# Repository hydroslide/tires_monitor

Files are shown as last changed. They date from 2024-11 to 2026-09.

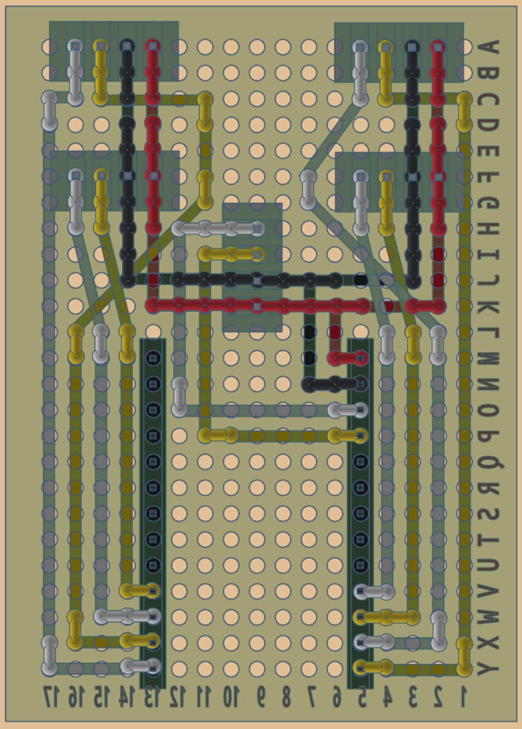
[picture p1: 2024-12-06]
circuits/i2c bottom.JPG

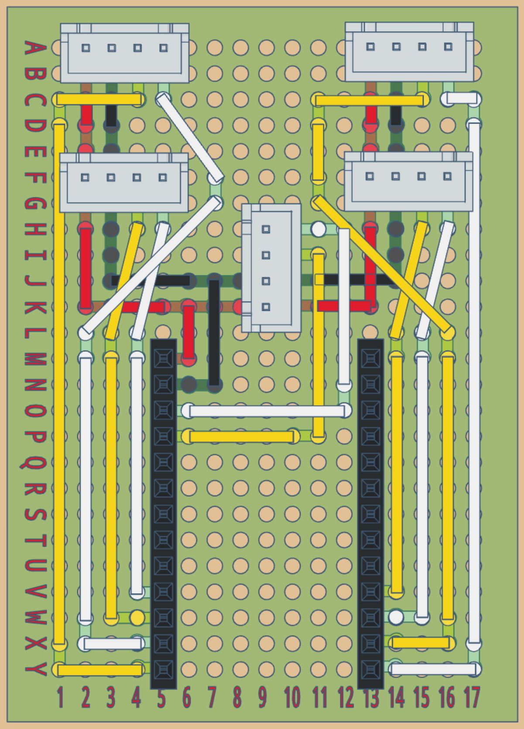
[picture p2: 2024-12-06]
circuits/i2c top.JPG

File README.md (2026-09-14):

# Tire Temperature Monitoring System

A real-time tire temperature monitoring system for performance vehicles that displays the temperature of each tire on an LCD screen using infrared temperature sensors.

## Overview

This project provides a complete solution for monitoring tire temperatures in performance driving or racing applications. It uses non-contact infrared temperature sensors (MLX90614) to measure tire temperatures and displays them on an LCD screen with color-coding based on configurable temperature thresholds.

## Features

- Real-time monitoring of all four tire temperatures
- Color-coded temperature display:
  - Blue: Cold tires (below minimum temperature)
  - Green: Normal operating temperature
  - Purple: Ideal temperature range
  - Red: Overheated tires
- Two modes: Street and Track, with different temperature thresholds
- Straight-line capture gating from the onboard IMU, with a live lateral-g bar between the
  tire rows showing the gate zone, current lateral g, and whether it's capturing
- Support for both Fahrenheit and Celsius temperature scales
- Night mode with configurable brightness (activated by right swipe gesture)
- Touch interface for menu navigation
- Configuration menu for temperature ranges, display settings, and sensor mapping
- Settings stored in EEPROM for persistence between power cycles
- Wireless communication via WiFi (ESP32 version) or Bluetooth (modular version)
- Test mode for display demonstration
- 3D printable enclosures and mounting options

## Hardware Components

- Microcontroller:
  - Waveshare ESP32-S3 Touch LCD 1.69" development board (tires_esp32 version)
    - ESP32-S3 dual-core microcontroller
    - 1.69" round LCD display (240×280 resolution) with ST7789 driver
    - Built-in CST816S capacitive touch controller with gesture support
    - 8MB PSRAM and 16MB Flash memory
    - USB Type-C interface for programming and power
    - WiFi and Bluetooth connectivity
    - I2C, SPI, and GPIO interfaces
    - Compact round form factor ideal for the project
  - Arduino/ATmega (tires_modular version)
- MLX90614 Infrared Temperature Sensors (one per tire)
- TCA9548A I2C Multiplexer (for managing multiple sensors)
- 3D printed enclosures (designs included in the 3d_parts folder)

## Directory Structure

- `/tires_esp32` - **Main implementation** using ESP32 with touch interface and WiFi
- `/docs` - Dev environment setup and build/flash guides
- `/scripts` - `tm.sh` / `tm.ps1` build helpers (compile, flash, monitor, diagnose)
- `/3d_parts` - 3D printable files for enclosures and mounting hardware
- `/circuits` - Circuit diagrams and PCB designs
- `/esp32_i2c_scanner` - I2C scanner for this board; use it to debug the sensor bus
- `/i2c_scanner` - Generic Arduino I2C scanner
- `/menu_test` - Test sketch for menu system
- `/tires_modular` - Older/simplified implementation for Arduino with Bluetooth
- `/wifi_test` - Test sketch for WiFi functionality

## Setup and Installation

### Hardware Setup

1. Assemble the hardware components according to the circuit diagrams in the `/circuits` folder.
2. Connect the MLX90614 sensors to the TCA9548A I2C multiplexer.
3. Connect the ST7789 display via SPI.
4. For ESP32 version, connect the CST816 touch controller via I2C.
5. Print and assemble the enclosures from the 3D models in the `/3d_parts/final parts` folder.

### Software Setup

#### ESP32 Version (main firmware)

Development happens in **VS Code** using `arduino-cli`. The Arduino IDE is not required.

| Guide | For |
|---|---|
| **[docs/DEV-SETUP-MACOS.md](docs/DEV-SETUP-MACOS.md)** | First-time setup on a Mac |
| **[docs/DEV-SETUP-WINDOWS.md](docs/DEV-SETUP-WINDOWS.md)** | First-time setup on Windows |
| **[docs/BUILD-AND-FLASH.md](docs/BUILD-AND-FLASH.md)** | The daily build/flash/monitor loop |
| **[docs/SETTINGS.md](docs/SETTINGS.md)** | Every menu setting — what it does, default, range, how to tune it |
| **[docs/tire-temp-functional-design.md](docs/tire-temp-functional-design.md)** | Why the tire-temp maths works the way it does (findings + amendments) |

Short version, once set up:

```bash
./scripts/tm.sh flash      # compile + upload   (~1 min)
./scripts/tm.sh monitor    # watch serial output
```

Windows: `.\scripts\tm.ps1 <same>`. Or use the status-bar buttons / `Cmd+Shift+B` in
VS Code.

The flash is verbose by default — it prints which binary it is writing and the full
esptool exchange, because that is what tells you *why* an upload failed. Turn it down
with `TM_VERBOSE=0`, or all the way up with `TM_VERBOSE=2`
([details](docs/BUILD-AND-FLASH.md#how-much-the-flash-tells-you--tm_verbose)).

Core and library versions are pinned in
[`tires_esp32/sketch.yaml`](tires_esp32/sketch.yaml) and installed automatically on the
first build — there is nothing to click through in a Library Manager. For reference, the
firmware depends on:

- ESP32 Arduino core 3.0.7 (bundles `Wire`, `SPI`, `EEPROM`, `WiFi`)
- Adafruit GFX Library, Adafruit ST7735 and ST7789 Library, Adafruit BusIO
- Adafruit MLX90614 Library (spot IR sensors), Adafruit MLX90640 (thermal cameras)
- GFX Library for Arduino
- CST816_TouchLib — supplies `CST816Touch_SWMode`, which is a class in that library, not
  a library of its own

WiFi credentials are `#define`d at the top of `tires_esp32.ino`.

#### Modular Version

1. Install the Arduino IDE.
2. Install the following libraries:
   - Adafruit_GFX
   - Adafruit_ST7789
   - Adafruit_MLX90614
   - Wire
   - SPI
   - SoftwareSerial (for Bluetooth communication)
3. Open the `tires_modular.ino` sketch in the Arduino IDE.
4. Upload the sketch to your Arduino board.

## Configuration

The system can be configured through the touch interface menu. Swipe left to access the menu and use swipe up/down gestures to navigate. Swipe left to activate a setting. Swipe up/down to increase/decrease values. Swipe right to exit the setting:

The root menu is nine items and fits the screen without scrolling. Menus are named for what
they do rather than the hardware they use, so each one groups a whole feature:

1. **Current Mode**: Choose between Street and Track modes
2. **Current Tire**: The active tire profile — the same value as `Tire Profiles → Profile`, hoisted so swapping tires is one tap
3. **Temperature**: `Source` (Raw surface vs Calculated carcass) and `Scale` (F/C). Source is a signal switch, not a display one — it changes what the device concludes, not just what it shows
4. **Mode Settings**: **Street Settings** / **Track Settings** — the per-mode default tire profile; Street also carries its own temperature window (`Override Window` + Min/Ideal/Max), and Track adds the balance and session items
5. **Tire Profiles**: The temperature window (Min/Ideal/Max), carcass offset and lag, and per-corner camera crop offsets — the profile supplies the window on Track, and in Street unless Street's `Override Window` is on. Carcass offset, lag and crop always come from the profile, in both modes
6. **Inflation & Camber**: The whole over/under-inflation and camber check in one place — the delta thresholds, the verdict latch, what gets painted, and the **Straight-Line Gate** (capture threshold, gate dwell, axis orientation) that decides which frames count
7. **Display**: Night brightness, thermal image colouring, crop guide overlay, tire redraw rate, and the fisheye **lens correction** (master switch, field of view, letterbox-vs-fit, and the interactive `Set Camera Degrees` tuner) — see [Lens correction](#lens-correction)
8. **Test**: ⚠️ *temporarily* selects the display rendering path — buffered (On) vs direct (Off). See [Display rendering](#display-rendering) below. Normally: enable the raw thermal-camera image views
9. **Save Config**: Save current settings to EEPROM

Every setting is documented — what it does, its range, and how to tune it — in
[docs/SETTINGS.md](docs/SETTINGS.md).

To activate night mode, swipe right on the main display.

### Main display views

Swiping **up/down** on the main display cycles what it shows. With the camera-image views on
(currently always — see [Display rendering](#display-rendering)) there are three states: the
tire map alone, the four live camera images, and the camera images with each tire's
temperatures drawn over the top.

**Which of those the display starts in is decided by `Current Mode`**, at boot and every time
you close the menu:

| Mode | Starts in | Why |
|---|---|---|
| **Street** | camera images with the temperatures overlaid | You're looking *at* the tires — the picture is the point, and the numbers ride along on top. Falls back to the tire map if no corner has a camera fitted, since there'd be nothing to show. |
| **Track** | the tire map alone | You're reading numbers between corners. The camera images are detail you have no time for at speed. |

This only sets the starting point. A swipe still moves the view anywhere it could before, and
that choice stands until the next time the display is rebuilt.

Sensor detection resolves a moment *after* the display comes up — a fresh `TempReader` assumes
every corner is a camera until `checkTireSensor()` proves otherwise — so on a board with no
cameras Street starts on the camera view and drops back to the tire map within a read pass or
two, once the sensors have owned up. Swiping before that happens takes the view off the
automatic default for good, and it stays where you put it until the next boot or menu close.

### Display rendering

Everything on screen is drawn through a `DisplayBase` interface with two interchangeable
implementations: **buffered** (the frame is composed into a 134 KB off-screen canvas in
PSRAM, then pushed to the panel in one burst — no flicker, no visible partial frames) and
**direct** (straight to the panel, the original behaviour, kept as an escape hatch).

**The `Test` menu item currently picks between them, at runtime, applied when you close the
menu.** That is a temporary staging measure so the two can be compared on the car by eye; it
costs `Test` its normal meaning meanwhile (the camera-image views are pinned on). Once the
buffered path is confirmed on the car, it becomes the default and `Test` goes back to what it
was.

Design notes, the flush map, and the reason the canvas is never cleared between frames are in
[tires_esp32/BufferedDisplay.md](tires_esp32/BufferedDisplay.md). The one rule worth knowing
before touching rendering code: **nothing outside the display classes may hold an
`Adafruit_ST7789&`** — on the buffered path it paints straight to the glass and is wiped by
the next flush, with no compile error.

### Aiming the cameras

The eight per-corner crop offsets decide where each camera's three temperature bands land on
the tread, and they're a pixel aim — you can only set them against the picture. **Tire
Profiles → Offsets → Set Offsets** hands the whole screen to the four live camera images with
their crop guides drawn on top and walks all eight values in one pass: the armed guide blinks,
left/right slides that line under your finger, down/up step through the values, and stepping
off either end raises a pulsing green (keep) or red (discard) border to confirm before you
leave. Corners without a camera are skipped. Edits go into the selected profile; **Save
Config** is still what writes them to EEPROM. Full gesture map in
[docs/SETTINGS.md](docs/SETTINGS.md#setting-offsets-interactively).

### Lens correction

The wide-angle MLX90640 is a ~110° lens, so straight lines bow: a tire reads as an oval and
its circumferential grooves arc like longitude lines on a globe. **That is not only a looks
problem.** The three temperature bands are fixed-width column slices, and fixed columns are
equal slices of *tire* only if the projection is linear across the width — so the
outer-vs-inner comparison behind the camber and inflation verdicts was reading bands that
didn't match the physical thirds of the tread.

Each frame is therefore re-projected to a rectilinear (pinhole) image **at the moment of
capture**, before the medians, the thermal image, NBP or balance see it — so everything
downstream inherits the fix. `Display → Lens Correct` is the master switch, and
`Display → Camera Degrees` (default `110`) is the lens's field of view.

That value is meant to be tuned by eye: **Display → Set Camera Degrees** hands the screen to
the four live camera images and puts the number under your thumb — left/right nudges by a
degree, down/down keeps, up/up discards — so you swipe until the grooves run straight and
parallel. `Display → Fit to View` chooses what happens to the top and bottom rows the
correction has no data for: black bands (off, the honest default) or squashed away to fill
the frame (on). Neither can move a measurement — the band medians only sample the middle
rows, and a boot-time self-test asserts it. Details and the tuning procedure in
[docs/SETTINGS.md](docs/SETTINGS.md#display).

## Debugging Tools

- `i2c_scanner`: Utility to scan and identify I2C devices on the bus
- `wifi_test`: Test the WiFi connection capabilities
- `menu_test`: Test the menu system functionality

## Communication Protocol

The device broadcasts its data over HP Tuners' **Numeric Broadcast Protocol (NBP)** — the
text protocol TrackAddict reads from external devices — on WiFi. Every read cycle
(10 Hz) it sends **one `UPDATEALL` packet carrying every channel it knows**: the twelve
active tire temperatures (`Front Left Tire O/C/I (degF)` …), the twelve raw surface
temperatures (`… Tire Raw …`), the IMU sample, the per-corner inflation
delta/threshold/verdict, the per-band fill and delta colors as integer `0xRRGGBB`
values, and the session-summary channels (−1 until a session is sealed). The packet
always has the same shape because an NBP client fixes its channel list on the first
`UPDATEALL` it sees; the earlier firmware sent each group as its own `UPDATEALL`, so which
columns TrackAddict logged was a race per session.

## License

This project is open source. Please respect all third-party library licenses.

## Contributing

Contributions to improve the tire temperature monitoring system are welcome. Please ensure your code follows the existing style and includes appropriate documentation.

## Credits

This project uses several open-source libraries:
- Adafruit_GFX and Adafruit_ST7789 for display functionality
- Adafruit_MLX90614 for temperature sensing
- CST816Touch_SWMode for touch interface

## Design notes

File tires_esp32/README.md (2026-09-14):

# ESP32 Tire Temperature Monitor

This directory contains the main implementation of the Tire Temperature Monitor system using an ESP32 microcontroller. This version features a touch interface, WiFi connectivity, and an advanced menu system.

## Features

- ESP32-based implementation with full touch interface
- ST7789 LCD display (240x280 pixels) 
- CST816 touch controller for gesture support
- WiFi connectivity for remote monitoring
- Menu system for configuration
- EEPROM storage for persistent settings
- Night mode with configurable brightness
- Support for both Fahrenheit and Celsius temperature scales
- Two modes (Street and Track) with different temperature thresholds

## Hardware Requirements

- Waveshare ESP32-S3 Touch LCD 1.69" development board
  - ESP32-S3 dual-core microcontroller
  - 1.69" round LCD display (240×280 resolution) with ST7789 driver
  - Built-in CST816S capacitive touch controller with gesture support
  - 8MB PSRAM and 16MB Flash memory
  - USB Type-C interface for programming and power
  - WiFi and Bluetooth connectivity
  - I2C, SPI, and GPIO interfaces
  - Compact round form factor that perfectly fits the project needs
- MLX90614 infrared temperature sensors (4x, one for each tire)
- TCA9548A I2C multiplexer (to connect multiple sensors with the same I2C address)
- 3D printed enclosure (see the `/3d_parts` directory)

## Pin Configuration

The pin configuration is defined in the `pin_config.h` file (not shown in the repository listing). Refer to the code for the specific pin assignments.

## Libraries

The following libraries are required:

- Adafruit_GFX
- Adafruit_ST7789
- SPI
- Wire
- EEPROM
- Arduino_GFX_Library
- CST816Touch_SWMode

## Core Files

- `tires_esp32.ino` - Main Arduino sketch file
- `Tire.h/cpp` - Implements individual tire display and behavior
- `Wheels.h/cpp` - Manages the layout of four tires on the display
- `TempReader.h/cpp` - Handles reading temperatures from MLX90614 sensors
- `NBPProtocol.h/cpp` - Numeric Broadcast Protocol (HP Tuners NBP, TrackAddict's device-data format): one `UPDATEALL` per read cycle carrying every channel
- `WifiSerial.h/cpp` - Provides WiFi communication capabilities
- `TireMenu.h/cpp` - Defines menu structure and configuration options
- `MenuSystem.h/cpp` - Implements the menu navigation system
- `MenuRenderer.h/cpp` - Handles drawing the menu on the display
- `TouchMenuHandler.h/cpp` - Processes touch events for menu navigation

## Menu System

The menu system allows configuration of:

1. Mode (Street or Track)
2. Temperature scale (Fahrenheit or Celsius)
3. Temperature thresholds for Street mode
4. Temperature thresholds for Track mode
5. Night mode brightness
6. Temperature sensor mapping for each tire

## WiFi Setup

The system creates its own WiFi access point:
### Incorrect info
- SSID: TireTempMonitor
- Password: esp32
- Port: 8080

## NBP IMU Telemetry

The IMU channels ride in the device's single per-cycle NBP `UPDATEALL` packet
(see the root README), alongside the tire channels, at the 100 ms sensor cadence.
Both the legacy QMI8658C sensor axes and calibrated vehicle-frame channels are
included:

- `Accel X`, `Accel Y`, `Accel Z` in `G`
- `Gyro X`, `Gyro Y`, `Gyro Z` in `deg/s`
- `Longitudinal G` and `Lateral G` in `G`
- `Yaw Rate` in `deg/s`

The packet-header timestamp applies to every channel in the packet. Boot metadata
records the IMU model, output rate, resolved longitudinal/lateral/yaw axes, and
units. Vehicle-frame channels reuse the existing stationary boot calibration and
orientation setting; the raw-axis channels remain unchanged for compatibility.

## Usage

1. Power on the device.
2. Temperatures will be displayed in color-coded format.
3. Swipe left to enter the menu system.
4. Swipe right on the main screen to toggle night mode.
5. Connect to the WiFi access point to access remote monitoring.

## Troubleshooting

If the system is not detecting temperature sensors:
1. Use the `i2c_scanner` sketch to verify sensor connections.
2. Check the I2C multiplexer wiring.
3. Verify the correct sensor indices are configured in the menu.

If the touch interface is not responding:
1. Check the I2C connection to the CST816 controller.
2. Verify the `TP_INT` and `TP_RST` pins are correctly wired.

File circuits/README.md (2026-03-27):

# Circuit Diagrams and PCB Designs

This directory contains circuit diagrams and PCB images for the tire temperature monitoring system.

## Contents

- `i2c bottom.JPG` - Bottom layer of the I2C multiplexer PCB
- `i2c top.JPG` - Top layer of the I2C multiplexer PCB

## I2C Multiplexer Board

The I2C multiplexer board is a critical component of the tire temperature monitoring system, allowing multiple MLX90614 temperature sensors (which share the same I2C address) to be connected to a single microcontroller.

### Features

- Based on the TCA9548A I2C multiplexer chip
- Supports up to 8 I2C devices with the same address
- Breakout headers for each multiplexed channel
- Address selection jumpers
- Power status LED

### Connection Guide

1. **Main I2C Bus** - Connect to the microcontroller's SDA/SCL pins
2. **Channels 0-7** - Connect to the individual MLX90614 temperature sensors
3. **Address Jumpers** - Configure to change the multiplexer's I2C address if needed
4. **Power** - Connect to 3.3V power source

### Implementation Notes

- In the tire temperature monitoring system, typically 4 channels are used (one for each tire)
- Channel mapping can be configured through the menu system in the ESP32 version
- Default sensor mapping in the code:
  - Front Left: Channel 0
  - Front Right: Channel 7
  - Rear Left: Channel 3
  - Rear Right: Channel 4

## PCB Manufacturing

If you need to reproduce the PCB:

1. Use the JPG images as reference
2. Standard 2-layer PCB with FR4 substrate
3. Minimum trace width: 8mil
4. Minimum drill size: 0.3mm

## General Wiring Guidelines

For the complete tire temperature monitoring system:

1. **Power Supply**:
   - ESP32/Arduino: 5V input
   - TCA9548A: 3.3V (use voltage regulator if needed)
   - MLX90614 sensors: 3.3V
   - ST7789 display: 3.3V logic, 5V backlight

2. **I2C Connections**:
   - Connect microcontroller I2C pins to TCA9548A input
   - Connect MLX90614 sensors to TCA9548A outputs
   - Use 4.7kΩ pull-up resistors on SDA/SCL lines

3. **Display Connections**:
   - Connect display via SPI
   - Configure CS, DC, RST pins as defined in the code

4. **Touch Controller** (ESP32 version only):
   - Connect CST816 touch controller via I2C
   - Connect interrupt and reset pins as defined in the code

## Related Files

For more details on the hardware implementation, refer to:
- `/tires_esp32/TempReader.cpp` - Shows how the I2C multiplexer is addressed in code
- `/3d_parts/final parts/I2C Hub Box.stl` - 3D printable enclosure for this PCB

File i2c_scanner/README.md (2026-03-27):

# I2C Scanner Utility

This directory contains a simple utility sketch for scanning and identifying I2C devices connected to your microcontroller. This tool is essential for troubleshooting the tire temperature monitoring system's sensor connections.

## Purpose

The I2C scanner helps with:

1. Verifying that all MLX90614 temperature sensors are properly connected
2. Checking that the TCA9548A I2C multiplexer is working correctly
3. Identifying the addresses of connected I2C devices
4. Troubleshooting connection issues with the CST816 touch controller

## Usage

1. Upload the `i2c_scanner.ino` sketch to your Arduino or ESP32 board.
2. Open the Serial Monitor at 9600 baud.
3. The sketch will scan all possible I2C addresses (1-127) and report any devices found.
4. Found devices will be displayed with their hexadecimal addresses.

## Expected Output for the Tire Temperature System

When connected to the tire temperature monitoring system hardware, you should see:

- The TCA9548A I2C multiplexer (typically at address 0x70)
- If the CST816 touch controller is connected, it should appear (typically at address 0x15)
- When testing with the multiplexer, the MLX90614 temperature sensors may appear at address 0x5A

## Testing with the TCA9548A Multiplexer

To test sensors connected through the multiplexer, you'll need to:

1. Note the addresses found with this scanner
2. Modify the `select_I2C_bus()` function in the `TempReader.cpp` file if necessary
3. Test each multiplexer channel to ensure all sensors are detected

## Troubleshooting

If no devices are detected:
1. Check your wiring connections (SDA/SCL pins)
2. Verify that pull-up resistors are present (typically 4.7kΩ)
3. Ensure devices are properly powered
4. Try a different I2C speed if available

If some devices are missing:
1. Check individual connections
2. Verify that the TCA9548A multiplexer is working
3. Ensure each sensor has a unique address or is on a separate multiplexer channel

## Code Attribution

This I2C scanner is based on commonly shared code with improvements by various contributors. The version history is documented in the comments within the sketch.

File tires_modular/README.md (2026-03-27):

# Modular Tire Temperature Monitor

This directory contains a simplified implementation of the Tire Temperature Monitor system designed for Arduino-based microcontrollers. This version uses Bluetooth for communication and does not include the touch interface or menu system of the ESP32 version.

## Features

- Arduino-based implementation with ST7789 display
- Bluetooth communication via HC-05 module
- MLX90614 infrared temperature sensors
- Fixed temperature thresholds (not configurable without code changes)
- Color-coded temperature display

## Hardware Requirements

- Arduino board (e.g., Uno, Nano, Mega)
- ST7789 LCD display (240x280 pixels)
- HC-05 Bluetooth module
- MLX90614 infrared temperature sensors (4x)
- TCA9548A I2C multiplexer (for connecting multiple sensors)
- 3D printed enclosure (see the `/3d_parts` directory)

## Pin Configuration

- TFT_CS: 10
- TFT_RST: 8
- TFT_DC: 7
- Bluetooth TX: 2
- Bluetooth RX: 3
- I2C: Default pins (SDA/SCL)

## Libraries

The following libraries are required:

- Adafruit_GFX
- Adafruit_ST7789
- SPI
- Wire
- SoftwareSerial (for Bluetooth communication)

## Core Files

- `tires_modular.ino` - Main Arduino sketch file
- `Tire.h/cpp` - Implements individual tire display and behavior
- `Wheels.h/cpp` - Manages the layout of four tires on the display
- `TempReader.h/cpp` - Handles reading temperatures from MLX90614 sensors
- `NBPProtocol.h/cpp` - Implements the Networked Binary Protocol for remote communication

## Default Configuration

This version uses fixed temperature thresholds:
- Minimum temperature: 75°F
- Ideal temperature: 85°F
- Maximum temperature: 100°F
- Temperature scale: Fahrenheit

To modify these values, edit lines 63-64 in `tires_modular.ino`.

## Bluetooth Communication

The HC-05 Bluetooth module should be configured to operate at 9600 baud rate. The system will send temperature data using the NBP protocol, which can be received by compatible applications.

## Usage

1. Power on the device.
2. Temperatures will be displayed in color-coded format.
3. Connect to the device via Bluetooth to receive temperature data.

## Differences from ESP32 Version

- No touch interface
- No configuration menu
- Fixed temperature thresholds
- No WiFi (Bluetooth only)
- No night mode
- Simplified display layout
- No EEPROM configuration storage

## Troubleshooting

If the system is not detecting temperature sensors:
1. Use the `i2c_scanner` sketch to verify sensor connections.
2. Check the I2C multiplexer wiring.

If Bluetooth communication is not working:
1. Verify the HC-05 module is properly configured (AT commands).
2. Check that the SoftwareSerial pins are correctly connected.
3. Test with a simple Bluetooth terminal app to verify connectivity.

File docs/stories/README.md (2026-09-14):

# Story drafts

User stories for the tire-temp monitor redesign, derived from
[`../tire-temp-functional-design.md`](../tire-temp-functional-design.md) and
reconciled against the driver's review notes.

Filed as GitHub issues in `hydroslide/tires_monitor` (labels `todo` + `bug`/`enhancement`).

## Global constraints (apply to every story)

- **Track-mode only — _partially superseded, see below._** As originally written, every feature here was enabled only in the menu's **Track** mode (`currentMode == 1`, via `getCurrentModeValue()`), inert / hidden in **Street**. (This is the Street/Track `currentMode`, *not* the thermal `thermalMode`.) Excluded **07** (bug fixes apply in all modes) and the raw-logging half of **08**.

  **What actually shipped:** the master-switch framing no longer holds. Since **#14** the tire *profile* — not the mode — is the single source of truth for the temp window, K and τ in **both** modes; a mode only names its default profile. Since **#16** the **Raw/Calculated** display works in both modes too. Still genuinely Track-gated: the **inflation indicator**, the **session / balance** swipe features, and boot-metadata mode labelling. Check the code before assuming a feature is Street-inert.
- **UI/UX latitude.** Redesign menu UI/UX as needed, and fix wonky / broken / buggy behavior found along the way — note each such fix in the relevant issue (or file a new one).
- **Calculated everywhere.** When calculated mode (story 03) is enabled, the calculated (offset + smoothed) value is used for **all** temperatures, displays, and decisions system-wide — window/overheat, balance, verdict, summary. Raw is logged as a *separate* diagnostic channel set and never shown. When calculated mode is off, raw is used.
- **Persist & reload all settings.** Every menu setting — including the active tire-profile selection — is saved to EEPROM and reloaded on boot (the standard settings pattern). Any new setting these stories add follows it.
- **No laps on-device.** The device has no concept of laps (that comes from the external data logger). Session stats are whole-session aggregates.

## The slate

| File | Story | Design § | Type |
|---|---|---|---|
| [01](01-session-lifecycle-summary.md) | Session lifecycle + end-of-session summary | §5.3 | feature |
| [02](02-imu-capture-gate-latched-alerts.md) | IMU capture gate + debounced latched alerts | §5.4 | feature |
| [03](03-surface-carcass-calculated-mode.md) | Surface→carcass calculated mode (+ raw mode, always-log-both) | §5.5 | feature |
| [04](04-tire-profiles.md) | Tire profiles (window + K + τ + per-corner baseline) | §5.5 | feature |
| [05](05-fr-lr-thermal-balance.md) | Front/Rear & Left/Right thermal balance | §5.2 | feature |
| [06](06-demote-gate-inflation-verdict.md) | Gate & latch the inflation verdict | §5.1 | feature |
| [07](07-correctness-bugs.md) | Correctness bugs (firmware §3.1) | §3.1 | bug |
| [08](08-nbp-instrumentation-segment-colors.md) | NBP instrumentation channels + segment colors | firmware | feature |

## Suggested order (dependencies, not mandate)

1. **07 — correctness bugs** first. Data-integrity (the C-vs-F filter bug may have
   corrupted logs) and the "byte can't store 0" bug **blocks** the profile baselines.
2. **02 — IMU capture gate**. Foundational; the gate + latched over/under drive 06.
3. **03 — calculated mode** + **04 — tire profiles** together (profiles hold K/τ/baseline).
4. **05 — balance** (uses the calculated working temp).
5. **01 — session summary** (uses window / time-in-window / balance).
6. **06 — gate & latch verdict** (folds into 02's gate + latch).
7. **08 — instrumentation** (can run in parallel; also carries IMU + summary NBP streams).

## Template

Each file: user story · context · functional behavior · menu/settings · acceptance
criteria · implementation notes. Functional level — no code.

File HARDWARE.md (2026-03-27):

# Hardware Configuration Guide

## Main Board: Waveshare ESP32-S3 Touch LCD 1.69"

The tire temperature monitoring system uses the Waveshare ESP32-S3 Touch LCD 1.69" as the main controller board. This compact, all-in-one development board is ideal for this project due to its integrated display, touch controller, and powerful microcontroller.

### Specifications

- **Microcontroller**: ESP32-S3 dual-core processor
- **Display**: 1.69" round LCD (240×280 resolution) with ST7789 driver
- **Touch Controller**: Built-in CST816S capacitive touch controller with gesture support
- **Memory**: 8MB PSRAM and 16MB Flash
- **Connectivity**: WiFi 802.11 b/g/n and Bluetooth 5 (LE)
- **Interface**:
  - USB Type-C for programming and power
  - I2C, SPI, UART interfaces
  - Multiple GPIO pins
- **Power**: 5V via USB-C
- **Form Factor**: Round PCB that perfectly fits the project's 3D printed case

## Temperature Sensors

The system uses MLX90614 non-contact infrared temperature sensors to measure tire temperatures.

### Specifications

- **Type**: MLX90614 Infrared Thermometer
- **Interface**: I2C
- **Temperature Range**: -70°C to 380°C object temperature
- **Accuracy**: ±0.5°C
- **Resolution**: 0.02°C
- **Field of View**: 90° (standard version)
- **Default I2C Address**: 0x5A (all sensors share the same address)
- **Supply Voltage**: 3.3V

### Connection Setup

Since all MLX90614 sensors share the same I2C address (0x5A), a TCA9548A I2C multiplexer is used to connect multiple sensors:

1. All sensors connect to the TCA9548A multiplexer
2. The multiplexer connects to the ESP32-S3 board via I2C
3. Temperature readings are taken sequentially by selecting different channels on the multiplexer

## I2C Multiplexer

### Specifications

- **Type**: TCA9548A 8-channel I2C multiplexer
- **Interface**: I2C
- **Default Address**: 0x70 (configurable via jumpers)
- **Channels**: 8 independent I2C buses
- **Supply Voltage**: 3.3V

### Connection Diagram

```
ESP32-S3 Board (I2C) ---> TCA9548A Multiplexer --+---> MLX90614 (Front Left)
                                                 |
                                                 +---> MLX90614 (Front Right)
                                                 |
                                                 +---> MLX90614 (Rear Left)
                                                 |
                                                 +---> MLX90614 (Rear Right)
```

## Power Requirements

- **ESP32-S3 Board**: 5V via USB-C connector
- **I2C Devices**: 3.3V (provided by the ESP32-S3 board)
- **Total Power Consumption**: ~150mA during normal operation

## Assembly Notes

1. **Display Orientation**: The LCD is oriented in landscape mode (rotation 3 in the code)
2. **Sensor Placement**: Each MLX90614 sensor should be mounted in a position where it has a clear line of sight to the tire sidewall
3. **Wiring**: Use shielded cables for I2C connections to minimize interference
4. **Enclosure**: The 3D printed parts in the `/3d_parts/final parts/` directory are designed specifically for this hardware configuration

## USB Connection

The ESP32-S3 board connects to a computer via USB-C for:
- Programming (uploading code)
- Serial debugging (9600 baud)
- Power supply

## Troubleshooting Hardware Issues

### Common Problems

1. **No Temperature Readings**:
   - Check I2C connections
   - Verify multiplexer address (should be 0x70)
   - Use the `i2c_scanner.ino` utility to detect connected devices

2. **Touch Not Responding**:
   - Check CST816S initialization in the code
   - Verify the touch settings match the display orientation

3. **Display Issues**:
   - Verify SPI connections
   - Check display initialization parameters in the code
   - Ensure proper power supply

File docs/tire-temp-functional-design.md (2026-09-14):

# Tire-Temp Monitor — Functional Design & Findings

**Status:** supersedes the core conclusion of [`tire-temp-algorithm-recommendations.md`](tire-temp-algorithm-recommendations.md).
**Grounded in:** offline analysis of the logged track data — Lime Rock Park June 17 & July 16 2026 (Continental **ECF** 225/40-17, the subject tire) and Thompson Speedway May 21 2026 (Continental **EC02** 205/45-17, the control) — plus a three-front literature review of motorsport tire-temp practice.
**Scope:** what the product should *do* and *show*, and why. Functional/product level, not code.

The recommendations doc hypothesized a uniform **+15 °F center-hot pedestal** pinning every corner to OVER. **The data refutes that.** There is no uniform pedestal; the cross-tread spread the firmware keys on is measuring **cornering load and body roll, not inflation pressure.** This document records what the data actually showed, reconciles the surface-vs-carcass physics, and lays out a functional redesign that points the hardware at what it is genuinely good at: warm-up window, overheating, and thermal balance.

---

## 1. Purpose

The monitor reads four MLX90640 thermal cameras (one per corner), splits each tire into Outer / Center / Inner bands, and today infers over/under-inflation from the center-vs-shoulder temperature spread. The driver reported the **left tires pinning OVER** at Lime Rock and dropped pressure in response — which made the car worse. This document explains why, using the logged data, and specifies the redesign.

Sign convention used throughout (matches `ThreeSectionTire.cpp`):

> **delta = avg(Outer, Inner) − Center.**
> **delta < 0 → center hotter → OVER-inflation. delta > 0 → shoulders hotter → UNDER-inflation.**

---

## 2. Executive summary

- **Everything new is gated to "Track" mode.** The whole redesign activates only when the menu mode is **Track** (`currentMode == 1`); in **Street** mode the new capture, gating, alerts, summary, and calculated-display behavior stay inert and their menu items hidden, so the everyday street display is unchanged.
- **The spread measures LOAD, not pressure.** Under cornering load the left-tire spread balloons to ~−18/−19 °F center-hot; on straights it sits near −3/−6 °F. The verdict tracks how hard the tire is working, not how much air is in it.
- **The OVER pin is a mid-corner body-roll geometry artifact.** As the car rolls and steers, the camera's crop bleeds onto cooler sidewall, manufacturing center-hot that scales with lateral g. It is *opposite* to real load physics (a loaded outside tire should read outer-shoulder-hot).
- **The metric is pressure-blind.** Raising hot pressure 28.5 → 31 psi — a change the driver clearly felt (mushy → good) — moved the spread by **≤0.5 °F**.
- **The device's advice was backwards.** It called the lefts OVER; the tire actually wanted *more* pressure. Acting on it (dropping to 28.5) made the car mushy/slidy.
- **Surface ≠ carcass.** The camera reads skin temperature, which runs **10–40 °F cooler** than the carcass a needle probe reads and spikes/decays far faster. Published windows (e.g. ECF 160–200 °F) are carcass-frame; comparing raw surface numbers to them makes tires look permanently cold — and may hide genuine overheating.
- **Repurpose the tool** for the two things real-time IR uniquely does — **warm-up / operating-window** and **overheat** detection — plus **front/rear & left/right thermal balance**. Demote the live inflation verdict.
- **The IMU lateral-g gate is the mechanism-specific fix.** Because the artifact is tightly coupled to lateral g, suppressing inflation reads while cornering removes ~24 of the −27 °F and leaves the honest ~−3 °F straight-line residual.

---

## 3. What the data showed

Analysis scripts live in the **`tires_data`** repo: `analyze_spread.py`, `analyze_corner_load.py`, `analyze_corner_exit.py` (parser `racerender.py`, lap slicing `isolate_lap.py`). All read the TrackAddict CSV exports, which merge the monitor's NBP tire channels with GPS, lateral g, and speed on one timebase. **RR is excluded everywhere** (unreliable hardware, per the driver).

### 3.1 Straight-line residuals (the honest inflation read)

At the *good* pressure (31 psi), warm, straight, steady frames only:

| Corner | Straight-line delta | Reading |
|---|---|---|
| FL | ≈ −3 °F | ~neutral / very mild center-hot |
| RL | ≈ −6 °F | mild center-hot (its per-corner baseline) |
| FR | ≈ +4 °F | mild shoulder-hot (slightly under) |
| RR | ~0 | discounted (hardware) |

These are modest and mixed — **nothing here says "drop pressure."** And because surface IR over-reports center-hot (§4), the true carcass picture is even more shoulder-biased, i.e. consistent with "31 psi felt good."

### 3.2 Load balloons the spread; pressure does not move it

`analyze_corner_load.py`, split by lateral g (left tires load in right-handers, `Accel Y < −0.6`):

| Corner | Straight | Loaded @ 28.5 | Loaded @ 31 | Move for +2.5 psi |
|---|---|---|---|---|
| FL | −2.5 | −19.5 | −19.0 | **+0.5** |
| RL | −6.5 | −17.5 | −18.0 | **−0.5** |

The load effect is ~15 °F; the pressure effect is ~0.5 °F. The tool is a load gauge.

### 3.3 The firmware verdict, reproduced

`analyze_spread.py` reproduces the device rule exactly (int rounding, 10 %/15 % thresholds) over warm, moving frames:

| Corner | ECF OVER-verdict rate | Note |
|---|---|---|
| FL | ~26–27 % (up to **30 %** on one hot lap) | reads OVER |
| RL | ~28–29 % (up to **38 %** on one hot lap) | reads OVER (worst) |
| FR | OVER 0 %, UNDER 5–6 % | reads the *opposite* of the lefts |

Lime Rock is 6-of-7 right-handers, so the left tires are loaded most of the lap → the OVER verdict is on most of the lap. That is the reported pin, mechanistically explained.

### 3.4 Corner-exit event-triggered average — the artifact isolated

`analyze_corner_exit.py` smooths the (shaky-mount, noisy) lateral-g channel, detects ~75 hard right-hander exits per session, and averages the spread around each exit (t = 0 at exit):

| Phase | t vs exit | FL center-hot delta |
|---|---|---|
| Mid-corner, peak lateral g | −2.2 s | **−27 °F** (max) |
| Straightening | −0.2 s | −15 |
| Exit (g ≈ 0) | +0.2 s | −11 |
| Onto the straight | +0.8 s | −5 |
| Steady straight | +1.5 s | **−3** (baseline) |

Findings:

- The center-hot **peaks mid-corner at peak lateral g and decays monotonically through the exit** to the straight-line baseline ~1.5 s after the car is straight. **There is no exit spike** — the "shoulders shed at exit" transient hypothesis is not what drives it.
- It **tracks lateral g with ~0.5 s lag** → a body-roll/steer geometry artifact (crop bleeding onto sidewall at roll angle), which vanishes when the body returns level.
- It is **opposite to real load physics**: a loaded outside tire should read *outer-shoulder-hot*; reading strong *center*-hot instead is the tell that the measurement is geometrically compromised.
- It is **pressure-independent** (28.5 ≡ 31, both corners, both sessions).
- A small **~1 s tail** after straightening is consistent with camera latency and/or a minor real shoulder-cooling component — so the driver's physical intuition is present, just not dominant.
- **Perception reconciled:** the alert is latched on through most of the corner and releases ~0.2 s after straightening — exactly when the driver first has a moment to glance at the dash. "I only saw it briefly coming out of corners" is real; the *alert* wasn't brief, the *chance to look* was.

### 3.5 Control tire

On the EC02 at Thompson the left-side bias largely disappears (FL −3.5 → −1.5, RL −8 → −2.5; OVER-rate 26–28 % → 2–5 %). Consistent with a tire-specific component, **but confounded by the different track** (Thompson has a different corner balance), so most of the gap is likely load/track rather than tire. Re-run the load split on a like-for-like track before crediting a purely tire-specific pedestal.

---

## 4. Physics: surface vs carcass, and the two-regime rule

Three independent literature threads converge on why a surface camera disagrees with the classic pit-lane needle method.

**Surface ≠ bulk, and grip lives in the bulk.** A needle probe reads compound temperature 3–5 mm down — the hysteretic heat that correlates with grip. IR reads only the skin, which "fluctuates rapidly with dynamic loading" and is *"badly correlated with grip,"* while the core "changes at a much slower rate" ([MegaRide](https://www.megaride.eu/press/tire-thermal-model/); [Izze Racing white paper](https://www.izzeracing.com/ewExternalFiles/Izze_Racing_White_Paper_Tire_Temperature.pdf)). Corner-by-corner spikes are a surface phenomenon the carcass never sees.

**IR reads cooler, edges worst.** Surface IR reads **10–40 °F cooler** than a probe, and *"the edges cool fastest"* ([Speedway Motors](https://www.speedwaymotors.com/the-toolbox/pyrometers-probe-vs-infrared/29996); [Prisma Electronics](https://prismaelectronics.com/blogs/tire-lab/how-to-measure-tire-temperature-in-motorsport-infrared-pyrometer-vs-needle-probe)). This is largely a *timing/cooling* effect: read instantly and statically the two agree to ~0.3 °C, but the shoulders shed heat to the airstream in the seconds after the contact patch — a **built-in center-hot bias** independent of load.

**Roll/steer crop-bleed.** A chassis-mounted sensor cannot see the contact patch; it sees tread that has rotated up and out. Under steer/roll the outer channels *"bleed into the sidewall … when steering angle is applied"* ([Texense](https://www.gomuchfaster.com/products/irn4c-f1-200-c-ir-tire-temp-sensor)), and curved shoulders viewed obliquely read low because directional emissivity falls past ~30–40° off-normal ([Optris](https://optris.com/us/knowledge-library/emissivity/)). This is the mechanism our corner-exit data fingerprinted.

**The two-regime rule (the practical upshot):**

| Regime | Tire state | What the center-vs-shoulder delta means | Trust it? |
|---|---|---|---|
| **Straight / flat / steady** | square, even load | inflation (center-hot = over, both-edges-hot = under) | **Yes** — this is the inflation regime |
| **Mid-corner / rolled** | on the outer edge | camber signal + roll/geometry artifact | **No** — do not read inflation here |

The classic Inner/Center/Outer matrix is confirmed valid ([JOES Racing](https://www.joesracing.com/tires-temperatures/): *"the middle temp is your pressure gauge and the inner-to-outer delta is your camber gauge"*; [949racing/Supermiata](https://949racing.com/supermiata/tech-info/supermiata-using-a-tire-pyrometer/); [Northstar Motorsports](https://northstarmotorsports.com/pages/tech-tips-understanding-tire-temperatures); [Autosport Labs](https://www.autosportlabs.com/using_tire_temperatures_for_better_grip_and_faster_lap_times/)) — **but it is a needle/bulk, tire-read-flat methodology.** Applied to surface IR mid-corner it inverts, which is exactly how the driver got misled.

---

## 5. Functional design

### 5.0 Global constraints (apply to every feature below)

**Track-mode gating.** Every feature in this section is enabled **only in the menu's "Track" mode** (`currentMode == 1`, read via `getCurrentModeValue()`; the other mode is "Street"). In Street mode the new behavior is inert and its menu items hidden or disabled, so the everyday street display is unchanged. **Track mode is the single master switch for this redesign.** (This is the Street/Track `currentMode` — distinct from the thermal-display `thermalMode`, which is a separate setting.)

**UI/UX latitude.** The hand-built menu, touch handling, and display have rough edges. The implementer has explicit latitude to redesign menu UI/UX where it serves these features and to fix wonky, broken, or buggy behavior found along the way — record any such fix in the relevant issue (or file a new one) so it stays tracked.

### 5.1 (a) Inflation verdict — demoted

- **Off by default.** The segment-delta indicator is already a menu toggle; keep it off.
- If used at all: **straight-line-gated** (only computed when the IMU says the car isn't cornering, §5.4), presented as a **between-session hint**, never a live in-corner directive.
- The capability is retained for data/diagnostics, not for telling the driver to change pressure in the moment.

### 5.2 (b) Front/Rear & Left/Right balance

Balance compares each tire's **working temperature** (the smoothed/calculated value of §5.5, not raw spiky surface) across two pairings:

| Pairing | Compare | Interpretation |
|---|---|---|
| **Front / Rear** | avg front vs avg rear | fronts hotter → understeer; rears hotter → oversteer |
| **Left / Right** | avg left vs avg right | expected lopsided at a directional track (Lime Rock loads lefts); flags the *unexpected* (corner-weight, brake bias, one-side abuse) |

- **Show the pair, not just the delta** — absolute levels matter (fronts +15 °F with everything in-window ≠ fronts +15 °F with cold rears).
- **Exclude RR** from the averages so its bad hardware doesn't poison the numbers.
- Primarily a summary/between-session readout; an optional coarse live front/rear bias arrow is a nice-to-have.

### 5.3 (c) Session-end summary

A per-corner recap, menu-accessible, readable while stationary, roughly current font size.

- **Layout:** a 2×2 car map (FL FR / RL RR). Each cell: **peak temp** (large) + **average steady temp** (small) + **time-in-window** (color or tiny bar) + **overheat flag** (exceeded threshold, and roughly how long).
- **Session-level screen:** F/R and L/R balance (§5.2); **warm-up time** (laps/minutes until all four first reached the window).
- **Session lifecycle:**
  - **Start** — menu "Start Session" action (reliable); optional motion auto-start.
  - **End / Seal** — menu action the driver hits **at the start of the cooldown lap**; it freezes accumulation (peaks, averages, balance, time-in-window) at that instant so the cruise back and paddock idle don't dilute the stats or add a fake cooldown tail.
  - **Auto-seal backstop** — seal on sustained low speed / stationary if the driver forgets; optional "trim last N seconds" so a late press still cuts the cruise.
  - **History** — keep the last 1–3 sessions for on-device comparison (e.g. S2 vs S3).

### 5.4 (d) IMU (QMI8658C, 6-axis, I2C)

The board carries an onboard QMI8658C accelerometer + gyro. Dash-mounted, it reads the car's motion — the lateral-g signal we need.

- **Capture gate (the core use):** accumulate the inflation read **only when |lateral g| has been below a threshold for a short capture dwell** (straight and steady, not hard braking, and settled for a moment). Cornering frames are suppressed — that is where the artifact lives. Empirically this strips ~24 of the −27 °F and leaves the honest ~−3 °F baseline. The dwell (#20) exists because a bare threshold test lets the *tail* of a corner through: g drops under the threshold while the car is still unwinding and load is still shifting. It is tunable to `0` to recover the bare-threshold behaviour.
- **Visible gate state (#20):** the gate is otherwise invisible, which makes its settings untunable by observation. A lateral-g bar between the tire rows shows the zone (sized live by the threshold), the current lateral g, and whether the gate is capturing — so threshold, capture dwell, mount noise and boot axis calibration can all be judged on the car. See `docs/SETTINGS.md` → Inflation & Camber → Straight-Line Gate (the menu was called "IMU Gate" until #22).
- **Debounced, latched alerts:** during capture, accumulate signed *evidence* per corner — up while that tire reads centre-hot, down while it reads edge-hot, leaking back toward neutral at 0.75× on frames that read neither. Once a corner's score exceeds a **dwell-time** threshold, raise the alert and **latch** it; sustained contrary or neutral evidence walks it back out. Score saturates at 2× the dwell, and that headroom is the hysteresis. Replaces the flickery per-frame verdict with a stable, physically valid one, and — since #21 — one that names the corner rather than a single global verdict. This latched per-corner verdict is what colours the on-screen segment delta bars.
- **Auxiliary uses:** cornering/braking detection to know which tires are loaded (feeds balance); motion-based session auto-start; stationary auto-seal.
- **One-time orientation calibration:** learn how the box is mounted (sit still = level; drive straight + brake = forward axis), or pick axis/sign in the menu. Coarse is fine — we only need straight-vs-cornering.

### 5.5 (e) Surface → carcass "calculated" mode

The window mismatch (surface reads ~10–40 °F below the carcass-frame spec) is fixed the way the driver proposed.

- **Offset K vs window-shift — equivalent for the decision.** Adding K to the reading or subtracting K from every threshold yields the same in/out-of-window call. **Offset the reading up** for readability (the displayed number becomes comparable to published specs and the driver's mental model). **Store windows in one reference frame (carcass)** so surface numbers are never compared against carcass thresholds — the trap the tool is in today.
- **Smoothing τ = carcass thermal-inertia model.** The carcass is not just hotter, it is *slower*. A low-pass with time constant τ makes the displayed value rise and fall gradually like the carcass, killing the transient "purple" spikes that falsely read as in-window. This is a **better** overheat guard, not a worse one: genuine overheating is *sustained* and survives the filter, while a brief surface spike that doesn't move the smoothed value isn't cooking the carcass.
- **Raw vs Calculated modes (menu):** Raw = honest surface, unsmoothed (bench/debug/data). Calculated = offset + smoothed carcass estimate (driving). **Always log raw** (or raw + the active K/τ) even in calculated mode, so calibration can be re-derived offline — never discard the raw signal.
- **Calibration:** per-profile defaults + an **immediate needle cross-check** to anchor K (probe a tire center the instant you come in, diff against what the camera showed) + an **offline τ fit** from the logs. K drifts with tire/wear/speed/ambient, so it is a profile value, never one magic number.
- **Tire profiles** bundle the tire-specific values: window thresholds, offset K, smoothing τ, and (since #15) the **per-corner camera crop offsets**. Selecting a profile (ECF, EC02, …) swaps all of them at once. This is *why* ECF and EC02 read differently — they are different tires with different windows. *(The per-corner inflation baseline was also bundled here originally; it was removed in #18 — see "Amendments" at the end of this document.)*

---

## 6. Calculated τ and K (from the data)

**Smoothing time-constant τ = 15 s (range 10–20 s).** In "calculated mode" the raw surface center-temp is EMA-low-passed before display so the number behaves like the slower carcass. τ is chosen to kill corner-frequency ripple while preserving the warm-up/cooldown trend. Sweeping τ over the July-S3 log (FL/RL/FR center band, warm & moving, 0.1 s resample) and evaluating a first-order low-pass's analytic gain at a ~10 s corner cycle:

| τ | corner transient kept | warm-up lag |
|---|---|---|
| 5 s | 30 % | 5 s |
| 10 s | 16 % | 10 s |
| **15 s** | **11 %** | **15 s** |
| 20 s | 8 % | 20 s |
| 30 s | 5 % | 30 s |

τ = 15 s knocks the corner ripple to ~11 % of amplitude (no more transient "purple" flashes) while lagging a 60–120 s warm-up by only ~15 s. Below 10 s leaves too much ripple; above 20 s adds real warm-up lag for little gain. Store τ per tire profile so it can be tuned. (Intrinsic surface-cooldown τ couldn't be fit directly — these logs end while still rolling out, so there's no clean cooldown tail, and Intake Air Temp is engine-heat-soaked and unusable as the ambient asymptote.)

**Offset K = +20 °F (default, must be calibrated).** `displayed_carcass_estimate ≈ EMA₁₅(surface) + K`. K is a **literature default only** (surface reads ~10–40 °F below a needle probe; +20 is the midpoint). There is **no carcass ground truth in the logs**, so K must be anchored per tire by an immediate needle-pyrometer cross-check (probe the center hot, within seconds of pit-in; the camera-vs-probe gap at that instant is K). Seed each tire profile at +20 and refine on the first needle session; expect K to drift with tire, wear, speed, and ambient.

Computed by `tires_data/src/fit_tau.py`.

---

## 7. Next Steps

This design will be turned into GitHub stories **interactively, feature by feature**:

1. We walk the backlog (§8) one item at a time.
2. For each, a story body is drafted (problem, behavior, settings, acceptance).
3. **We pause on each story so the driver can tweak details before it is filed** — there are specific tweaks intended per feature, so nothing is filed without a review beat.
4. Stories are created only after that review.

Preconditions and mechanics:

- **`gh` is authenticated** (account `hydroslide`); the interactive story pass can run whenever the driver is ready.
- Stories will be filed as **`tires_monitor` GitHub issues** (firmware repo). GitHub Issues is not yet configured as this repo's tracker — the first pass should set that up (labels/states) before filing.
- The **`tires_data` analysis repo is published** at [`hydroslide/tires_data`](https://github.com/hydroslide/tires_data) (private) — flip to public or rename anytime.
- Story authoring happens in its own pass; the backlog below is the slate, not the filed stories.

---

## 8. Stories / Backlog (to be filled)

Story bodies are written during the interactive Next-Steps pass (§7); this is the candidate slate:

| # | Candidate story | Area |
|---|---|---|
| 1 | Session lifecycle — start / seal-during-cooldown / summary + history | §5.3 |
| 2 | IMU capture gate + debounced latched over/under alerts | §5.4 |
| 3 | Surface→carcass calculated mode (offset K + smoothing τ) + raw mode + always-log-raw | §5.5 |
| 4 | Tire profiles (window thresholds + K + τ + per-corner baseline) | §5.5 |
| 5 | Front/Rear & Left/Right thermal balance readout | §5.2 |
| 6 | Demote/gate the inflation verdict (straight-line-only, between-session) | §5.1 |
| 7 | Correctness bugs — C-vs-F validity-filter comparison, uninitialized `tj` loop var, `initialize()` from base ctor, `anySectionColorChanged` missing return, byte-can't-store-0 EEPROM, integer-division band skew, `draw()` early return, zero-as-no-data in NBP | firmware §3.1 |
| 8 | NBP instrumentation channels + segment colors for the downstream video renderer | firmware |

---

## 9. References & provenance

**Repositories**
- `tires_monitor` — firmware (this repo; branch `pressure-fix`). Classifier in `tires_esp32/ThreeSectionTire.cpp`; band extraction in `tires_esp32/TempReader.cpp`; NBP encoder in `tires_esp32/NBPProtocol.cpp`.
- `tires_data` — offline analysis (separate repo, local). Parser `src/racerender.py`; analyses `src/analyze_spread.py`, `src/analyze_corner_load.py`, `src/analyze_corner_exit.py`; lap slicing `src/isolate_lap.py`; field dictionary `FIELDS.md`; session inventory `data/manifest.yaml`.

**Data set**
- Lime Rock 2026-06-17 (ECF, 4 sessions) and 2026-07-16 (ECF, 3 sessions: S1 mixed/off-transit ~28.5–32, S2 hot 28.5 "mushy/under", S3 hot 31 "good"); Thompson 2026-05-21 (EC02 control). Source CSVs are TrackAddict exports from `~/Documents/RaceRender 3/`.

**Research sources**
- MegaRide tire thermal model — https://www.megaride.eu/press/tire-thermal-model/
- Izze Racing white paper (surface vs core) — https://www.izzeracing.com/ewExternalFiles/Izze_Racing_White_Paper_Tire_Temperature.pdf
- Prisma Electronics (IR vs needle) — https://prismaelectronics.com/blogs/tire-lab/how-to-measure-tire-temperature-in-motorsport-infrared-pyrometer-vs-needle-probe
- Speedway Motors (probe vs infrared) — https://www.speedwaymotors.com/the-toolbox/pyrometers-probe-vs-infrared/29996
- Texense IRN4C-F1 (sidewall bleed under steer) — https://www.gomuchfaster.com/products/irn4c-f1-200-c-ir-tire-temp-sensor
- Optris (directional emissivity) — https://optris.com/us/knowledge-library/emissivity/
- JOES Racing (pressure vs camber gauges) — https://www.joesracing.com/tires-temperatures/
- 949racing / Supermiata (pyrometer use) — https://949racing.com/supermiata/tech-info/supermiata-using-a-tire-pyrometer/
- Northstar Motorsports (temp interpretation) — https://northstarmotorsports.com/pages/tech-tips-understanding-tire-temperatures
- Autosport Labs (using tire temps) — https://www.autosportlabs.com/using_tire_temperatures_for_better_grip_and_faster_lap_times/
- Izze Racing / AiM live systems & display practice; GRM & Miata forums for hot-pressure targets (see conversation research log).

---

## Amendments (post-implementation)

This document records the original design and the data analysis behind it. The findings
above still stand; the items below are where **shipped behavior deliberately diverges**
from what the design proposed. Read these before treating any statement above as current.

### #14 — the tire profile is the single source of truth for the window, in both modes

The design assumed Street and Track each carried their own Min/Ideal/Max. They no longer
do. Each *mode* now names a **default profile** (Street → EC02, Track → ECF) and the active
profile supplies the window, K and τ. The active selection is transient: it is resolved
from the current mode's default at boot and re-snapped on every mode change, and is never
persisted. Seed windows were retuned at the same time: **ECF 120/160/200, EC02 110/140/170**.

> **Partly superseded by #27** — the profile is still the single source of truth for the
> window on **Track**, and for K, τ and crop in *both* modes. Street can now override the
> window. See below.

### #27 — Street takes its window back (Track keeps the profile's)

#14 above was right that two windows for the same tire is redundant — on track. Street is a
different problem and #14 over-generalised. A track window is part of what you are *tuning*,
so it belongs with the tire; a street window is a fixed "are these anywhere near warm"
scale that has to stay put while you swap between profiles that are all tuned for track
heat. Pinning it to a profile left only bad options: edit a profile's window and wreck it
for track use, or keep a decoy "street" profile whose K/τ/crop you did not actually want.

So **Street Settings** regains **Min / Ideal / Max**, defaulting to the pre-#14 Street
window (**40/120/160**, F-seed, unchanged), plus an **Override Window** toggle. With the
toggle on and Current Mode = Street, that window replaces `TireProfiles::active().window*`
everywhere it is consumed. With it off, Street falls back to the profile — exactly the
post-#14 behavior — so the two can be compared without retyping numbers. Track is untouched.

**Only the window moves.** K, τ and the per-corner camera crop offsets still come from the
active profile in both modes, because nothing else carries them — which is why Street's
*Default Profile* still does real work with the override on.

One resolver, `resolveTireWindow()` in the sketch, decides this; both `initializeSystem()`
(thermal thresholds + the `Wheels` tire map) and `sendBootMetadata()` go through it, so the
window NBP reports cannot drift from the one on screen. A session inherits it for free via
`wheels->min/ideal/maxTemp` — though in practice sessions stay Track-only.

### #16 — Calculated display is available in both modes

The design (and the stories' global constraint) treated calculated mode as Track-only.
Since both modes now resolve K and τ from the active profile, the calc path has everything
it needs in Street too, and the mode gate was an artificial restriction. The **Display**
(Raw/Calculated) setting appears under both Street Settings and Track Settings and is one
shared global value, not a per-mode setting.

Still genuinely Track-only: the inflation indicator, the session/balance swipe features,
and boot-metadata mode labelling.

### #18 — the per-corner inflation baseline was removed

§3.1's measured straight-line residuals (FL ≈ −3, RL ≈ −6, FR ≈ +4, RR ~0 at 31 psi) are
**retained as data** — the measurement was sound. What was wrong was promoting them to a
per-profile calibration constant:

- **They are a track fingerprint, not a property of the car.** FL heaviest, RL next, FR
  opposite sign is Lime Rock's load pattern (clockwise; left tyres loaded, FR barely
  worked). Static camber would push FL and FR the *same* direction — these push opposite
  ways. And while §5.4's geometry artifact decays ~1.5 s after the body levels, *heat* does
  not: surface thermal constants run seconds to tens of seconds and Lime Rock's straights
  are short, so "warm, straight, steady" frames there still carry heat from the corner just
  exited. The values do not transfer to another track.
- **The artifact they appeared to correct is already gone on a straight.** Removing it is
  the capture gate's entire job (§5.4); the baseline added nothing on top.
- **There was no way to compute them** — no capture routine, 12 hand-entered numbers
  (4 corners × 3 profiles) derived from one session at one track.
- **The one genuinely static component has a better home.** A camera aimed slightly off, so
  its "center" band is not really tyre center, is real and track-independent — but that is
  an error measured in **pixels**, and #15 gave every profile per-corner crop offsets.
  Correcting it with a degrees-F offset fixes the wrong variable: wrong unit, and it shifts
  only the edge−center *delta* while leaving every displayed band temperature still wrong.

The inflation verdict now uses a plain `edge − center` spread against the Inflation Delta %
threshold, still gated to straight-line frames. **If residual cornering heat later proves to
bias the verdict, the fix is a straight-line dwell** — require N seconds continuously
straight before a frame counts — which is track-independent and needs one global number
rather than twelve per-profile ones, and extends the existing latch dwell.

### #18 — Tire Profiles menu: no `Load` / `Save Prof`

The edit buffer now follows the `Profile` selector automatically, so the manual `Load` step
is gone. It had been papering over a real bug: `MenuValueBinding` has no change-callback, so
changing the selector left the buffer showing the *previous* slot's values, and saving then
wrote them into the newly selected slot. Root **Save Settings** already commits the edit
buffer and writes all three slots, so the profile-only save was a strict subset of it.
`Reset` remains.

### #19 — every profile is live in RAM; one Save persists them all

#18 left switching profiles discarding uncommitted edits, because all the profile menu
fields pointed into a single shared working copy (`g_editProfile`) that had to be reloaded
on each switch. That was wrong: edit A → switch to B → edit B → **Save Settings** silently
lost A.

The working copy is gone. All `PROFILE_COUNT` profiles (63 bytes total) stay resident, and
the menu **re-points its bindings** at the selected slot rather than copying data into a
buffer (`retargetProfileBindings()`, driven by the same selector watcher). Switching a
profile is now purely a change of *view*: it neither discards nor commits anything, each
slot holds its own pending edits, and root **Save Settings** writes every slot at once.

Consequence: profile edits are **live immediately**, and Save Settings controls
*persistence only*. That is the same model every other menu setting already uses (live
globals, written to EEPROM on save), so the profile fields are now consistent with the rest
of the menu rather than special. `TireProfile`'s layout is unchanged, so this needed no
`PROFILE_MAGIC` bump and preserved saved profiles.

### #31 — the three bands are sliced out of a *rectilinear* frame, not the raw one

§5 and §3 describe the Outer / Center / Inner bands as three fixed-width column slices of
the 32×24 camera frame. That is still how the slicing works, but the statement was
incomplete in a way that mattered: **fixed columns are equal slices of *tire* only if the
projection is linear across the width, and on this hardware it is not.**

The MLX90640 in this rig is the wide-angle part — a ~110° × 75° lens, which is nowhere near
rectilinear. Straight lines in the world are not straight in the frame: a tire renders as an
oval and its circumferential grooves bow outward like longitude lines on a globe. Under that
distortion the centre of the frame is angularly compressed and the edges are stretched, so
the three fixed-width column bands were **not** landing on the physical thirds of the tread.
The centre band was reading a wider swathe of tire than it should and the shoulder bands a
narrower one — which biases the `edge − center` spread that the inflation verdict is built
on, and the outer-vs-inner comparison behind the camber call, in a way no amount of crop-
offset aiming can remove. Aiming moves *where* the bands sit; it cannot change the fact that
equal pixel widths were unequal tire widths.

Every frame is now re-projected to a rectilinear (pinhole) image at the moment of capture —
inside `TempReader::readFrame()`, immediately after the horizontal flip and **before**
`getSectionMedians()`, `fillTireFrame()`, or anything else touches it. So the medians, the
thermal image, the NBP channels and the balance readout all derive from a frame in which a
straight line is straight and equal column widths *are* equal slices of tread. One insertion
point; no consumer needed changing.

Two things worth carrying forward:

- **The correction is calibrated, not assumed.** The lens is modelled as an equidistant
  (`f-theta`) fisheye whose field of view spans the 32-pixel width, and that field of view is
  a menu setting (`Display → Camera Degrees`, default 110°) with an interactive on-car tuning
  mode, because the real lens is not exactly equidistant and the datasheet figure is not
  exactly what the optics do. The number is found by swiping until the grooves look straight.
  See [`SETTINGS.md`](SETTINGS.md#display).
- **Preserving the horizontal field of view was a deliberate constraint, not a convenience.**
  The re-projection keeps the left and right edges viewing the same angles they always did
  (the scale works out to exactly 1.0 there), which is what allows the eight per-corner crop
  offsets from #15 to survive the change. Any other framing choice would have silently
  invalidated all of them, on every profile — and those are a hand-aimed calibration with a
  whole interactive mode built to set them.

The cost is confined to the top and bottom rows, which want scene content from beyond what
the sensor captured; they are either painted black or squashed away depending on
`Display → Fit to View`. Neither outcome can reach a measurement: `getSectionMedians()` reads
**rows 10–12 only**, and a boot-time self-test (`TempReader::lensSelfTest()`) asserts that no
invalid pixel lands in those rows at any field of view the menu can reach, in either mode.

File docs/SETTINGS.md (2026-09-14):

# Settings reference

Every menu setting on the device: what it is, where it lives, its default and range, **what
it's for**, and how to tune it. If you can't remember why a setting exists, this is the file
to read — the design rationale behind the tire-temp maths lives in
[`tire-temp-functional-design.md`](tire-temp-functional-design.md).

Kept current as part of finishing a feature (see `CLAUDE.md`) — if you change a setting in
firmware, change the row here in the same commit.

---

## How settings are stored

**Edits take effect immediately; `Save Config` makes them survive a reboot.** Every setting
is a live variable the menu writes straight into. The root-level **`Save Config`** item is
what writes them to EEPROM. Change something, back out of the menu, and it applies right
away — but power-cycle without saving and it reverts.

`Save Config` writes **everything at once**: all the menu settings *and* all three tire
profiles. You can edit profile A, switch to B, edit B, then save once and both persist.

Two independent "have these ever been written" magic bytes guard the EEPROM. **When either
is bumped in firmware, that whole group resets to defaults on the next boot** — this is
deliberate, and it's why a flash sometimes wipes your settings:

| Group | Magic | Bumped when |
|---|---|---|
| Menu settings | `SETTINGS_MAGIC`, currently `0xAA` | a setting moves address or changes meaning, **or a new setting claims an address no earlier firmware wrote** |
| Tire profiles | `PROFILE_MAGIC`, currently `0x5D` | the `TireProfile` struct layout changes |

> `SETTINGS_MAGIC` went `0xA7` → `0xA8` in #20, which added *Gate Dwl 0.1s* and *Show G Bar*
> at EEPROM 32 and 33. Those addresses were never written by earlier firmware, and the
> loader copies stored bytes in **without range-clamping** — so a stale `0xFF` at 32 would
> have loaded as a 25.5 s capture dwell. The bump forces a clean re-seed instead. **Expect
> every menu setting to reset once on the first boot after that flash.**

> `0xA8` → `0xA9` in #27, which gave Street its own window and claimed the last four bytes
> #14 freed: EEPROM 10, 14, 16 and 18. Same hazard in its most literal form — those bytes
> still hold a *pre-#14* save's `streetMax` / `trackMin` / `trackIdeal` / `trackMax`, so
> without the bump a stale `trackMax = 180` at 18 would have loaded as *Override Window =
> On* and a stale `trackMin = 100` at 14 as the Street *Ideal*: plausible-looking numbers
> nobody typed. **Expect every menu setting to reset once on the first boot after that
> flash.**

> `0xA9` → `0xAA` in #31, which added the three lens-correction settings at EEPROM 34, 35
> and 36. Same hazard, but here the stale byte is *actively dangerous* rather than merely
> wrong: an uncleared `0xFF` at 34 loads as a **255° field of view**, and the re-projection
> degenerates as the field of view approaches 180°. The bump forces a clean re-seed.
> **Expect every menu setting to reset once on the first boot after that flash.**

> **#22 did not bump it.** The menu restructure moved and renamed a lot of items, but an
> EEPROM address lives on the *binding*, not on the item's position in the tree — so
> re-parenting a setting moves nothing, and every saved value survived. Deleting the dead
> *Temp Sensor Indices* simply dropped addresses 20/22/24/26 out of the save/load tree walk;
> the stale bytes are inert because nothing reads them.

**The active tire profile is deliberately not saved.** On boot it's set to the current
mode's *Default Profile*. See [Tire Profiles](#tire-profiles).

---

## Root menu

Nine items against a nine-row viewport — it fills the screen exactly and does not scroll.
That leaves **no headroom**: a tenth root item brings the scrollbar back, so anything added
later has to displace something or nest.

Everything here is grouped on one rule, adopted in #22: **no menu is named after the
hardware it happens to use.** That is why `Camera Settings`, `IMU Gate` and
`Hardware Settings` no longer exist — two of them held settings that had nothing to do with
the named part, and the third held nothing that worked.

| Setting | Default | Range | What it's for |
|---|---|---|---|
| **Current Mode** | `Street` | Street / Track | Master mode switch. Selects which *Default Profile* is adopted, and enables the Track-only features (straight-line capture gating and the per-tire inflation verdict, session recording, balance readout). Changing it immediately re-snaps the active tire profile. It also decides **which temperature window is in force**: Track always uses the active profile's, Street uses its own if `Street Settings → Override Window` is on. Finally it picks **which view the main screen starts in** — Street starts on the camera images with the temperatures over the top (when a camera is fitted), Track on the tire map alone. That applies at boot and every time you close the menu; swipe up/down still moves the view from there. |
| **Current Tire** | mode's default | slot 0–2 | The active tire profile, hoisted to the root so swapping tires is one tap. **This is the same value as `Tire Profiles → Profile`** — the two items share one binding, so setting either moves both. Not persisted; see [Tire Profiles](#tire-profiles). |
| **Test** | `On` | On / Off | ⚠️ **Temporarily repurposed (#28): this selects the display rendering path.** `On` = buffered (the frame is composed off-screen and pushed in one burst — no flicker); `Off` = the original direct-to-screen path. No reflash needed; the switch applies when you close the menu. The camera-image views it used to gate are **pinned on** meanwhile, so the swipe-cycled display always has 3 states rather than 4. This is a staging measure so the two rendering paths can be compared on the car by eye — **Phase 2 decouples them, makes buffered the default, and restores the original meaning below.** <br><br>_Original meaning (returns in Phase 2):_ enables the raw **thermal-camera image** views. With it on the swipe-cycled display has 3 states (off, or all four camera images live); with it off there are 4 that cycle none → lower pair → upper pair → all four. Primarily a bench/diagnostic aid for checking a camera is aimed and reading sensibly. |

Plus the submenus below — `Temperature`, `Mode Settings`, `Tire Profiles`,
`Inflation & Camber`, `Display` — and **`Save Config`**
(see [How settings are stored](#how-settings-are-stored)).

---

## Temperature

The two global decisions about what a temperature number *is*: which signal it comes from,
and which unit it's printed in.

| Setting | Default | Range | What it's for |
|---|---|---|---|
| **Source** | `Raw` | Raw / Calculated | `Raw` gives the honest measured **surface** temperature. `Calculated` gives the estimated **carcass** temperature — the surface reading smoothed by *Carcass Lag* and offset by *Carcass Offset*. Use Calculated for driving (it's what the window thresholds are authored against); Raw for bench work and diagnosing the sensors. |
| **Scale** | `F` | F / C | Display units. Profile windows and Carcass Offset are authored in °F and converted for display, so switching scale doesn't require re-tuning a profile. Buried here because it's set once and never touched again. |

> **`Source` is not a display setting**, which is why it isn't under `Display`. Per
> `TempReader.h`, Calculated mode **replaces** the working section temps
> (`tireSectionTemps` / `tireTemps`) with `EMA_tau(surface) + K`, so *every downstream
> display **and decision*** runs on the carcass estimate — the inflation/camber verdict, the
> balance readout, session recording, the tile colour bands, and the primary NBP channels.
> Only the raw surface medians kept for the diagnostic channel set are untouched. Picking
> Raw vs Calculated changes what the device *concludes*, not just what it shows.

> It is also **one global byte, not a per-mode setting.** Until #22 it appeared as
> "Display" inside both Street Settings and Track Settings, which read as two independent
> per-mode values; it was always one. (It was *once* genuinely gated on Track mode — #16
> removed that, because a Calculated pick made in Street was being silently ignored.)

> **Note:** in Raw mode the displayed number is a *surface* temperature but the profile
> window is authored in the *carcass* frame, so tires will read roughly one Carcass Offset
> (~20 °F) colder than the window expects. That's inherent to Raw, not a bug.

---

## Mode Settings

Wraps the two per-mode screens. Street carries its own temperature window; Track adds the
session tooling.

| Setting | Menu | Default | Range | What it's for |
|---|---|---|---|---|
| **Default Profile** | both | Street → `EC02`, Track → `ECF` | any profile slot | The tire profile this mode adopts. Selecting a mode snaps the active profile to its default — this is how switching Street↔Track swaps the whole temperature window in one move. A manual pick in `Current Tire` or `Tire Profiles` overrides it until the next mode change or reboot. **Still matters in Street even with `Override Window` on**, because the profile is the only thing carrying Carcass Offset, Carcass Lag and the camera crop offsets. |
| **Override Window** | Street | `On` | On / Off | Whether Street uses its own `Min`/`Ideal`/`Max` below instead of the active profile's window. Off falls straight back to the profile — the post-#14 behavior — so you can A/B the two without retyping numbers. Track has no equivalent: on track the profile *is* the window. |
| **Min · Ideal · Max** | Street | `40` / `120` / `160` | 0–255 °F-seed | Street's tire temperature window, applied when `Override Window` is on. Same convention as the profile window: authored as Fahrenheit and converted for display per `Temperature → Scale`. Street is a different problem from track — it's a "are these anywhere near warm" scale, not a tuning target, and it needs to stay put while you swap between profiles that are all tuned for track heat. Pinning it to a profile meant either wrecking that profile's window for track use or keeping a decoy profile whose Carcass Offset/Lag you didn't want. Ordering (`min ≤ ideal ≤ max`) is enforced downstream by the display, not here. |
| **Show Balance** | Track | `On` | On / Off | Whether the `Balance` readout below will open. Off makes the item report that it's hidden instead. |
| **Balance** | Track | — | action | Opens the front/rear and left/right thermal balance readout. |
| **View Summary** | Track | — | action | Re-opens the last sealed session summary. |
| **Auto-Seal** | Track | `Off` | On / Off | Automatically ends (seals) a running session after a sustained stationary period — a backstop for forgetting to swipe to end. Defaults off because it detects stillness from the IMU only (there's no speed input), so it's best-effort and can fire while you're sitting in the paddock. |

---

## Inflation & Camber

**One feature, one menu.** Deciding whether a tire is over/under-inflated or running bad
camber is a single pipeline — thresholds → straight-line gate → latch → paint it — but until
#22 six of its settings lived under `IMU Gate` and three under `Camera Settings`, and not
one of those three had anything to do with a camera.

Named for the two calls it distinguishes: **edge-vs-centre** divergence is an inflation
verdict, **outer-vs-inner** is a camber one. What you actually tune sits on this screen; the
gate mechanics nest one level below.

| Setting | Default | Range | What it's for |
|---|---|---|---|
| **Segment Deltas** | `Off` | On / Off | Paints per-band verdict colour bars under each tire, showing which band tripped the inflation or camber check. Since #21 the **inflation** verdict painted here is the gate's *latched, straight-line-only* one — it no longer flickers through corners — while the alignment fallback stays instantaneous. A diagnostic overlay: the colours are always computed and always logged over NBP, this only controls whether they're painted. |
| **Show G Bar** | `On` | On / Off | Paints the live lateral-g test bar in the gap between the front and rear tires, plus the per-tire dwell bars (both described below). It's how you tune everything else in this menu, and how you confirm the boot calibration was good. Costs a sliver of screen and nothing else — leave it on unless you want the cleanest possible display. |
| **Inflation Delta %** | `10` | 0–16 % | How far **edge-vs-centre** must diverge before a tire is called over/under-inflated. The comparison is `avg(outer, inner)` vs `centre`, and the threshold is this percent *of the edge temperature* (so ~16 °F at a 160 °F edge). **Lower = more sensitive**, more false calls; higher = only flags gross deviations. |
| **Alignment Delta %** | `15` | 0–16 % | How far **outer-vs-inner shoulder** must diverge before it's flagged as an alignment (camber) issue rather than a pressure one. Same percent-of-edge basis. **Only evaluated if the inflation check didn't already trip** — inflation takes priority. Note the default of 15 sits near the 16 ceiling, so it's currently a fairly insensitive check. |
| **Latch 0.1s** | `25` (2.5 s) | 5–100 (0.5–10 s) | How long the over/under condition must persist **on already-captured frames** before the verdict latches. Stops the verdict flickering on brief noise. **Higher = steadier but slower to react.** Called *Dwell 0.1s* before #22. Unrelated to *Gate Dwell* below — see the warning there. |

### Straight-Line Gate

Called `IMU Gate` before #22 — renamed off the chip and onto the job it does. The onboard
6-axis IMU (QMI8658C) suppresses tire judgements while cornering. This exists because the
mid-corner reading is a body-roll artifact — the camera crop bleeds onto the sidewall at
roll angle, manufacturing a fake centre-hot that scales with lateral g and is *opposite* to
real load physics. Gating to straight-line frames removes roughly 24 of the 27 °F of that
artifact. Full analysis in the design doc §5.4.

These four decide which frames are allowed to count at all, so they gate the **input** to
the verdict. They're set-up values — `Orientation` especially — rather than things tuned
between sessions, which is why they sit below the thresholds rather than beside them.

> **The two dwells are still not the same thing**, and since #22 they're on separate screens
> with names that say so. **`Gate Dwell`** (here) decides when capture **starts** — how long
> the car must hold lateral g inside the zone before its readings count at all.
> **`Latch`** (parent screen) decides when a verdict **trips**, measured only over frames
> already being captured. One gates the input, the other debounces the output.

| Setting | Default | Range | What it's for |
|---|---|---|---|
| **Gate Enable** | `On` | On / Off | Master switch for straight-line gating. Off means inflation reads accumulate everywhere, including mid-corner — which is what produced the original backwards verdict. Leave on. |
| **Lateral cg** | `35` (0.35 g) | 10–100 (0.10–1.00 g) | Lateral-g threshold below which the car counts as "straight and steady" and readings are accepted. **Lower = stricter**, fewer but cleaner frames; higher lets more cornering contamination back in. Raise it only if you're getting too few captured frames to be useful. With the G Bar on, this is the width of the centre segment — turn it and watch the segment resize. |
| **Gate Dwell 0.1s** | `5` (0.5 s) | 0–50 (0–5 s) | How long lateral g must stay **inside** the zone before capture begins. Before #20 capture flipped on the instant g dropped below threshold, which let the tail of a corner — still unwinding, load still shifting — count as straight-line data. **`0` reproduces that old instant behaviour**, which makes it easy to A/B on the car. **Higher = cleaner frames, fewer of them.** Called *Gate Dwl 0.1s* before #22. |
| **Orientation** | `Auto` | Auto / X / Y / Z | Which accelerometer axis is the car's lateral axis. `Auto` picks a horizontal axis from the sensed gravity direction, preferring Y (correct for a level dash mount). Force X/Y/Z only if Auto guesses wrong on an unusual mounting angle. **Test it with the G Bar: a hard left and a hard right must push the dot in opposite directions.** |

### The G Bar

A 4 px bar in the gutter between the tire rows, with a white dot riding on it:

```
x 10 ......... 113 | 114 ..... 165 | 166 ......... 269
  RED (40%)        |  centre (20%) |   RED (40%)
                        ( o )  <- current lateral g
```

- **Red flanks** are outside the capture zone; the **centre segment** is inside it. The
  segment is drawn from *Lateral cg*, so it grows and shrinks live as you turn that setting.
  At the default 35 it spans 20 % of the bar. Full-scale deflection is ±1.75 g — derived
  from that 20 % rule, not chosen independently.
- **Centre green** = capturing right now. **Centre yellow** = not capturing, either because
  you're outside the zone or because you're inside it but still serving *Gate Dwl*.
- The dot tracks the same smoothed lateral-g value the gate itself compares against the
  threshold, so **the dot crossing the segment edge is the gate decision**, not a
  visualisation of it. Under heavy cornering the dot pegs at the end of the bar; that's
  intended.

**Calibration check.** The IMU learns its at-rest gravity vector once, at boot, and the car
must be stationary and roughly level for that to be right. With the car stopped, the dot
should sit dead centre. If it doesn't, the unit booted while rolling or on a slope — reboot
at a standstill. There is no in-menu recalibrate; a reboot is the recovery.

**Bench test: tilt it 90°.** Rolling the whole device onto its side swings gravity fully
onto the lateral axis, which is *exactly* 1.0 g of apparent lateral acceleration — a known,
repeatable input, which makes it the best bench check available.

> At ±1.75 g full scale, 1.0 g is `1.0 / 1.75` = **57 % of the way out**, or roughly
> **46 % into the red**. It does **not** peg, and it shouldn't: pegging would prove nothing,
> since every value at or above full scale looks identical. A dot that lands near 57 %
> confirms the scale factor, the bias subtraction and the lateral-axis pick are all correct.
> Tilting the other way must move it the same distance the other side.

A dot that barely moves on a 90° tilt means the IMU isn't being read or `Orientation` picked
the wrong axis. A dot that pegs means the scale is wrong.

**Noise check.** On a steady straight, watch how much the dot wanders. That wander is your
mount noise, and it sets a sensible floor for *Lateral cg* — a threshold below the noise
band will chatter the gate on and off while going straight.

### The per-tire dwell bars

`Show G Bar` also paints a thin centre-origin bar inside each tire tile, showing how much
evidence that corner has built toward an inflation verdict. Each one hugs the edge facing
the g bar — **bottom** of the front tiles, **top** of the rear ones — so all five read as a
single instrument clustered around the centre gutter rather than four strays:

```
|<------------ tile width ------------>|
[        |####|      :      |    |     ]
         ^ latch    centre   ^ latch
   cyan <- UNDER            OVER -> yellow
```

Each corner carries a **signed evidence score** in milliseconds. On captured (straight-line)
frames it grows toward OVER while that tire reads centre-hot and toward UNDER while it reads
edge-hot; a neutral frame leaks it back toward zero at 0.75× rate. Mid-corner the gate stops
feeding it, so the bar **freezes** rather than drifting. Cross a latch tick and the verdict
trips, colouring the segment delta bars above.

Two deliberate asymmetries: an *opposite* reading subtracts at full rate (it is real evidence
the other way) while *neutral* only leaks at 0.75×, and the score saturates at 2× the latch
point. That saturation is the hysteresis — a fully-committed corner needs roughly 1.3× the
dwell of neutral driving before it falls back out, so a verdict can't chatter on and off at
the boundary.

Use them to tune `Latch 0.1s`: if bars slam to a latch on one straight, the dwell is too
short; if they never get there over a whole lap, it's too long or `Inflation Delta %` is set
too tight.

---

## Tire Profiles

A profile bundles all the tire-specific calibration, so changing tires swaps everything at
once instead of re-tuning field by field. Three slots, seeded `ECF` / `EC02` / `Custom`.

**All three profiles are live in memory at all times.** Changing `Profile` only changes
which slot the fields below display and edit — it never discards or commits anything. Edit
several profiles in one visit and a single `Save Config` persists them all.

| Setting | Default | Range | What it's for |
|---|---|---|---|
| **Profile** | mode's default | slot 0–2 | Which profile is active *and* being edited. **Not persisted** — on boot it's the current mode's *Default Profile*. A manual pick holds until the next mode change or reboot. |
| **Name** | `ECF` / `EC02` / `Custom` | 7 chars | Slot name. Also relabels the choices in each mode's *Default Profile* picker. |
| **Min** | ECF 120 · EC02 110 · Custom 100 | 0–255 | Bottom of the operating window — below this the tire is cold / not up to temperature. **Carcass-frame °F.** |
| **Ideal** | ECF 160 · EC02 140 · Custom 160 | 0–255 | Target operating temperature. |
| **Max** | ECF 200 · EC02 170 · Custom 180 | 0–255 | Overheat threshold — above this you're cooking the tire. |
| **Carcass Offset °** | `20` | 0–80 °F | The surface→carcass correction. The camera reads the tire *surface*, which runs 10–40 °F cooler than the carcass a needle probe reads, and the window above is authored in carcass terms. Adding this offset makes the displayed number comparable to published tire specs. **+20 is a literature midpoint, not a measurement** — anchor it per tire by probing a tire centre with a needle pyrometer within seconds of pit-in; the camera-vs-probe gap at that instant is your value. Expect it to drift with tire, wear, speed and ambient. Only applies in `Calculated` display mode. |
| **Carcass Lag s** | `15` | 1–60 s | Smoothing time constant. The carcass isn't just hotter than the surface, it's **slower** — this low-pass makes the displayed value rise and fall like bulk rubber instead of skin, killing brief surface spikes that would otherwise flash as overheating. It's a *better* overheat guard, not a softer one: genuine overheating is sustained and survives the filter. **15 s was fitted from logged data** (knocks corner-frequency ripple to ~11 % while lagging a 60–120 s warm-up by only ~15 s). Useful range 10–20: below 10 leaves ripple, above 20 adds warm-up lag for little gain. Only applies in `Calculated` mode. |
| **Reset** | — | action | Reverts **only the selected slot** to its seeded defaults. Still needs `Save Config` to persist. |

### Offsets

`Tire Profiles → Offsets → <corner> → Left` / `Right`. Per-corner, per-side camera crop, in
thermal-frame pixel columns.

| Setting | Default | Range | What it's for |
|---|---|---|---|
| **Set Offsets** | — | action | **The way these are meant to be set.** Hands the whole screen to the four live camera images with their crop guides drawn on, and walks all eight values in one pass — see [Setting offsets interactively](#setting-offsets-interactively) below. Edits land in the selected profile in RAM; `Save Config` still persists. |
| **Left** / **Right** | `0` | 0–16 columns | How many pixel columns to crop off each side of that corner's camera frame, so the three temperature bands land on actual tread rather than sidewall, wheel or background. **This is where a mis-aimed camera gets corrected** — fixing aim here is right because it also fixes the displayed band temperatures, whereas a temperature fudge would only shift the derived delta. Kept for fine adjustment and for reading back what **Set Offsets** left behind; tuning by hand here needs **Display → Show Offsets** on so you can see the guide lines against the live image. They're per-profile because different tires and mountings want different crops; all three profiles seed identical. |

#### Setting offsets interactively

These eight numbers are a **pixel aim against a camera image**, and the numeric fields above
hide the very image you're aiming. `Set Offsets` fixes that: the menu closes, the four camera
images fill the screen with no tire map, and every crop guide is drawn on top (regardless of
the *Show Offsets* toggle, and always over the **uncropped** frame — a guide drawn on an
already-cropped image tells you nothing).

Exactly one guide is armed at a time, and it **blinks**. That's the only indicator, so the
gestures are worth knowing:

| Swipe | What it does |
|---|---|
| left / right | Slides the **armed** guide the way you swiped. The stored value moves opposite ways on the two guides — both are measured inward from their own edge, so a right offset grows leftward — but on screen the line always follows your finger. Stops at 0 (the image edge) and 16 (mid-image). |
| down | Next value. Order is fixed: FL, FR, RL, RR, and Left before Right within a corner. **Corners with no camera are skipped** — there's nothing to aim there. |
| up | Previous value. |
| down past the last value | **Green border pulses** — you're about to keep. Down again exits to this menu with the edits; up returns to the last value. |
| up past the first value | **Red border pulses** — you're about to discard. Up again exits and restores every offset to what it was on entry; down returns to the first value. |

Keeping means keeping in the **selected profile, in RAM** — exactly like typing into the
numeric fields. Nothing reaches EEPROM until root **Save Config**, so a session of aiming is
still discardable by simply not saving.

---

## Display

Mostly presentation — how bright the screen is, how the thermal image is coloured, whether
the crop guides are drawn over it, and how often the tire display repaints. This is what was
left of `Camera Settings` (#22) once the three verdict settings that were sitting in it moved
to [Inflation & Camber](#inflation--camber), plus `Night Brightness` down from the root.

**The four lens settings (#31) are the exception, and they do change numbers.** They live
here on the same "device-wide, so it lives here" rule that already put `Show Offsets` here
rather than next to the per-profile offset values — the root menu is an exact 9-of-9 fit
against the screen, so a `Camera` root submenu would have to displace something. This menu
is now 8 of 9 rows; the next item added to it should push the four lens settings into a
`Lens` submenu rather than displacing anything.

| Setting | Default | Range | What it's for |
|---|---|---|---|
| **Night Brightness** | `25` | 0–100 % | Screen brightness **while night mode is active** (swipe-toggled) — it does not affect normal daytime brightness. Percent of full backlight. Low enough not to blind you at night, high enough to still read. |
| **Thermal Gradient** | `On` | On / Off | *On* = smooth interpolated colour within each temperature band (finer detail). *Off* = one flat colour per band, so the image posterizes into cold/warm/ideal/hot blocks — easier to read *which band* a region is in at a glance. Preference, not calibration. |
| **Show Offsets** | `On` | On / Off | **This is the crop-tuning toggle, and it changes what the thermal image shows.** *On* = the **full** camera frame with vertical guide lines marking where the crop offsets sit — use this while tuning the offsets so you can see what you're cutting. *Off* = the image is cropped to the region **between** the offsets and stretched to fill the display, which is the real working view. Turn it on to tune, off to drive. It stays here rather than next to the offset values because it is device-wide, while the values are per-profile. |
| **Hi Freq Updates** | `Off` | On / Off | Recomposes the tire numbers and bars every read (~10 Hz) instead of once a second. Smoother, and useful when chasing something transient. With **Test** *On* (the buffered path) the cost is CPU only — the screen is pushed at 10 Hz either way, and this just changes how often the tire map is redrawn into the frame first. With **Test** *Off* it also multiplies SPI traffic, which is the more expensive of the two. |
| **Lens Correct** | `On` | On / Off | **Master switch for the fisheye correction (#31), and it changes measured temperatures — not just the picture.** The wide-angle MLX90640 is a ~110° lens, so straight lines bow: a tire reads as an oval and its circumferential grooves arc like longitude lines. That's not only cosmetic. The three band medians are taken over **fixed-width column bands**, and fixed columns are equal slices of *tire* only if the projection is linear across the width — it isn't, so the outer-vs-inner comparison behind the camber and inflation verdicts was reading bands that didn't match the physical thirds of the tread. *On* re-projects each frame to a rectilinear (pinhole) image at the moment of capture, so the medians, the thermal image, NBP and balance all inherit the fix. *Off* is the raw sensor frame, exactly as it behaved before #31 — keep it for A/B-ing the correction on the car. |
| **Camera Degrees** | `110` | 60–140° | The lens's field of view across the 32-pixel width, fed straight into the correction. `110` is the wide-angle part's datasheet figure and the right place to start, but the real lens isn't exactly an ideal fisheye, so **this is meant to be tuned by eye** — see **Set Camera Degrees** below. Capped at 140 deliberately: the maths degenerates as the field of view approaches 180°, and by 140 the centre of the image is already de-magnified more than 2.2×. |
| **Fit to View** | `Off` | On / Off | What to do with the rows the correction has no data for. Preserving the horizontal field of view (which is what keeps your crop offsets valid) means the corrected top and bottom rows want scene content from **beyond what the sensor captured**. *Off* = letterbox: those pixels are painted **black**, because there is genuinely nothing there and a fabricated value would render as a real reading. *On* = squash the image vertically to fill the frame instead. Lines stay straight either way — an anisotropic squash is an affine map, and affine maps preserve straightness — you only lose aspect ratio. **Neither mode can move a measurement**: the band medians only sample rows 10–12, where toggling this shifts the sampling by 0.012 px at 110° and at most 0.071 px anywhere in range. Defaults *off* so the cost of the correction is visible while you're finding the right **Camera Degrees**. |
| **Set Camera Degrees** | — | action | Opens the interactive tuning mode — the only screen that shows you the picture you're judging. Full-screen four-quadrant live thermal view, uncropped, with the current value drawn in the top margin. **Swipe left/right** = −1/+1°. **Swipe down** = pulsing green border, down again keeps. **Swipe up** = pulsing red border, up again discards and restores the value you entered with. Keeps in RAM only; root **Save Config** is still the only thing that writes EEPROM. Refuses to open (and says so) if no corner has a camera, or if **Lens Correct** is off — tuning a correction that isn't running is swiping at a raw image and wondering why nothing moves. |

### Tuning Camera Degrees on the car

Park where a tire fills a quadrant with its circumferential grooves clearly visible, open
**Set Camera Degrees**, and swipe until **the grooves run straight and parallel** and the
tire outline reads as a rectangle rather than an oval.

- Grooves still **bowing outward** (barrel — the ends curve away from centre) → value is
  **too low**, under-correcting. Swipe right.
- Grooves bowing **inward** (pincushion) → **too high**, over-correcting. Swipe left.
- Straight and parallel → done. Swipe down twice to keep, then root **Save Config**.

**Tune with Fit to View off.** The black bands are the honest running total of what the
correction is spending — 7.8 % of the frame at 110°, 14.6 % at 140° — and they grow as you
raise the value. They cost you nothing measured (the median rows are never in them), but
seeing them is what tells you to prefer the *lowest* value that actually straightens the
grooves. Turn Fit to View on once you've settled.

With Fit to View **on**, the same information shows up as vertical squash instead: the image
renders 0.855× as tall as true rectilinear at 110°, 0.661× at 140°. If the tire starts
looking squat, that's a high **Camera Degrees** being absorbed — not a sign the value is
wrong.

**Re-check the crop offsets afterwards.** The horizontal framing is preserved by
construction, so they should still be close — but "close" isn't "verified," and
[Set Offsets](#offsets) makes confirming them a 30-second job.

---

## Removed settings

Recorded so an old note or screenshot doesn't send you hunting for something that's gone.

| Setting | Was in | Removed | Why |
|---|---|---|---|
| **Temp Sensor Indices** (FL / FR / RL / RR) | Hardware Settings | #22 | Never did anything. Four editable, EEPROM-persisted bytes (20/22/24/26) with **no getter** — nothing in the firmware read them. The real sensor-to-corner mapping is a hardcoded `sensorIndices{0, 7, 3, 4}` in `TempReader`'s constructor, which these never fed. They presented as a working remap and were not one, so the whole `Hardware Settings` branch went with them. The addresses are simply no longer walked by save/load; the stale bytes are inert. |
| **Base FL / FR / RL / RR** | Tire Profiles | #18 | Per-corner inflation baselines. The shipped values encoded one track's load pattern rather than a property of the car, the artifact they appeared to correct is already removed by the straight-line gate, and any genuinely static component is a camera aim error belonging in the crop offsets above. Full reasoning in the design doc's Amendments section. |
| **Load** | Tire Profiles | #18 | Manually pulled the selected slot into the edit buffer. The edit buffer is gone (#19) — the fields now point straight at the live slot, so there's nothing to load. |
| **Save Prof** | Tire Profiles | #18 | Saved only the current profile. `Save Config` already writes all three, and a profile-only save became actively misleading once several profiles can hold pending edits at once. |
| **Track Min · Ideal · Max** | Track Settings | #14 | Track no longer carries its own window; it names a *Default Profile* and the profile supplies the window. On track that's right — the window is part of what you're tuning, and it belongs with the tire. **Street's three came back in #27** (see *Mode Settings*): street isn't a tuning target, and its window has to survive swapping between profiles that are all tuned for track heat. |
| **Inflation** | Track Settings | #21 | Gated the over/under verdict and its top-left badge. The badge is gone — it reported one global verdict, so it could say something was wrong but never which corner, and the per-tire delta bars now carry that verdict on the tire it belongs to. With the latch driving those bars, an off switch left them showing an alignment verdict but no inflation one, which reads as "this tire is fine" rather than "this check is disabled". *Segment Deltas* is the honest visibility control. EEPROM 31 is free again. |
| **Camera offset values** | Camera Settings | #15 | Moved onto the tire profile (Tire Profiles → Offsets) so they swap with the tire. The display toggles stayed global. |

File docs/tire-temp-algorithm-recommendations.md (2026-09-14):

# Tire-Temp Algorithm — Coding & Testing Recommendations

Follow-on to [`tire-temp-pressure-handoff.md`](tire-temp-pressure-handoff.md). That doc framed the problem and ranked hypotheses before anyone had read the firmware. This one is written **after** reading `TempReader.cpp`, `ThreeSectionTire.cpp`, `NBPProtocol.cpp`, `TireMenu.cpp`, and `MenuSystem.cpp`, and it **supersedes the hypothesis ranking in handoff §4**.

Scope: what to change in code, and what to test — offline, on the bench, and at the track. No code has been changed yet.

---

## 1. Corrected framing

The handoff's mental model was "the metric doesn't respond to pressure." The firmware says something sharper.

The classifier ([`ThreeSectionTire.cpp:139-151`](../tires_esp32/ThreeSectionTire.cpp#L139-L151)):

```cpp
float avgEdge = (sectionTemps[outer] + sectionTemps[inner]) / 2.0f;
float delta   = avgEdge - sectionTemps[center];          // +ve = shoulders hot = under
float minInflationDelta = avgEdge * (minInflationDeltaPct / 100.0f);
```

`minInflationDeltaPct` defaults to **10** ([`TireMenu.cpp:52`](../tires_esp32/TireMenu.cpp#L52)), and `avgEdge` is an **absolute °F** temperature. On a 150 °F tire the bar to declare over-inflation is therefore **15 °F of center-hot spread**.

It trips. Persistently. Across a 3 psi swing.

That is not a null result — it is a positive measurement. **The frames genuinely contain ≥15 °F of center-hot spread at every pressure tested.** The failure mode is not "too insensitive to see the signal," it is:

| Component | Magnitude (est.) |
|---|---|
| Structural / thermal pedestal (pressure-independent) | ~15–20 °F center-hot |
| Pressure-driven modulation (28 → 31 psi) | ~3–6 °F |
| Classifier threshold | ~15 °F |

The pedestal alone clears the bar. The pressure term modulates the total but never pulls it back under. The indicator pins to OVER and the real signal is invisible — not absent.

**This is handoff §4 hypothesis 3 (missing calibration baseline), promoted to primary.** The tool is measuring an absolute where it should measure a deviation from a per-tire zero.

---

## 2. Hypothesis ledger (revised)

### Withdrawn — errors in the earlier read of the code

- **"The crop isn't happening / offsets default to 0."** Wrong. [`TempReader.cpp:71-77`](../tires_esp32/TempReader.cpp#L71-L77) walks `leftOffset → COLS-rightOffset` and splits *that* range into thirds. Everything sampled is inside the margins. The source defaults of 0 are irrelevant because EEPROM supplies real per-corner values.
- **"The 3-row strip may drift onto the shoulder."** Wrong, and rotated 90°. Sections split by **column** (left/center/right = inner/center/outer); `useMiddleRows` takes rows 10–12, a **horizontal** strip spanning the tread. Vertical aim error moves the strip *circumferentially*, which is thermally near-uniform. Middle rows are the correct choice.

### Demoted

- **Equal-pixel vs. equal-arc-length thirds (was handoff's top suspect).** `getSectionMedians` returns a **median**, not a mean ([`TempReader.cpp:91`](../tires_esp32/TempReader.cpp#L91)). A 7-column band × 3 rows is ~21 samples; even if the outermost 1–2 columns sit on the roll-off, that is 3–6 of 21 samples in the tail and the median does not move. Arc-length weighting only matters for a mean. **Not worth building unless the bench test in §5.1 says otherwise.**
- **Emissivity at viewing angle (handoff §4.2).** At any sane mount distance the incidence angle across a 225 mm tread is ~20–30°, well inside rubber's flat ε region (falloff starts ~60°). The genuinely oblique pixels at the extreme edge are exactly the minority the median discards. Effectively dead for a roughly-normal mount; only revisit if the camera looks along the tire at a steep angle.

### Live, ranked

1. **Structural crown.** 225/40-17 on a 17x8 is at the narrow end of the tire's rim range. Tread crowns; center carries disproportionate contact pressure at *every* inflation pressure. Pressure-independent by construction.
2. **Lateral shoulder cooling** — *not in the original hypothesis list, and it belongs there.* The shoulder tread abuts the sidewall and bead, which run far cooler and conduct heat laterally out of the tread. The shoulder is also the most air-exposed part of the tread, and by the time it rotates to the sensor it has cooled more than the center. Produces a persistent center-hot **surface** profile largely independent of inflation, scaling with airflow and inversely with ambient. A cool evening session at Lime Rock in a 2400 lb car maximizes it.
3. **Threshold anchor and asymmetry.** Real defects (§3.2), but second-order — they explain ~10% distortions, not a pinned indicator.

Hypotheses 1 and 2 are **not separable from the thermal data alone** — both produce a symmetric, constant, pressure-insensitive center-hot pedestal. Separating them requires the chalk / needle-pyrometer ground truth in §5.3. Fortunately the *fix* is the same for both: subtract a per-tire baseline.

---

## 3. Code recommendations

### 3.1 Correctness bugs — fix regardless of the algorithm outcome

**(a) Fahrenheit compared against Celsius in the validity filter.** [`TempReader.cpp:173-184`](../tires_esp32/TempReader.cpp#L173-L184) converts C→F **in place, band by band**, then validates each band immediately:

```cpp
for (int j = 0; j < 3; j++) {
    float valueF = tireSectionTemps[i][j] * 9.0f / 5.0f + 32.0f;
    if (useFarenheit) tireSectionTemps[i][j] = valueF;
    if (newTempIsInvalid(i, j)) ...
}
```

The cross-band rescue inside `newTempIsInvalid` ([`TempReader.cpp:146-152`](../tires_esp32/TempReader.cpp#L146-L152)) compares band `j` (already °F) against sibling bands that have **not yet been converted** (still °C). At 65 °C / 150 °F that comparison is `|150 − 65| = 85 > MAX_STEP(30)`, so the rescue never fires for bands 0 and 1 but works normally for band 2. Result: **asymmetric rejection rates across the three bands**, worst during warm-up when temps are changing fastest, and a rejected band latches its previous value.

Fix: convert all three bands, *then* validate all three.

**(b) Uninitialized loop variable — undefined behavior.** Same function, [`TempReader.cpp:146`](../tires_esp32/TempReader.cpp#L146):

```cpp
for (int tj; tj<3; tj++){          // tj never initialized
```

Reads stack garbage; if it starts negative, `tireSectionTemps[i][tj]` indexes out of bounds. Should be `int tj = 0`.

**(c) `ThreeSectionTire::initialize()` never runs.** It is invoked from the **base** `Tire` constructor ([`Tire.cpp:12`](../tires_esp32/Tire.cpp#L12)), where the vtable is still `Tire`'s, so the empty `Tire::initialize()` executes instead of the override. `lastDeltaColors[]` and `currentDeltaColors[]` stay uninitialized. Cosmetic (does not touch classification math), but call it from the derived constructor or from the first `draw()`.

**(d) `anySectionColorChanged()` has no `return` on the fall-through path** ([`ThreeSectionTire.cpp:73-78`](../tires_esp32/ThreeSectionTire.cpp#L73-L78)). Currently harmless because nothing calls it. Delete it or fix it.

**(e) A byte setting can never be stored as 0.** [`MenuSystem.cpp:227`](../tires_esp32/MenuSystem.cpp#L227) skips loading any `VALUE_BYTE` whose stored value is 0:

```cpp
if (EEPROM.read(addr) > 0 && EEPROM.read(addr) < 255) { ... }
```

So `minInflationDeltaPct` cannot be zeroed to log raw unthresholded deltas — which is exactly what you want during calibration. Needs a separate "written" sentinel or a magic-byte scheme.

**(f) Uneven bands from integer division.** [`TempReader.cpp:76-77`](../tires_esp32/TempReader.cpp#L76-L77): for a 20-column crop the bands come out **6 / 7 / 7**; for 22, **7 / 7 / 8**. The left band is systematically narrowest. Irrelevant to the inflation metric (both shoulders are averaged) but it **biases the alignment metric**, which compares outer against inner directly. Distribute the remainder symmetrically.

**(g) `draw()` returns early from inside its own loop.** [`ThreeSectionTire.cpp:95-96`](../tires_esp32/ThreeSectionTire.cpp#L95-L96): one out-of-range band aborts the whole tire's redraw *and* the delta bar for that frame, without updating `lastTemps`. Cosmetic, but it means a single glitch frame stalls the display.

**(h) Zero is overloaded as "no data" in the NBP encoder.** [`NBPProtocol.cpp:43`](../tires_esp32/NBPProtocol.cpp#L43): `if (fl.values[1] == 0)` decides between logging one channel or three. A center band that legitimately reads 0 — or that was rejected while `lastTireSectionTemps` was still 0 during startup — silently collapses the tire to a **single** `"Front Left Tire"` channel instead of `O/C/I`. This is both a bug and a **parsing hazard for the dumps**: the channel set changes mid-file. See §4.0(e).
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

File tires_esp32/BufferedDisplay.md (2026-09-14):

# Display abstraction & buffered rendering

> Rewritten on `dev` in #28. `main` still carries the March version, which described a
> refactor that did not happen (it names `DisplayWrapper.h` and `AlternateDisplay.h` as
> renamed/replaced files — neither has ever existed in this repo's history) and omits
> several changes the commit actually made. Trust this copy.

## The problem

`Adafruit_ST7789` draws straight to the panel on every call. A frame here is many calls —
band fills, temperature text, delta bars, dwell bars, four camera blits, the g bar, the
session badge — and each one pushes pixels over SPI as it happens. You see the frame being
assembled: partial repaints, tearing, and visible flicker wherever two components overlap.

## The shape

Three classes and one interface, in `DisplayBase.h`:

| | |
|---|---|
| `DisplayBase` | The interface every rendering component draws through. Inherits `Print`, so `print`/`println` work. |
| `StandardDisplay` | Straight to the glass. The original behaviour, kept as an escape hatch. |
| `BufferedDisplay` | Composes into an off-screen `GFXcanvas16`, pushed by `drawScreen()`. |
| `DisplayProxy` | Forwards to whichever of the two is selected. It is what `display` actually is. |
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

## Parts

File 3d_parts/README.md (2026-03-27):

# 3D Printable Parts

This directory contains STL files for 3D printing enclosures and mounting components for the tire temperature monitoring system.

## Directory Structure

- `final parts/` - Latest production-ready designs
  - `display/` - Enclosures and mounting for the Waveshare ESP32-S3 Touch LCD 1.69"
- `old/` - Previous iterations and obsolete designs
  - `Display/` - Older display module designs
- `src/` - Source files for component design
- `tests/` - Test prints and prototypes

## Components

### Display Module

The display module components are specifically designed for the Waveshare ESP32-S3 Touch LCD 1.69" round development board. These parts create a protective housing and mounting system for the display unit:
- `Tire Temp Display Module 4 back.stl` - Back cover that protects the electronics
- `Tire Temp Display Module 4 front.stl` - Front bezel that secures the 1.69" round LCD
- `Tire Temp Display Module 4 middle.stl` - Middle housing that contains the ESP32-S3 board
- `Tire Temp Display Module high cup thick.stl` - Mounting cup for vehicle installation
- `Tire Temp Display Module nut.stl` - Threaded nut for secure mounting

### Sensor Boxes

These enclosures protect the MLX90614 infrared temperature sensors:
- `Tire Temp Sensor Box protection mk2.stl` - Protective case for the sensor
- `Tire Temp Sensor Lid.stl` - Lid that secures the sensor while allowing temperature readings

### I2C Hub Box

This enclosure houses the TCA9548A I2C multiplexer board:
- `I2C Hub Box.stl` - Main housing for the multiplexer PCB
- `I2C Hub Box lid.stl` - Lid that protects the multiplexer connections

### Power Input Box

Power supply enclosure for 5V regulation:
- `Power Input 5v Box.stl` - Housing for power regulation components
- `Power Input 5v Lid.stl` - Protective lid for the power supply

## Assembly Instructions

1. Insert the Waveshare ESP32-S3 Touch LCD 1.69" board into the `Tire Temp Display Module 4 front.stl` with the screen facing outward.
2. Secure the board in the `Tire Temp Display Module 4 middle.stl` housing.
3. Route the I2C and power wires through the appropriate channels and secure the back panel.
4. For each sensor, place the MLX90614 infrared sensor inside the `Tire Temp Sensor Box protection mk2.stl` and secure with the lid.
5. Mount the TCA9548A I2C multiplexer inside the I2C Hub Box and secure the lid.
6. Assemble the power input box with the appropriate power regulation components if not powering directly via the ESP32-S3's USB-C port.

## Wiring Instructions

The system uses standardized 4-pin connectors for all connections:

1. **ESP32 to Power Supply Box**:
   - Connect a 4-pin wire (5V, GND, SDA, SCL) from the ESP32-S3 board to the power supply box.
   
2. **Power Supply**:
   - The power supply box accepts power via a USB-Mini connector.
   
3. **Power Supply to I2C Multiplexer**:
   - Connect another 4-pin wire from the output of the power supply box to the input of the I2C multiplexer box.
   
4. **I2C Multiplexer to Sensors**:
   - Connect four separate 4-pin wires from the multiplexer box outputs.
   - Each wire routes to one of the four tire temperature sensors.
   - Each wire carries 5V, GND, SDA, and SCL to power and communicate with the MLX90614 sensors.
   
5. **Wire Routing**:
   - Route wires along the vehicle's existing wiring harnesses when possible.
   - Use cable ties or clips to secure wires away from heat sources and moving parts.

## Notes

- The 3D printed parts were designed specifically for the Waveshare ESP32-S3 Touch LCD 1.69" board's round form factor
- Older designs in the `old/` directory are kept for reference but are optimized for different hardware
- The `tests/` directory contains prototype designs that were used during development
- The source files in `src/` can be modified if customization is required

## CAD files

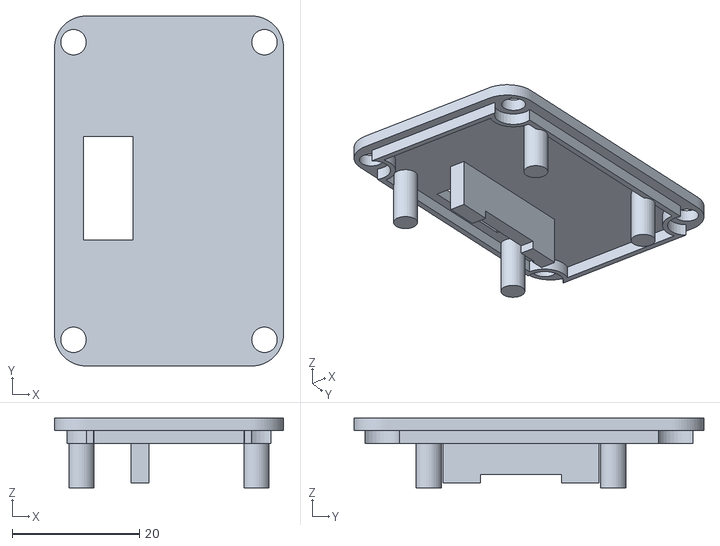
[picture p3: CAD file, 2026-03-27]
3d_parts/final parts/display/Tire Temp Display Module 4 back.stl
36.0 x 55.0 x 11.0

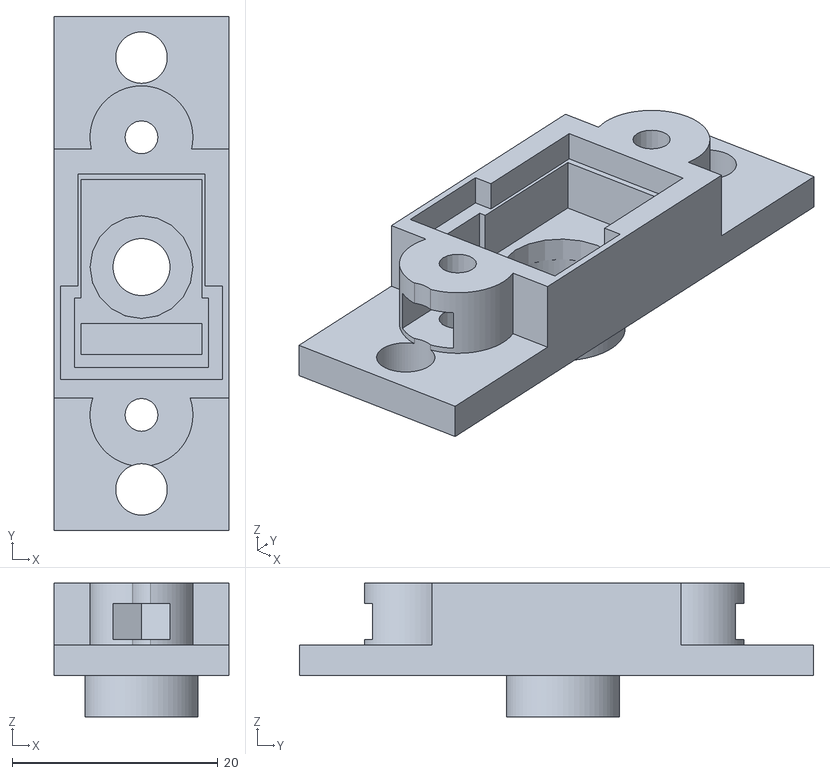
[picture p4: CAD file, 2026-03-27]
3d_parts/final parts/Tire Temp Sensor Box protection mk2.stl
17.0 x 50.0 x 13.0

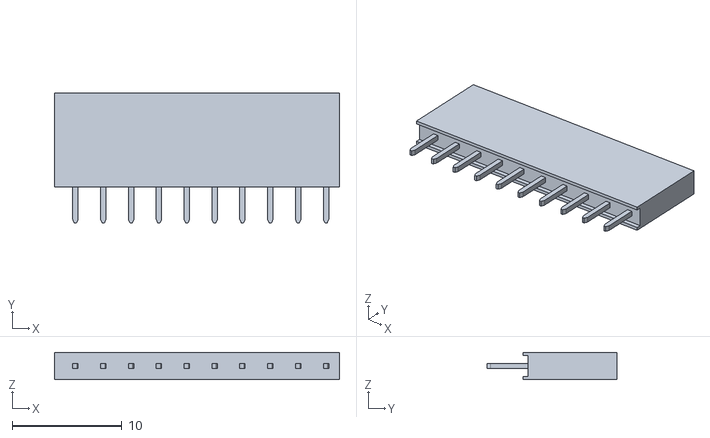
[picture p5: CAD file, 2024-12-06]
3d_parts/src/ImageToStl.com_header female 1x10.stl
26.0 x 11.9 x 2.47

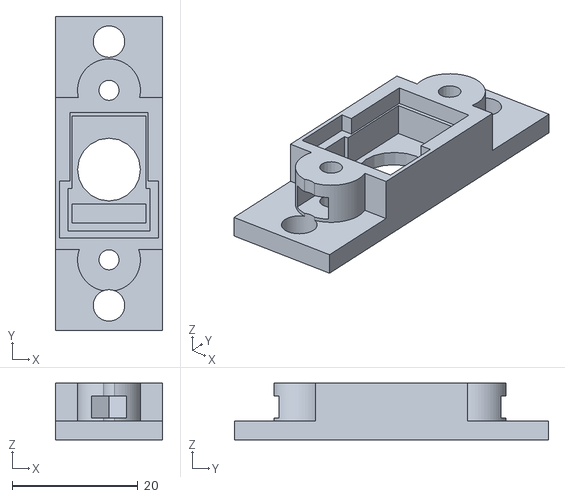
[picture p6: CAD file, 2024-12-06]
3d_parts/tests/sensor box2.stl
17.0 x 50.0 x 9.00

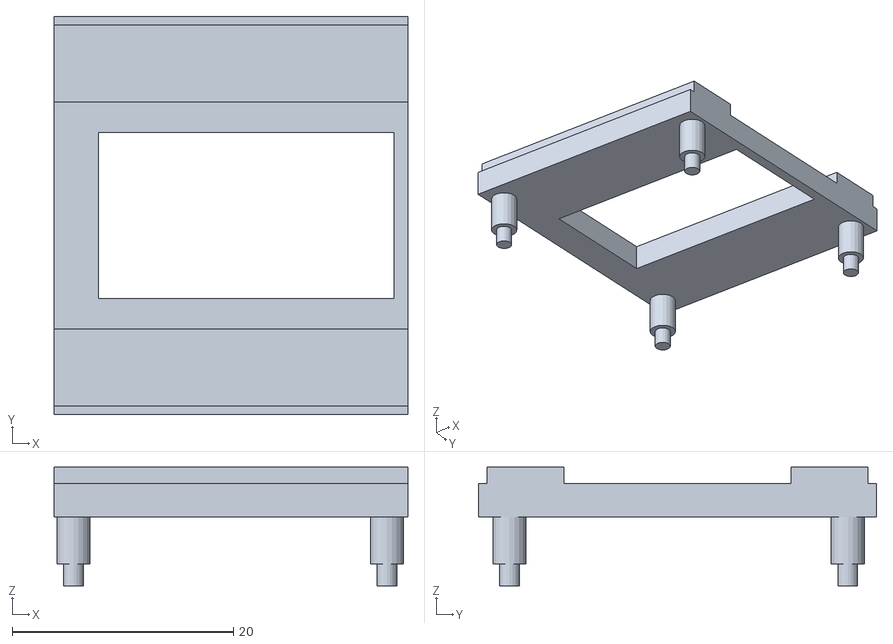
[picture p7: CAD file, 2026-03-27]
3d_parts/final parts/display/Tire Temp Display Module 4 middle.stl
32.0 x 36.0 x 10.8

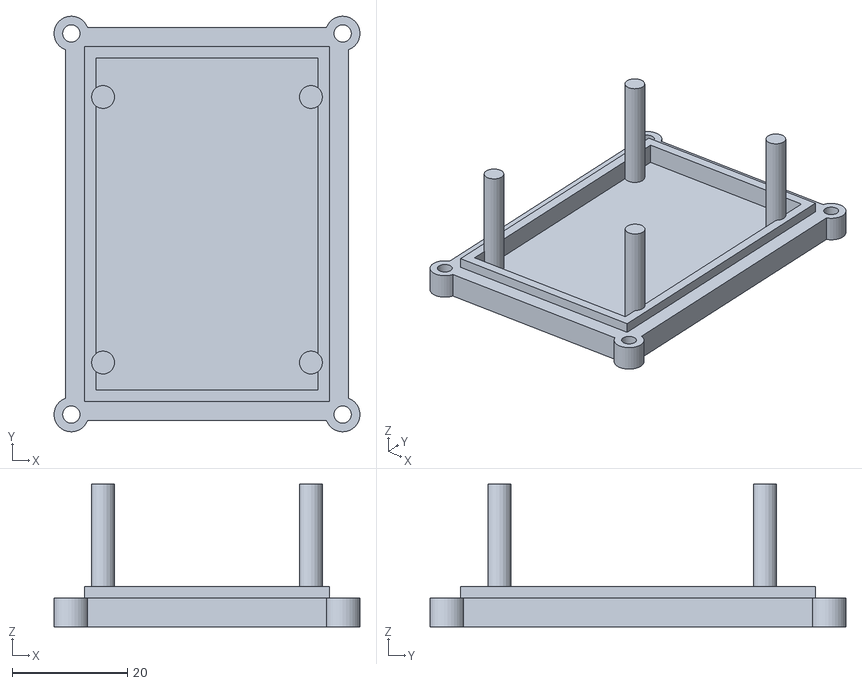
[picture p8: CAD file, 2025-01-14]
3d_parts/final parts/I2C Hub Box lid.stl
53.0 x 72.0 x 24.8

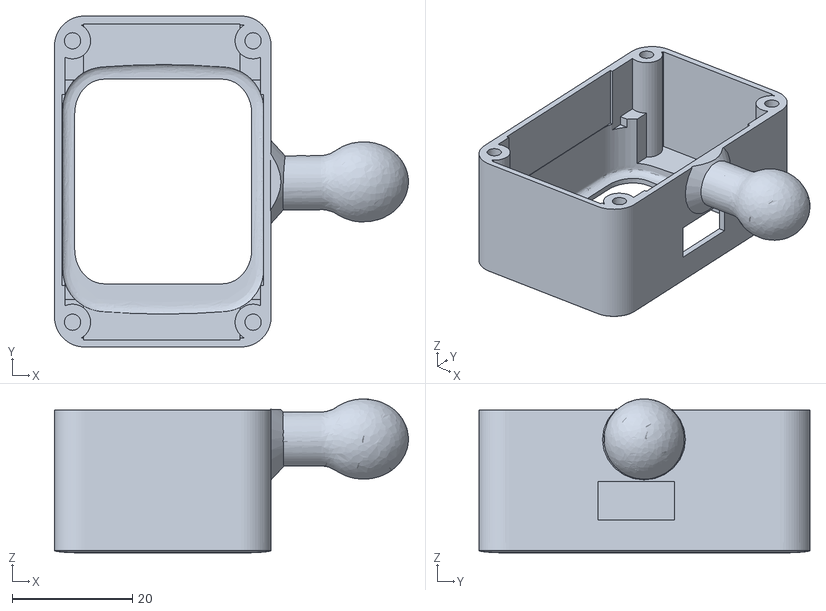
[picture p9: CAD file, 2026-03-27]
3d_parts/final parts/display/Tire Temp Display Module 4 front.stl
58.8 x 55.0 x 25.6

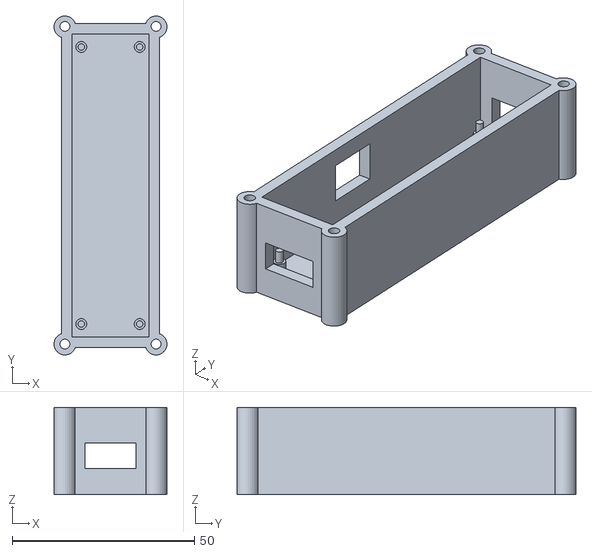
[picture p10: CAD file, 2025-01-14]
3d_parts/final parts/Power Input Box.stl
31.0 x 93.0 x 24.0

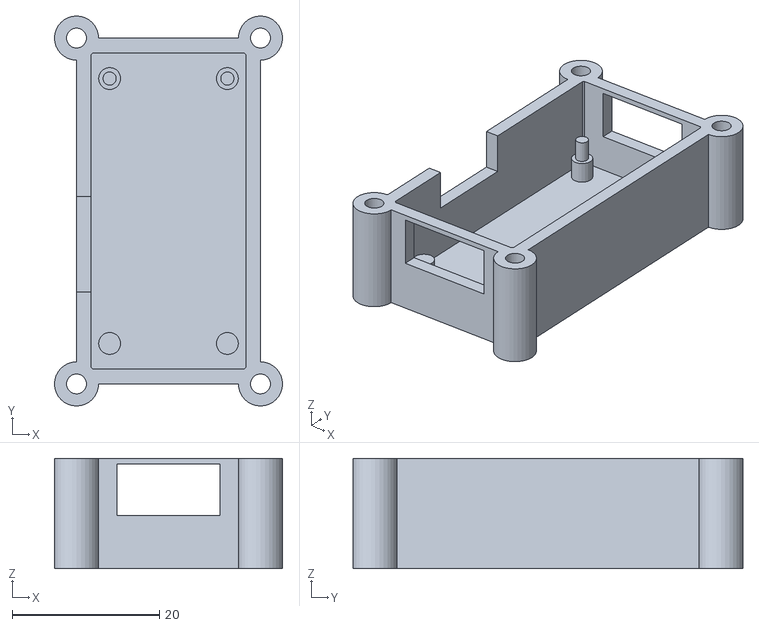
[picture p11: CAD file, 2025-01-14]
3d_parts/final parts/Power Input 5v Box.stl
31.0 x 53.0 x 15.0

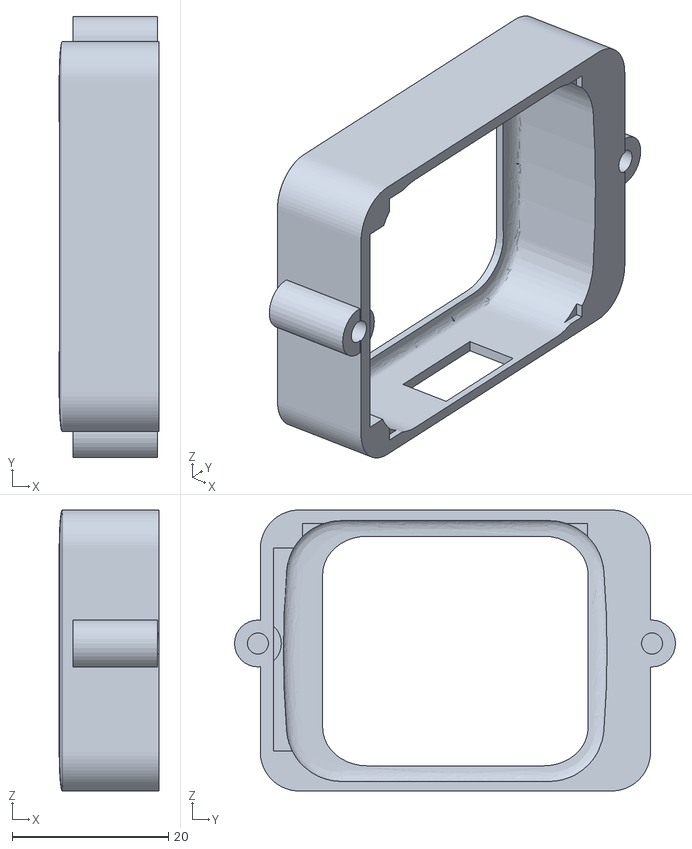
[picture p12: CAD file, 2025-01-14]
3d_parts/final parts/display/Tire Temp Display Module front new.stl
12.8 x 56.5 x 36.0

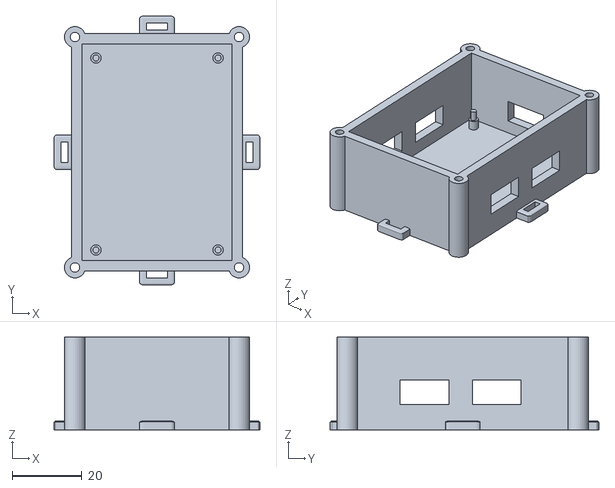
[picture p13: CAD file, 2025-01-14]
3d_parts/final parts/I2C Hub Box.stl
59.0 x 77.0 x 26.5

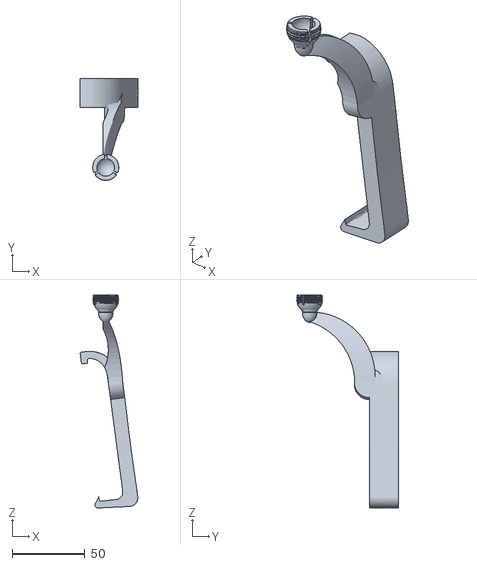
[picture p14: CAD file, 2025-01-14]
3d_parts/final parts/display/Tire Temp Display Module high cup.stl
39.5 x 69.9 x 146.1

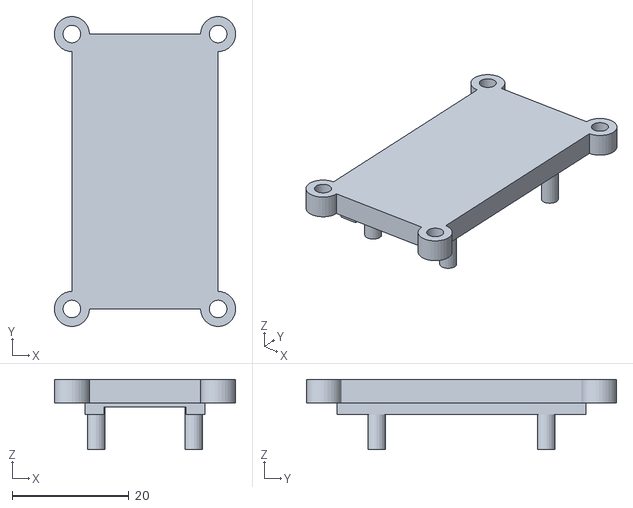
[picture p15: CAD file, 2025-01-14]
3d_parts/final parts/Power Input 5v Lid.stl
31.0 x 53.0 x 12.0

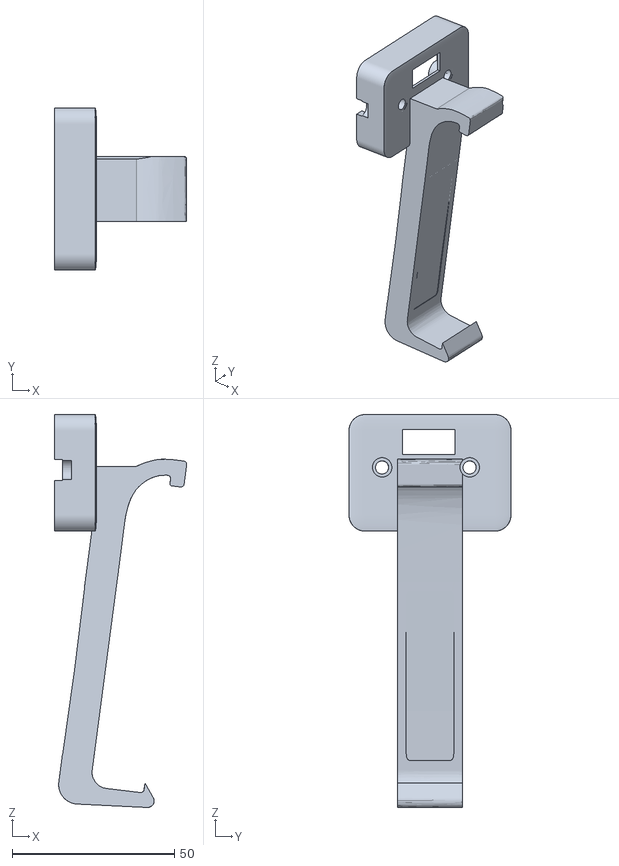
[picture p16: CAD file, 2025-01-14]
3d_parts/final parts/display/Tire Temp Display Module low.stl
40.9 x 50.0 x 121.2

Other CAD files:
3d_parts/final parts/Power Input Box. lidstl.stl
3d_parts/final parts/display/Tire Temp Display Module high cup thick.stl
3d_parts/final parts/Power Input Box button.stl
3d_parts/final parts/display/Tire Temp Display Module ball.stl
3d_parts/final parts/Tire Temp Sensor Box. protectionstl.stl
3d_parts/final parts/Tire Temp Sensor Lid.stl
3d_parts/final parts/display/Tire Temp Display Module ball mk2.stl
3d_parts/final parts/display/Tire Temp Display Module ball mk3.stl
3d_parts/final parts/display/Tire Temp Display Module mount new.stl
3d_parts/final parts/display/Tire Temp Display Module mount.stl
3d_parts/final parts/display/Tire Temp Display Module nut.stl
3d_parts/final parts/display/Tire Temp Display Module strap new mk2.stl
3d_parts/final parts/display/Tire Temp Display Module strap new.stl
3d_parts/final parts/display/Tire Temp Display Module strap.stl
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

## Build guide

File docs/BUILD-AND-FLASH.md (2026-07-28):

# Build & flash — the daily loop

How to build the firmware, get it onto the board, and watch it run. Platform-neutral;
first-time machine setup lives in [DEV-SETUP-MACOS.md](DEV-SETUP-MACOS.md) and
[DEV-SETUP-WINDOWS.md](DEV-SETUP-WINDOWS.md).

---

## The three ways to drive it

Same actions, pick whichever suits you.

### 1. Status-bar buttons (fewest keystrokes)

With the `actboy168.tasks` extension installed (it's in the recommended list), four
buttons appear in the **bottom-left status bar**:

```
 🔧 Build    ⚡ Flash    ⚡︎ Monitor    🔌 Doctor
```

Click `⚡ Flash` and you're done — it compiles, uploads, and prints a timing summary.

> VS Code has no built-in task buttons; that extension is what provides them. Everything
> still works without it, just from the command palette instead.

### 2. Keyboard / command palette

| Action | How |
|---|---|
| Build | `Cmd+Shift+B` (`Ctrl+Shift+B` on Windows) — it's the default build task |
| Anything else | `Cmd+Shift+P` → **Tasks: Run Task** → pick from the list |

### 3. Terminal

```bash
./scripts/tm.sh build      # compile
./scripts/tm.sh flash      # compile + upload  <- the usual one
./scripts/tm.sh monitor    # watch serial output
./scripts/tm.sh doctor     # why won't it connect?
```

Windows: `.\scripts\tm.ps1 <same commands>`.

Full command list: `./scripts/tm.sh --help`.

---

## How long does it take?

Every build and upload prints its own elapsed time, so you never have to guess. `flash`
prints a breakdown at the end:

```
==> Build took 33s
==> Upload took 21s

=== flash summary ===
  build   33s
  upload  21s
  total   56s
```

**Measured on this project** (2019 Intel Core i9 MacBook Pro, macOS 15.7.5, ESP32 core
3.0.7). Yours will differ, especially on Apple Silicon, which is typically much faster:

| Operation | Time | Notes |
|---|---|---|
| First-ever setup | **10–20 min** | One-time. Downloads ~5 GB of core + toolchain. |
| `build` — nothing changed | **~32 s** | arduino-cli still re-links and re-checks every library. |
| `build` — one `.cpp` edited | **~35 s** | Realistically your normal edit-build cycle. |
| `build --clean` | **~2 m 41 s** | Full rebuild, cache discarded. Rarely needed. |
| `upload` | **~21 s** | ~9 s of it is the actual 990 KB flash write at ~855 kbit/s. |
| **`flash` (build + upload)** | **~56 s** | The realistic edit → running-on-hardware turnaround. |

So: **expect about a minute from code change to running firmware.**

### Why an unchanged build still takes ~30s

arduino-cli re-runs library detection and re-links every time; it doesn't have a
no-op fast path like `make`. The per-file compile *is* cached — that's why a clean build
is 5× slower than an incremental one. If you only changed one `.cpp`, the ~35 s is mostly
fixed overhead, not your file.

Don't use `--clean` habitually. Reach for it only when you change `sketch.yaml` (library
or core versions) or hit an inexplicable link error.

---

## How much the flash tells you — `TM_VERBOSE`

The upload is the step that fails on real hardware: a charge-only cable, a board that
isn't in download mode, a flash chip that won't answer. arduino-cli's default upload
output hides the esptool conversation that says *which* of those it was, so **`upload`
and `flash` are verbose by default** — you get the esptool command line, chip and MAC
detection, per-segment write progress, and the hash verify. That's the output you
actually need to read when a flash goes wrong.

Before each upload the script also prints what it is about to write, so "why is the board
running old code?" is answerable from the flash log alone:

```
==> Uploading to /dev/cu.usbmodem2101
==> Firmware /Users/you/code/tires_monitor/build/tires_esp32.ino.bin
==>   986 KiB, built 2026-07-28 13:09:47
```

Set `TM_VERBOSE` to change the level:

| `TM_VERBOSE` | What you get |
|---|---|
| `0` (or `quiet`) | The old terse output — upload prints little more than the write percentage. |
| unset / `1` | **Default.** Verbose upload + the firmware summary above. |
| `2` (or `debug`) | Also a verbose *compile* (every gcc/link line) and arduino-cli's own debug log. A firehose — for when the toolchain itself is suspect. |

```bash
TM_VERBOSE=2 ./scripts/tm.sh flash        # macOS / Linux
$env:TM_VERBOSE=2; .\scripts\tm.ps1 flash # Windows
```

Level 2 is what to attach to a bug report. Note it makes `build` loud too, so the compile
output is long — that's deliberate.

---

## Typical session

```bash
# edit code in VS Code ...
./scripts/tm.sh flash        # ~1 min, ends with the timing summary
./scripts/tm.sh monitor      # watch it boot; Ctrl-] to quit
```

A healthy boot looks like:

```
Top of ESP32 Tires Setup
WiFi AP started
WiFi server started
WiFi initialized.
CST816Touch initialized.
7 items loaded from EEPROM
EEPROM values loaded
Bottom of ESP32 Tires Setup
```

`CST816Touch initialized.` is the meaningful one — it only appears if the I2C and touch
pins in `pin_config.h` are right, so it doubles as a hardware sanity check.

With no sensors attached you'll then see `I2C error: address send, NACK received`
repeating forever. **That's expected** — it's the firmware failing to reach the TCA9548A
mux at `0x70`. Tires read 0. Use the `esp32_i2c_scanner` sketch to debug the sensor bus
once hardware is wired up.

---

## Rules that will save you time

**Close the monitor before you upload.** The serial port is exclusive. An upload that
fails immediately after a successful one is almost always this. (`tm.sh flash` doesn't
open a monitor, so it's only an issue if you left one running.)

**The monitor only shows what's printed after it attaches.** USB CDC has no backlog, so
attaching late means the `setup()` banner is already gone. Tap **RST** with the monitor
open to see the boot from the top.

**Don't raise `UploadSpeed`.** It's pinned to 115200 in `sketch.yaml`. At 921600 esptool
dies with `No serial data received` while renegotiating baud — USB-Serial-JTAG isn't a
real UART. Raising it buys nothing; the flash write is USB-speed-bound either way.

---

## Changing the build configuration

Everything lives in [`tires_esp32/sketch.yaml`](../tires_esp32/sketch.yaml) — core
version, all seven library versions, and every board option. It is the single source of
truth, and it's committed, so any machine that clones this repo builds the identical
binary.

Two profiles:

| Profile | What |
|---|---|
| `waveshare169` | **Default.** ESP32 core 3.0.7 + pinned libraries. Verified working on hardware. |
| `waveshare169-latest` | Opt-in: core 3.3.11 + current libraries. Unverified — expect to fix API drift. |

Try the newer stack without committing to it:

```bash
./scripts/tm.sh build --profile waveshare169-latest
```

After changing library or core versions, do a `--clean` build.

---

## Flash budget

```
Sketch uses      989,649 bytes  (31%)  of 3,145,728  program storage
Global variables  48,872 bytes  (14%)  of   327,680  dynamic memory
```

The 3 MB app partition comes from `PartitionScheme=app3M_fat9M_16MB`. Plenty of room —
the firmware could roughly triple before partitioning becomes a concern.

---

## When something breaks

Run `./scripts/tm.sh doctor` first. It checks, in order: toolchain present → board
enumerated on USB at all → serial devices → arduino-cli detection → resolved port. That
sequence tells you immediately whether you have a cable problem or a software problem.

If `doctor` looks clean and the flash still fails, re-run it with `TM_VERBOSE=2` (see
above) — that surfaces the raw esptool exchange, which is usually where the real reason
is written.

| Symptom | Cause / fix |
|---|---|
| `No board detected` | **Cable first** — many USB-C cables are charge-only. Then try another port. `doctor` tells you if the OS sees the device at all. |
| `No serial data received` during baud change | `UploadSpeed` was raised above 115200. Put it back. |
| `Unable to verify flash chip connection` | Leftover state from an aborted upload. `tm.sh upload` auto-retries once after a hard reset; if it still fails, hold **BOOT**, tap **RST**, release **BOOT**, retry. |
| Upload fails right after a good one | A serial monitor is holding the port. Close it. |
| Monitor silent | Attached after boot. Tap **RST**. |
| Red squiggles in the editor | `./scripts/tm.sh intellisense`, then reload the VS Code window. |
| Board port name changed | Normal — it varies per physical USB port. Detection is by USB VID/PID, so it just works. Override with `TM_PORT=/dev/cu.usbmodemXXXX` if needed. |

Deeper per-platform troubleshooting is in the two setup guides.

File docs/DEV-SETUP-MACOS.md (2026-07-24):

# Dev environment setup — macOS

Sets up building and flashing the `tires_esp32` firmware from VS Code on a Mac.
Start to finish: ~15 minutes, most of it one large download.

You do **not** need the Arduino IDE. Everything runs through `arduino-cli`, which is
the same toolchain the Arduino IDE uses internally.

> **Handing this to Claude Code?** Every step below is a literal command. Say:
> *"Follow docs/DEV-SETUP-MACOS.md and get the firmware building."*

---

## 1. Install Homebrew (skip if you have it)

Check:

```bash
brew --version
```

If that fails:

```bash
/bin/bash -c "$(curl -fsSL https://raw.githubusercontent.com/Homebrew/install/HEAD/install.sh)"
```

## 2. Install arduino-cli

```bash
brew install arduino-cli
arduino-cli version      # expect 1.5.x or newer
```

## 3. Install VS Code extensions

```bash
code --install-extension ms-vscode.cpptools
code --install-extension ms-vscode.vscode-serial-monitor
```

Or open the repo in VS Code and accept the "recommended extensions" prompt — they're
listed in `.vscode/extensions.json`.

> Do **not** install the Arduino extension. Microsoft archived it in October 2024, and
> its community fork insists on managing its own `.vscode/arduino.json`, which fights
> the `sketch.yaml` build profile this project uses.

## 4. First build

From the repo root:

```bash
./scripts/tm.sh setup
```

This downloads the pinned ESP32 core (`esp32:esp32` 3.0.7) and all seven libraries, then
compiles. **The first run downloads roughly 1 GB and can take 5–15 minutes** — the
Xtensa cross-compiler toolchain is large. Later builds take seconds.

You should end with a `Sketch uses ... bytes` summary and no errors.

Nothing here is global: `sketch.yaml` pins every version, and arduino-cli excludes
globally-installed cores and libraries from a profile build. Another project on this Mac
cannot break this one.

## 5. Generate IntelliSense data

```bash
./scripts/tm.sh intellisense
```

Then reload VS Code (`Cmd+Shift+P` → *Developer: Reload Window*). Code navigation and
autocomplete now resolve into the real ESP32 core headers.

## 6. Connect the board

Plug the Waveshare board into the Mac with a USB-C cable, then:

```bash
./scripts/tm.sh port
```

Expect something like `/dev/cu.usbmodem2101`.

**If it prints an error, the cable is the most likely cause** — see
[Troubleshooting](#troubleshooting-connections) below. Run `./scripts/tm.sh doctor`
first; it distinguishes a cable problem from a software problem.

## 7. Flash it

```bash
./scripts/tm.sh flash      # compile + upload
./scripts/tm.sh monitor    # watch it boot
```

Expected serial output (captured from a real run of this setup):

```
Top of ESP32 Tires Setup
WiFi AP started
WiFi server started
WiFi initialized.
CST816Touch initialized.
7 items loaded from EEPROM
EEPROM values loaded
Bottom of ESP32 Tires Setup
I2C error: address send, NACK received      <- only if no sensors are attached
```

...and the round LCD shows four tire quadrants. Swipe left on the screen to open the menu.

Press `Ctrl-]` to exit the monitor.

> **`CST816Touch initialized.` is the line that matters.** It only appears if the I2C and
> touch pins in `pin_config.h` are correct, so it doubles as a wiring sanity check.

> The repeating `I2C error: address send, NACK received` is **expected with no sensors
> attached** — it's the code failing to reach the TCA9548A mux at 0x70. Tires will read 0.
> Not a setup problem. Use the `esp32_i2c_scanner` sketch to debug the sensor bus once
> the hardware is wired up.

> The monitor only shows output produced *after* it attaches, so a monitor opened late
> shows nothing until the next reset. Tap **RST** to see the banner.

---

## Daily workflow

See [BUILD-AND-FLASH.md](BUILD-AND-FLASH.md). Short version: `Cmd+Shift+B` builds;
*Run Task → Flash* uploads.

---

## What you should know about USB serial on a Mac

If your only experience is COM ports on Windows, this is the orientation.

### There is no driver to install

This board uses the ESP32-S3's **native USB** (USB-Serial-JTAG) — not a CP2102/CH340/FTDI
bridge chip. macOS enumerates it as a standard CDC serial device with drivers already in
the OS.

It appears as **VID `0x303A`, PID `0x1001`** — Espressif's hardware USB-Serial-JTAG
identity. (The board variant also declares PID `0x821E`, but that descriptor is only used
if the firmware runs USB-OTG/TinyUSB. This project builds with `USBMode=hwcdc`, so you get
`0x1001`. The scripts accept both.)

Every "install the Silicon Labs VCP driver" tutorial you'll find for ESP32 boards is for
a *different kind of board* and does not apply here. Installing one won't help and adds a
kernel extension you don't need.

### Ports are files, and there are two of every one

macOS exposes serial devices as `/dev/cu.*` and `/dev/tty.*` — the same hardware, two
device nodes:

| Node | Use |
|---|---|
| `/dev/cu.usbmodem*` | **Always use this one.** "callout" — opens immediately. |
| `/dev/tty.usbmodem*` | Blocks waiting for carrier detect. Will hang an upload. |

The scripts filter `tty.*` out and only ever return a `cu.*` device.

### Names are not stable

The suffix changes with the *physical port* you plug into, and changes again when the
board reboots into download mode. That's why the scripts resolve the board by USB VID/PID
out of `arduino-cli board list --json` instead of hardcoding a name.

Override it if you ever need to:

```bash
TM_PORT=/dev/cu.usbmodem2101 ./scripts/tm.sh flash
```

### No sudo, no group membership

Unlike Linux (`dialout`), macOS lets your user open serial devices directly. If something
suggests `sudo`, it's wrong.

### Only one program can hold the port

**The single most common failure**: an upload fails right after a successful one because
a serial monitor is still attached. Close the monitor (`Ctrl-]`, or close the VS Code
Serial Monitor pane) before uploading.

---

## Troubleshooting connections

Run this first — it separates hardware problems from software problems:

```bash
./scripts/tm.sh doctor
```

### "No board detected"

**1. Suspect the cable first.** Many USB-C cables are charge-only, with no data
conductors. This is by far the most common cause. Check whether macOS sees the device
*at all*:

```bash
system_profiler SPUSBDataType | grep -i -A8 "ESP32\|Waveshare\|USB JTAG"
```

- **Output** → the board is enumerated; it's a software issue, keep reading.
- **No output** → the cable or the port. Swap the cable for one you know carries data
  (e.g. one that syncs a phone), then try a different port on the Mac. Nothing in
  software can fix this.

**2. Force download mode.** If the board is enumerated but flashing fails, put the
ESP32-S3 into the ROM bootloader by hand:

> Hold **BOOT**, tap **RST**, then release **BOOT**.

The port re-enumerates under a different name — another reason detection is by VID/PID.
Then run `./scripts/tm.sh upload`.

**3. Check nothing else holds the port.**

```bash
lsof | grep cu.usbmodem
```

### "No serial data received" while changing baud rate

Already fixed in `sketch.yaml` — recorded here so you know why. The Arduino IDE config
this project came from used `UploadSpeed=921600`, and on this board that fails:

```
Stub running...
Changing baud rate to 921600
A fatal error occurred: No serial data received.
```

USB-Serial-JTAG isn't a real UART, so renegotiating baud breaks the link. The profile
pins `UploadSpeed=115200`; flashing still runs at ~865 kbit/s because the USB link speed
has nothing to do with that number. **Don't "optimise" it back up.**

### "Unable to verify flash chip connection"

A previous aborted upload left the chip half-way into download mode. `tm.sh upload`
detects this, hard-resets, and retries once automatically. If it still fails, force
download mode by hand: hold **BOOT**, tap **RST**, release **BOOT**, then upload again.

### Upload starts but fails partway

Usually the cable — a marginal one enumerates but drops packets under load. Swap it.

### Monitor shows nothing

Expected, and not a fault: USB CDC only delivers what the device prints *after* you
attach, so the `setup()` banner is already gone by the time the monitor is up. Tap **RST**
with the monitor open to see it from the top.

If it is still silent after a reset, check the monitor is not fighting an upload for the
port, then re-flash.

### Nothing works and you want a second opinion

```bash
arduino-cli board list        # what arduino-cli sees
ls /dev/cu.*                  # what the OS sees
```

If `ls /dev/cu.*` shows only `cu.BLTH` and `cu.Bluetooth-Incoming-Port`, no board is
attached — go back to the cable.

---

## Version notes

- **macOS 26 (Tahoe)** has an open esptool issue
  ([arduino-esp32#11849](https://github.com/espressif/arduino-esp32/issues/11849)) causing
  upload failures. macOS 15.x and earlier are unaffected.
- **Apple Silicon** shows a one-time *"Allow accessory to connect"* prompt on first plug-in.
  Approve it in System Settings → Privacy & Security. Intel Macs don't prompt.

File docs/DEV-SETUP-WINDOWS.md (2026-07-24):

# Dev environment setup — Windows

Sets up building and flashing the `tires_esp32` firmware from VS Code on Windows.
Start to finish: ~15 minutes, most of it one large download.

You do **not** need the Arduino IDE. Everything runs through `arduino-cli`, which is the
same toolchain the Arduino IDE uses internally.

> **Handing this to Claude Code?** Every step below is a literal command. Say:
> *"Follow docs/DEV-SETUP-WINDOWS.md and get the firmware building."*

> The macOS guide was verified end to end on real hardware. This one mirrors it, with the
> Windows-specific differences called out. The `sketch.yaml` build definition is identical
> on both platforms, so builds are byte-for-byte reproducible across them.

---

## 1. Install arduino-cli

Pick whichever package manager you have (PowerShell):

```powershell
winget install ArduinoSA.CLI
# or:  choco install arduino-cli
# or:  scoop install arduino-cli
```

No package manager? Download the 64-bit MSI from
<https://arduino.github.io/arduino-cli/latest/installation/>.

**Open a new terminal** so `PATH` picks it up, then check:

```powershell
arduino-cli version      # expect 1.5.x or newer
```

## 2. Allow the helper script to run

Windows blocks unsigned scripts by default. Once per machine:

```powershell
Set-ExecutionPolicy -Scope CurrentUser -ExecutionPolicy RemoteSigned
```

(The VS Code tasks pass `-ExecutionPolicy Bypass` and work regardless, but this makes the
script runnable directly from a terminal.)

## 3. Install VS Code extensions

```powershell
code --install-extension ms-vscode.cpptools
code --install-extension ms-vscode.vscode-serial-monitor
```

Or open the repo in VS Code and accept the "recommended extensions" prompt.

> Do **not** install the Arduino extension. Microsoft archived it in October 2024, and its
> community fork manages its own `.vscode/arduino.json`, which fights the `sketch.yaml`
> build profile this project uses. (The old, now-deleted `arduino.json` in this repo is
> where the `COM7` and `new_menu_test` leftovers came from.)

## 4. First build

From the repo root:

```powershell
.\scripts\tm.ps1 setup
```

This downloads the pinned ESP32 core (`esp32:esp32` 3.0.7) and all seven libraries, then
compiles. **The first run downloads roughly 1 GB and can take 5–15 minutes.** Later builds
take seconds.

Expected result:

```
Sketch uses 989649 bytes (31%) of program storage space. Maximum is 3145728 bytes.
Global variables use 48872 bytes (14%) of dynamic memory...
```

## 5. Generate IntelliSense data

```powershell
.\scripts\tm.ps1 intellisense
```

Then reload VS Code (`Ctrl+Shift+P` → *Developer: Reload Window*).

## 6. Connect the board

```powershell
.\scripts\tm.ps1 port
```

Expect something like `COM7`. If it errors, run `.\scripts\tm.ps1 doctor`.

## 7. Flash it

```powershell
.\scripts\tm.ps1 flash      # compile + upload
.\scripts\tm.ps1 monitor    # watch it boot
```

Expected serial output:

```
Top of ESP32 Tires Setup
WiFi AP started
WiFi server started
WiFi initialized.
CST816Touch initialized.
7 items loaded from EEPROM
EEPROM values loaded
Bottom of ESP32 Tires Setup
I2C error: address send, NACK received      <- only if no sensors are attached
```

`CST816Touch initialized.` is the line that proves the pin map is right. The repeating
`I2C error` lines are expected with no sensors attached.

---

## Windows-specific notes

### Drivers

This board uses the ESP32-S3's **native USB** (USB-Serial-JTAG), enumerating as
**VID `0x303A`, PID `0x1001`**. Windows 10/11 bind their in-box USB CDC driver
automatically — **no CP210x/CH340 driver needed**. Tutorials telling you to install the
Silicon Labs VCP driver are for different boards.

If Device Manager shows the device with a yellow warning triangle, right-click →
*Update driver* → *Search automatically*.

### COM port numbers move

Windows assigns a COM number per USB port, and hands out a different one when the board
re-enumerates into download mode. That's why the scripts resolve the port by USB VID/PID
rather than hardcoding a number. Override when you need to:

```powershell
$env:TM_PORT = 'COM7'
.\scripts\tm.ps1 flash
```

### Only one program can hold the port

Close the serial monitor before uploading — this is the most common cause of an upload
that fails right after a successful one.

### Line endings

`.gitattributes` is not set in this repo. If git converts `scripts/tm.sh` to CRLF it will
not run under WSL or Git Bash. It doesn't affect the PowerShell path.

### Python

`tm.ps1` does all its JSON handling natively in PowerShell, so — unlike `tm.sh` — it does
**not** need Python installed.

---

## Troubleshooting

Run this first:

```powershell
.\scripts\tm.ps1 doctor
```

It reports the toolchain, whether Windows sees a `VID_303A` device at all, the COM ports
present, and the resolved port.

### "No board detected"

**1. Suspect the cable first.** Many USB-C cables are charge-only. Check whether Windows
sees the device at all:

```powershell
Get-PnpDevice -PresentOnly | Where-Object InstanceId -match 'VID_303A'
```

- **Rows returned** → enumerated; keep reading.
- **Nothing** → cable or port. Swap for a cable you know carries data, then try a
  different USB port. No software change will fix this.

**2. Force download mode.** Hold **BOOT**, tap **RST**, release **BOOT**, then retry the
upload.

### "No serial data received" while changing baud rate

Already handled: `sketch.yaml` pins `UploadSpeed=115200`. USB-Serial-JTAG isn't a real
UART and fails when esptool renegotiates to 921600. Don't raise it.

### "Unable to verify flash chip connection"

A previous aborted upload left the chip half-way into download mode. `tm.ps1 upload`
hard-resets and retries once by itself; if it still fails, use BOOT+RST as above.

### Monitor shows nothing

USB CDC only delivers output produced after you attach, so the boot banner is long gone.
Tap **RST** with the monitor open.

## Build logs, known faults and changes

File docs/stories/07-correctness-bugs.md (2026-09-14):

# Correctness bugs (firmware §3.1)

- **Area:** recommendations doc §3.1 · bug
- **Depends on:** — (do first; unblocks calibration + data integrity)
- **Status:** draft — not filed

## Summary

> **Not Track-gated** — correctness fixes apply in all modes (Street and Track).
A cluster of correctness bugs verified in the firmware while reading it. Two
matter for the data/calibration work and should lead; the rest are cleanups.
Decide during review whether to file as one tracking issue with a checklist or
split the load-bearing ones out.

## The bugs

**(a) Fahrenheit compared against Celsius in the validity filter.** `TempReader.cpp`
`readTemps()` converts each band C→F and validates it in the same pass, so the
cross-band "rescue" in `newTempIsInvalid()` compares an already-°F band against
sibling bands still in °C (~85-unit gap at operating temp). Result: asymmetric
band rejection, worst during warm-up; a rejected band latches its previous value.
**May have corrupted existing logs.** Fix: convert all three bands, *then* validate.

**(b) Uninitialized loop variable.** `TempReader.cpp:146` — `for (int tj; tj<3; tj++)`
reads stack garbage; a negative start indexes out of bounds. Fix: `int tj = 0`.

**(c) `ThreeSectionTire::initialize()` never runs.** Invoked from the base `Tire`
constructor (`Tire.cpp:12`) where the vtable is still `Tire`'s, so the override
doesn't execute and `lastDeltaColors[]` / `currentDeltaColors[]` stay uninitialized.
Cosmetic; call it from the derived ctor or first `draw()`.

**(d) `anySectionColorChanged()` has no return on the fall-through path**
(`ThreeSectionTire.cpp`). Harmless today (uncalled). Delete or fix.

**(e) A byte setting can never be stored as 0.** `MenuSystem.cpp:227` skips loading
any `VALUE_BYTE` whose stored value is 0, so `minInflationDeltaPct` can't be zeroed
and **signed per-corner baselines can't be stored** — this **blocks story 04**.
Needs a "written" sentinel or offset encoding.

**(f) Uneven bands from integer division.** `TempReader.cpp:76-77` — the left band
is systematically narrowest (6/7/7 for a 20-col crop). Irrelevant to inflation
(both shoulders averaged) but biases the alignment (O−I) metric. Distribute the
remainder symmetrically.

**(g) `draw()` returns early from inside its own loop** (`ThreeSectionTire.cpp`).
One out-of-range band aborts the whole tire's redraw + delta bar for that frame
without updating `lastTemps`; a single glitch frame stalls the display.

**(h) Zero overloaded as "no data" in the NBP encoder.** `NBPProtocol.cpp:43` —
`if (fl.values[1] == 0)` collapses a corner to a single channel, so a legitimate
0 (or a startup-rejected band) silently changes the channel set mid-file — a
parsing hazard for the dumps.

## Acceptance criteria
- [ ] (a) All bands converted before any validation; band rejection symmetric.
- [ ] (b) `tj` initialized.
- [ ] (e) A byte setting can store 0 / signed baselines can be persisted.
- [ ] (c,d,f,g,h) addressed or explicitly deferred with rationale.
- [ ] Existing log parsing unaffected (or the change documented for `tires_data`).

## Open questions / tweaks to discuss
- One tracking issue with a checklist, or split (a)/(b)/(e) as their own?
- Which are must-fix-now vs. later? (a), (b), (e) are the load-bearing ones.
- Does (a) warrant re-checking already-collected logs for the latch signature?

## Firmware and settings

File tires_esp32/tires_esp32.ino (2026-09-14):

#include <Adafruit_GFX.h>    // Core graphics library
#include <Adafruit_ST7789.h> // Hardware-specific library for ST7789
#include <SPI.h>
#include <Wire.h>
#include <EEPROM.h>

#include "Arduino_GFX_Library.h"
#include "pin_config.h"
#include "HWCDC.h"
#include "Tire.h"
#include "Wheels.h"
#include "TempReader.h"
#include "NBPProtocol.h"
#include "WifiSerial.h"
#include "IMUGate.h"
#include "ImuGateBar.h"
#include "TireProfiles.h"
#include "SessionManager.h"
#include "Version.h"

// #include "MyCST816Touch.h"
#include "CST816Touch_SWMode.h"


#include "TireMenu.h"           // Our custom menu structure
#include "MenuRenderer.h"       // Renders the TireMenu items
#include "TouchMenuHandler.h"   // Handles gestures to navigate the menu
#include "QuadrantFactory.h"
#include "ThermalDisplay.h"
#include "OffsetSetup.h"        // Interactive camera crop-offset mode (#23)
#include "LensSetup.h"          // Interactive camera field-of-view mode (#31)
#include "DisplayBase.h"
#include "StandardDisplay.h"
#include "BufferedDisplay.h"
#include "DisplayProxy.h"

#define WIFI_SSID "TireTempMonitor"
#define WIFI_PASSWORD "esp32"
#define WIFI_PORT 8080
byte THERMAL_MODES =4;

bool testMode = false;
int forceDrawAfterInit = 0;
bool highFrequencyUpdates = false;
bool enableThermalTemps = false;

// Calculated (surface->carcass) mode K/tau come from the active tire profile (story 04),
// which since #14 is the single source of truth in both modes -- there is no longer a
// mode-level fallback pair here. The seed values live in TireProfiles::seedDefaults().

HWCDC USBSerial;
SPIClass hspi(HSPI);
Adafruit_ST7789 tft = Adafruit_ST7789(&hspi, LCD_CS, LCD_DC, LCD_RST);
StandardDisplay standardDisplay(tft);
BufferedDisplay bufferedDisplay(tft);
DisplayProxy displayProxy;
DisplayBase& display = displayProxy;

// WifiSerial instance
WifiSerial wifiSerial;
NBPProtocol nbp(wifiSerial);

// Existing objects
Wheels* wheels = nullptr;
TempReader* tempReader = nullptr;

// On-board QMI8658C IMU: lateral-g capture gate + latched over/under (story 02).
IMUGate imuGate;

// Session lifecycle + end-of-session summary (story 01). Owns start/seal, per-corner
// accumulation, the persisted summary, and the auto-seal backstop. Referenced extern by
// MenuRenderer (View Summary recall).
SessionManager sessionManager;

// Swipe-feedback + auto-summary display state (story 01). On start a red "recording"
// dot shows for 5 s; on end a black "stop" square shows for 5 s, then the summary is
// presented and paged with up/down swipes (Track mode only).
enum SwipeFeedback { FB_NONE, FB_START, FB_END };
static SwipeFeedback fbState = FB_NONE;
static unsigned long fbSetMs = 0;
static const unsigned long FB_MS = 5000;
static bool summaryAutoView = false;   // full-screen summary is showing (running mode)
static int  summaryAutoPage = 0;
static bool summaryAutoDirty = false;  // needs a (re)paint

// Debounce for the session-toggle swipe (Track mode). The touch library often reports a
// single physical swipe twice, so starting a session would immediately end it; and the
// swipe that dismisses the summary can bleed into starting a fresh one. After any
// session start/end -- and after dismissing the summary -- we ignore the toggle swipe for
// SWIPE_LOCK_MS so the second registration is dropped.
static unsigned long swipeLockSetMs = 0;
static const unsigned long SWIPE_LOCK_MS = 1000;
static void armSwipeLock(){ swipeLockSetMs = millis(); }
static bool sessionSwipeLocked(){ return (millis() - swipeLockSetMs) < SWIPE_LOCK_MS; }

// ... after initializing tft in setup() ...
QuadrantFactory factory(display, /*margin=*/ 5);

// // To create the upper-left ThermalDisplay:
ThermalDisplay* UL = factory.createDisplay(/*top=*/ true, /*left=*/ true);
ThermalDisplay* UR = factory.createDisplay(/*top=*/ true, /*left=*/ false);
ThermalDisplay* LL = factory.createDisplay(/*top=*/ false, /*left=*/ true);
ThermalDisplay* LR = factory.createDisplay(/*top=*/ false, /*left=*/ false);


ThermalDisplay* thermalDisplays[4] = {UL, UR, LL, LR};


uint8_t thermalMode = 0; // 4 modes total

// The mode's default view is resolved before the sensors have owned up to what they are
// (#32). A fresh TempReader claims every corner is a camera and only finds out otherwise
// when checkTireSensor() actually fails to bring one up, several read passes later -- so
// initializeSystem() picks the default from a guess and this says the guess is still open
// to correction. checkForWheelsReset() re-resolves while it is set; the first manual swipe
// clears it, because from then on the view is the driver's choice and not ours to revise.
bool defaultViewPending = false;

// Keep track of time
unsigned long previousTime = 0;
long millisSinceLastUpdate = 0;
long updateIntervalMillis = 1000;
long readIntervalMillis = 100;
long millisSinceLastRead = 0;

// Time helper
long timeDelta()
{
  unsigned long currentTime = millis();
  long delta = (long)(currentTime - previousTime);
  previousTime = currentTime;
  return delta;
}



  // 1) Create a CST816Touch object (from mjdonders/CST816_TouchLib)
  CST816Touch_SWMode cstTouch;

  // 2) Retrieve Tire Menu system
  MenuSystem &menuSystem = getTireMenuSystem();

  // 3) Create MenuRenderer
  MenuRenderer menuRenderer(menuSystem, display);
  //MenuRenderer menuRenderer(menuSystem, standardDisplay)

  // 4) Create TouchMenuHandler
  TouchMenuHandler menuHandler(menuSystem, menuRenderer, cstTouch);


// Forward declarations
static void applyMenuConfig();
static void cleanupObjects();
static void initializeSystem();
static void sendBootMetadata();
static void exitSummaryAutoView();
static void toggleSession();
static void serviceModeProfileSnap();
static void applyThermalActivation();
static void beginOffsetSetup();
static void endOffsetSetup();
static void checkOffsetSetupSwipes();
static void doOffsetSetupMode(int time_delta);
static void beginLensSetup();
static void endLensSetup();
static void checkLensSetupSwipes();
static void doLensSetupMode(int time_delta);
static uint8_t defaultThermalMode();
extern uint8_t getCurrentModeValue();
extern bool getAutoSealStationary();
// Street tire temp window (#27) -- file scope because resolveTireWindow(),
// initializeSystem() and sendBootMetadata() all reach for it.
extern bool getStreetWindowEnabled();
extern uint8_t getStreetMin();
extern uint8_t getStreetIdeal();
extern uint8_t getStreetMax();

// Last Current Mode seen by the profile snap (#14). Seeded in setup() right after the
// boot resolve so the watcher in loop() only fires on an actual mode change.
static uint8_t lastModeForProfile = 0;

void checkForWheelsReset(){
  if (tempReader->tireSensorIsCamera[0] != wheels->fl3 ||
      tempReader->tireSensorIsCamera[1] != wheels->fr3 ||
      tempReader->tireSensorIsCamera[2] != wheels->rl3 ||
      tempReader->tireSensorIsCamera[3] != wheels->rr3){
        USBSerial.println("Found a different sensor. resetting Wheels");
        Wheels* oldWheels = wheels;
        USBSerial.println("oldWheels Point Created");
        USBSerial.print("Free heap before alloc: ");
        USBSerial.println(ESP.getFreeHeap());
        wheels = new Wheels(oldWheels,
          tempReader->tireSensorIsCamera[0],
          tempReader->tireSensorIsCamera[1],
          tempReader->tireSensorIsCamera[2],
          tempReader->tireSensorIsCamera[3]);
        USBSerial.println("new Wheels object initialized");
        delete oldWheels;
        USBSerial.println("oldWheels deleted");
        oldWheels = nullptr;
        USBSerial.println("oldWheels pointer set to null");
        activateTires();

        // The flags just moved, which means detection finally settled a corner -- and this is
        // the only moment the truth about the cameras is newer than the guess the default view
        // was picked from (#32). Re-resolve it here or the "if a camera is fitted" half of the
        // rule can never fire: a board with no cameras would sit in Street's camera view
        // showing four black quadrants, because at initializeSystem() time every corner still
        // claimed to be one.
        //
        // Deliberately not latched to the first correction. Corners come up independently, so
        // the "is there any camera at all" answer can change again a pass or two later; while
        // the view is still ours it should keep tracking the truth.
        if (defaultViewPending){
          uint8_t want = defaultThermalMode();
          if (want != thermalMode) setThermalMode(want);
        }
      }
}

void switchThermalMode(bool up){
  int dir = (up)?1:-1;
  int tMode = (thermalMode + dir + THERMAL_MODES) % THERMAL_MODES;
  // A deliberate pick outranks the mode's default (#32): late sensor detection must not
  // yank the view back out from under the driver's thumb. Holds until the next rebuild.
  defaultViewPending = false;
  setThermalMode(tMode);
}


   

void updateThermalDisplays(){
  if (enableThermalTemps){
    if (thermalMode ==0){
      // Do Nothing
    }else{
      thermalDisplays[0]->updateDisplay(0);
      thermalDisplays[1]->updateDisplay(1);
      thermalDisplays[2]->updateDisplay(2);
      thermalDisplays[3]->updateDisplay(3);
    }
  }
  else{
    switch (thermalMode)
    {
    case 0:
      // Do Nothing
      break;

    case 1:
      thermalDisplays[2]->updateDisplay(0);
      thermalDisplays[3]->updateDisplay(1);
      break;
    
    case 2:
      thermalDisplays[0]->updateDisplay(2);
      thermalDisplays[1]->updateDisplay(3);
      break;
    
    case 3:
      thermalDisplays[0]->updateDisplay(0);
      thermalDisplays[1]->updateDisplay(1);
      thermalDisplays[2]->updateDisplay(2);
      thermalDisplays[3]->updateDisplay(3);
      break;
    
    default:
      break;
    }
  }
}    

// Which quadrants show a camera image for the current thermalMode. Split out of
// setThermalMode() (#23) because the offset-setup mode has to force all four on, and put
// them back on exit, WITHOUT the repaint below -- the menu is what takes the screen next, so
// painting the running display first would only flash it.
static void applyThermalActivation(){
  if (enableThermalTemps){
    // Test mode drives all four from one frame set: it is all of them or none.
    const bool on = (thermalMode != 0);
    UL->isActive=on;
    UR->isActive=on;
    LL->isActive=on;
    LR->isActive=on;
  }else{
    // 0 = none, 1 = rears, 2 = fronts, 3 = all four. switchThermalMode() keeps thermalMode
    // inside that range with its modulo, so there is no other case to answer for.
    UL->isActive = (thermalMode == 2 || thermalMode == 3);
    UR->isActive = (thermalMode == 2 || thermalMode == 3);
    LL->isActive = (thermalMode == 1 || thermalMode == 3);
    LR->isActive = (thermalMode == 1 || thermalMode == 3);
  }
}

void setThermalMode(uint8_t _thermalMode){
  thermalMode = _thermalMode;
  applyThermalActivation();
  display.fillScreen(ST77XX_BLACK);
  imuGateBarInvalidate();
  activateTires();
  if (!(enableThermalTemps && thermalMode ==2))
    wheels->draw(true);
}

// Over/under source for the latch (story 02, refined by story 06). Computes the
// overall center-hot vote across the camera tires from the working section temps --
// which are the CALCULATED (offset + smoothed) values when calculated mode is on
// (calculated-everywhere). The IMU gate applies this vote only on captured
// (straight-line) frames, which is what strips the mid-corner body-roll artifact.
// The per-corner baseline subtraction was removed in #18 -- see TireProfiles.h for why
// (the shipped values encoded one track's load pattern, and the static part of the error
// is a camera aim problem belonging in the pixel crop offsets).
// #21 keeps the per-corner verdicts instead of collapsing them to one majority vote. The
// old shape threw away exactly the information the feature exists to deliver -- WHICH tire
// is wrong -- and let one clearly-over corner be cancelled by its neighbours' neutrals.
// This is now the ONLY place the inflation comparison is computed; the display and the
// instrumentation stream both consume the latched result rather than re-deriving it.
extern byte getminInflationDeltaPct();
static void computeInflationVotes(int8_t out[TIRE_COUNT])
{
  float pct = getminInflationDeltaPct() / 100.0f;
  for (int t = 0; t < TIRE_COUNT; t++) {
    out[t] = 0;
    if (!tempReader->tireSensorIsCamera[t]) continue;
    float edge = (tempReader->tireSectionTemps[t][0] +
                  tempReader->tireSectionTemps[t][2]) / 2.0f;
    float center = tempReader->tireSectionTemps[t][1];
    if (edge <= 0.0f) continue;                  // skip unread/invalid frames
    float delta = edge - center;                 // negative => center hotter
    float minDelta = edge * pct;
    if (delta <= -minDelta) out[t] = 1;          // center-hot => over-inflation
    else if (delta >= minDelta) out[t] = -1;     // edges-hot => under-inflation
  }
}
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
void loop() {
  if (firstRun) {
    if (millis() < 2000) {
      // During first 2 seconds, do nothing to keep USB alive
      return;
    }
    firstRun = false;
  }
  int time_delta = timeDelta();
  menuHandler.loop(time_delta);
  serviceModeProfileSnap();
  serviceProfileEditSync();   // #18: Tire Profiles edit buffer follows the selector

  // "Set Offsets" was picked (#23). The action could not close the menu itself, so do it
  // here -- and only note the entry: the mode must not start until applyMenuConfig() below
  // has rebuilt tempReader, or it would be handed a pointer initializeSystem() is about to
  // delete.
  if (consumeOffsetSetupRequest()){
    menuHandler.closeMenu();
    offsetSetupPending = true;
  }

  // "Set Camera Degrees" (#31), same deferral for the same reason.
  if (consumeLensSetupRequest()){
    menuHandler.closeMenu();
    lensSetupPending = true;
  }

  if (!menuHandler.isMenuActive()) {
    if(menuWasActive){
      menuWasActive = false;
      applyMenuConfig();
      if (offsetSetupPending){
        offsetSetupPending = false;
        beginOffsetSetup();
      }
      if (lensSetupPending){
        lensSetupPending = false;
        beginLensSetup();
      }
    }
    if (offsetSetupActive){
      // Offset setup owns the screen and all four swipe directions.
      checkOffsetSetupSwipes();                                 // may end the mode
      if (offsetSetupActive) doOffsetSetupMode(time_delta);
    } else if (lensSetupActive){
      // Lens setup likewise owns the screen and every swipe direction.
      checkLensSetupSwipes();                                   // may end the mode
      if (lensSetupActive) doLensSetupMode(time_delta);
    } else {
      checkForSwipes();
      serviceFeedback();
      if (summaryAutoView){
        // Full-screen sealed summary owns the display; repaint only on page change.
        if (summaryAutoDirty){
          SessionManager::renderSummary(display, sessionManager.summary(), summaryAutoPage);
          summaryAutoDirty = false;
          display.drawScreen();   // F4: edge-triggered, so it must flush its own frame
        }
      } else {
        // drawSessionFeedback() and drawImuGateBar() used to be called here, after
        // doRunningMode() returned -- i.e. after its flush. Once per second the 1 Hz block
        // repaints the tire map, which wipes the badge footprint and the g bar's gutter
        // (ThreeSectionTire's clear rect is inflated by bufferPix on every side), and the
        // flush then pushed a frame with both of them missing. They were re-asserted only
        // on the following pass, after the glass had already updated -- a ~100 ms dropout
        // of the g bar and session badge, every second. They now run inside
        // doRunningMode(), immediately before the flush, so they land in the same frame.
        doRunningMode(time_delta);
      }
    }
  } else {
    menuWasActive = true;
    // Opening the menu takes over the screen: drop any running-mode summary/feedback.
    summaryAutoView = false;
    fbState = FB_NONE;
  }
}

// Cleanup objects to avoid memory leaks
static void cleanupObjects()
{
  if (wheels) {
    delete wheels;
    wheels = nullptr;
  }
  if (tempReader) {
    delete tempReader;
    tempReader = nullptr;
  }
}


// -- Which tire temperature window is actually in force (#27) --
// One resolver, because two callers have to agree: initializeSystem() builds the thermal
// thresholds and the Wheels tire map from this, and sendBootMetadata() reports it. When
// #14 made the profile the single source of truth it had to fix exactly this pair by hand;
// routing both through one function is what keeps NBP honest about what is on screen.
//
// Track always reads the active profile. Street reads the Street window when "Override
// Window" is on, and falls back to the profile when it is off.
//
// ONLY the window moves. K, tau and the camera crop offsets are still read from the active
// profile by both modes -- nothing else carries them -- so Street's "Default Profile" is
// still doing real work even with the override on.
static void resolveTireWindow(float& outMin, float& outIdeal, float& outMax)
{
  const bool street = (getCurrentModeValue() == 0);

  if (street && getStreetWindowEnabled()) {
    outMin   = getStreetMin();
    outIdeal = getStreetIdeal();
    outMax   = getStreetMax();
    return;
  }

  const TireProfile& p = TireProfiles::active();
  outMin   = p.windowMin;
  outIdeal = p.windowIdeal;
  outMax   = p.windowMax;
}

// True when at least one corner is actually reading a thermal camera. Street's default view
// is a camera view, and landing on it with no camera would start the running display on four
// black quadrants -- so the presence of a camera is part of the default, not an afterthought.
static bool anyCameraPresent()
{
  if (!tempReader) return false;
  for (int i = 0; i < TIRE_COUNT; i++)
    if (tempReader->tireSensorIsCamera[i]) return true;
  return false;
}

// -- The view a mode starts in (#32) --
// Which view the running display lands in is a property of what the mode is FOR, so the mode
// picks it rather than leaving you to swipe there by hand after every menu visit:
//
//   Street -- you are looking AT the tires. Show the camera images with the temperatures
//             drawn over the top (the thermalMode 2 overlay view), when there is a camera.
//   Track  -- you are reading the numbers between corners. The tire map alone; the camera
//             images are detail you have no time for at speed.
//
// This only decides where the display STARTS (boot, and every menu close -- the two moments
// initializeSystem() runs). Swipe up/down still moves the view anywhere it could before, and
// that choice stands until the next rebuild.
//
// The overlay view exists only when enableThermalTemps drives all four quadrants from one
// frame set; without it there is no mode that draws temperatures over the images, so Street
// falls back to the all-four-cameras view (3), the closest thing on offer.
static uint8_t defaultThermalMode()
{
  if (getCurrentModeValue() == 1) return 0;      // Track: tire map only
  if (!anyCameraPresent())        return 0;      // nothing to show a camera view with
  return enableThermalTemps ? 2 : 3;             // Street: cameras, temps over the top
}
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

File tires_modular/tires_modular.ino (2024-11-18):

#include <Adafruit_GFX.h>    // Core graphics library
#include <Adafruit_ST7789.h> // Hardware-specific library for ST7789
#include <SPI.h>
#include <Wire.h>

#include "Tire.h"
#include "Wheels.h"
#include "TempReader.h"
#include <SoftwareSerial.h>
#include "NBPProtocol.h"

// Color definitions
#define BLACK 0x0000
#define BLUE 0x001F
#define RED 0xF800
#define GREEN 0x07E0
#define CYAN 0x07FF
#define MAGENTA 0xF81F
#define YELLOW 0xFFE0
#define WHITE 0xFFFF
//#define PURPLE 0xE01F//0xD01F

#define TFT_CS 10
#define TFT_RST 8
#define TFT_DC 7

Adafruit_ST7789 tft = Adafruit_ST7789(TFT_CS, TFT_DC, TFT_RST);

// HC-05 Bluetooth module connected to pins 10 (RX) and 11 (TX)
SoftwareSerial bluetoothSerial(3, 2);
NBPProtocol nbp(bluetoothSerial);
//NBPProtocol nbp(Serial);

long millisSinceLastUpdate = 0;
long updateIntervalMillis = 1000;

// Global object of Wheels
Wheels *wheels;

TempReader *tempReader;

unsigned long previousTime;
long timeDelta()
{
  unsigned long currentTime = millis();
  long delta = (long)(currentTime - previousTime);
  previousTime = currentTime;
  return delta;
}

void setup(void)
{
    Serial.begin(9600);

    bluetoothSerial.begin(9600);
    nbp.sendMetadata("NAME", "Tire Temp Reader");
    nbp.sendMetadata("VERSION", "0.1");

    tft.init(240, 280); // Init ST7789 280x240

    tft.setRotation(1);
    tft.fillScreen(ST77XX_BLACK);
    //wheels = new Wheels(10, ST77XX_WHITE, ST77XX_YELLOW, 100.0, 120.0, 180.0, 'F');
        wheels = new Wheels(10, ST77XX_WHITE, ST77XX_YELLOW, 75.0, 85.0, 100.0, 'F');
    tempReader = new TempReader();

    // drawTires(WHITE, BLUE);
    //wheels->setTireTemps(200, 200, 200, 200);
    wheels->setTireTemps(0, 0, 0, 0);
    wheels->draw(true);

    Wire.begin();
}

void loop()
{
    millisSinceLastUpdate += timeDelta();

    if (millisSinceLastUpdate >= updateIntervalMillis)
    {
       Serial.print("Top of Loop - millisSinceLastUpdate: ");
       Serial.print(millisSinceLastUpdate);
        Serial.print(" > updateIntervalMillis: ");
        Serial.println(updateIntervalMillis);
        millisSinceLastUpdate = 0;

       
        // Get the temperatures for all 4 tires
        // float *temps = GetTemps(70, 220, 180);

        tempReader->readTemps();

        nbp.setTireTemps(tempReader->tireTemps[0], tempReader->tireTemps[1], tempReader->tireTemps[2], tempReader->tireTemps[3], (wheels->getTempUnit()=='F'));

        // Set the temperature for each tire based on the returned values
        wheels->setTireTemps(tempReader->tireTemps[0], tempReader->tireTemps[1], tempReader->tireTemps[2], tempReader->tireTemps[3]);
        wheels->draw();
    }

    // Small delay to control the update rate
    delay(50);
}

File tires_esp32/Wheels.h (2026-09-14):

#ifndef WHEELS_H
#define WHEELS_H

#include "DisplayBase.h"
#include <Adafruit_GFX.h>
#include "Tire.h"
#define PURPLE 0xE01F
#define DARK_GREEN 	0x06A0//0x06E0//0x0680 //0x05E0
#include "ThreeSectionTire.h"

class Wheels {
public:
    char getTempUnit();
    void setTempUnit(char tempUnit);

    // your color/threshold fields…
    int bufferPix;
    uint16_t outlineColor, textColor;
    float minTemp, idealTemp, maxTemp;
    char tempUnit;
    bool fl3=false;
    bool fr3=false;
    bool rl3=false;
    bool rr3=false;

    // helper for setTireTemps
struct TireTemps {
  float values[3];
  size_t count;
  
  TireTemps() = default;             // 1) default‐ctor

  // single‐value constructor
  explicit TireTemps(float v)
    : values{v, 0, 0}, count(1)
  {}

  // three‐value constructor
  explicit TireTemps(const float (&arr)[3])
    : count(3)
  {
    memcpy(values, arr, 3*sizeof(float));
  }
};


    /** 
     * @param bufferPix      spacing between tires 
     * @param outlineColor   rounded‐rect outline color 
     * @param textColor      default text color (unused for three‐section) 
     * @param min/ideal/max  your temperature thresholds in °C 
     * @param tempUnit       'C' or 'F' 
     * @param fl3/fr3/rl3/rr3  true ⇒ use ThreeSectionTire, false ⇒ plain Tire 
     * @param lowTempColor…   optional palette arguments as before 
     */
    Wheels(int bufferPix,
           uint16_t outlineColor,
           uint16_t textColor,
           float minTemp, float idealTemp, float maxTemp,
           char tempUnit,
           bool showSegmentDeltas, byte minInflationDeltaPct, byte minAlignmentDeltaPct,
           bool fl3=false, bool fr3=false, bool rl3=false, bool rr3=false,
           uint16_t lowTempColor    = ST77XX_BLUE,
           uint16_t normalTempColor = DARK_GREEN,
           uint16_t idealTempColor  = PURPLE, //ST77XX_ORANGE,
           uint16_t highTempColor   = ST77XX_WHITE,
           uint16_t lowTempTextColor    = ST77XX_WHITE,
           uint16_t normalTempTextColor = ST77XX_WHITE,
           uint16_t idealTempTextColor  = ST77XX_WHITE,
           uint16_t highTempTextColor   = ST77XX_RED);

    ~Wheels();

    Wheels(Wheels* src, bool fl3, bool fr3, bool rl3, bool rr3);

    // draw all four
    void draw(bool force=false, bool textOnly=false);

    /** 
     * Dispatch 1-or-3 values per tire.  
     * fl, fr, rl, rr may have count==1 or 3. 
     */
    void setTireTemps(const TireTemps &fl,
                      const TireTemps &fr,
                      const TireTemps &rl,
                      const TireTemps &rr);

    bool flIsActive = true;
    bool frIsActive = true;
    bool rlIsActive = true;
    bool rrIsActive = true;

    // Instrumentation accessor (story 08 / issue #9). For a 3-section (camera) corner,
    // fills fill[3]/delta[3] with the per-band RGB565 colors the display computed and
    // returns true; returns false for a single-sensor corner (no bands). Corner order
    // matches the firmware: 0=FL, 1=FR, 2=RL, 3=RR. Uses the fl3/fr3/rl3/rr3 flags to
    // decide the concrete type (no RTTI on this build).
    bool cornerColors(int corner, uint16_t fill[3], uint16_t delta[3]) const;

    // Latched per-corner inflation verdict from the IMU gate (#21): +1 over, -1 under,
    // 0 none. Replaces the instantaneous comparison ThreeSectionTire used to run for
    // itself, so the segment delta bars show the gated, dwelled answer.
    void setInflationVerdict(int corner, int8_t verdict);

    // Raw signed evidence score for the per-corner dwell bar: |score| climbs toward
    // `latch` to trip the verdict and saturates at `max`. Both bounds are passed in
    // rather than assumed so the bar rescales when the Dwell setting changes.
    void setDwellProgress(int corner, long score, long latch, long max);

private:
    // Corner index -> ThreeSectionTire, or nullptr if that corner is single-sensor.
    ThreeSectionTire* cameraCorner(int corner) const;

    Tire *frontLeft, *frontRight, *rearLeft, *rearRight;


    bool showSegmentDeltas;
    byte minInflationDeltaPct;
    byte minAlignmentDeltaPct;
    uint16_t lowTempColor, normalTempColor, idealTempColor, highTempColor;
    uint16_t lowTempTextColor, normalTempTextColor, idealTempTextColor, highTempTextColor;
    //uint16_t *framebuf;     // dynamically allocated areaW×areaH RGB565 buffer
    void RefreshScreen();
};

#endif

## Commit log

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2024-12-07 Fixed crashing and made display use hardware interface for speed.
    [tires_esp32.ino]
2024-12-07 Attempted fixes for i2c
    [TempReader.cpp, tires_esp32.ino]
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2025-01-13 Fixed up Temp sensors to be addressable
    [TempReader.cpp, TempReader.h, tires_esp32.ino]
2025-03-03 Added fixes for loading and saving the EEPROM
    [MenuSystem.cpp, tires_esp32.ino]
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2025-06-07 flipped the mirrored frame
    [TempReader.cpp, TempReader.h]
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2025-06-14 Mostly fixed the text
    [Wheels.h, tires_esp32.ino]
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2025-06-17 Fixed Thermal Gradient Menu functionality
    [tires_esp32.ino]
2025-07-14 Attempts to fix temp display refreshes
    [Wheels.h, tires_esp32.ino]
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2025-07-31 Fixed temp sensor initialization
    [TempReader.cpp, TempReader.h, tires_esp32.ino]
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2025-08-05 Added in Segment deltas to the displays for indication under/overinflation and camber issues
    [Wheels.h, tires_esp32.ino]
2025-09-06 Fixes for temp delta lockout on start. Potential fix for initial impedence issue on startup Fix for thermal mode swipe rollover
    [TempReader.cpp, TempReader.h, tires_esp32.ino]
2025-09-06 Fixed thermal mode color palette
    [ThermalDisplay.h]
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2026-07-23 Add algorithm debug recommendations doc
    Follow-on to the pressure-monitor handoff, written after reading the
    firmware. Revises the handoff's hypothesis ranking:
    - Withdraws two claims that were wrong on a closer read (the crop IS
    applied from EEPROM offsets; band sections split by column, so the
    middle-rows strip runs across the tread as intended).
    - Demotes equal-pixel-thirds and emissivity: getSectionMedians returns a
    median, which is robust to the minority of edge pixels those
    hypotheses depend on.
    - Promotes the missing calibration baseline to primary, and adds lateral
    shoulder cooling as a second pressure-independent pedestal source.
    Reframes the core problem: the indicator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
2026-07-24 Add reproducible VS Code + arduino-cli dev environment for tires_esp32
    The firmware was previously built with the Arduino IDE 2.x on a Windows box,
    and the only committed build config pointed at that machine's absolute paths
    (C:\Users\trvuser\...), a COM7 port, and a sketch folder that no longer exists.
    On a fresh Mac there was no way to build at all. Worse, tires_esp32.ino
    includes "pin_config.h", which was never committed -- it shipped inside
    Waveshare's demo bundle that .gitignore excludes -- so the sketch could not
    compile even with a working toolchain.
    Replace all of it with a committed, machine-independent build definition driven
    by arduino-cli, so `clone && ./scripts/tm.sh flash` wor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
2026-07-24 Switch tracker states to backlog/todo/doing/done/deployed
    Replace the placeholder in-progress/in-review labels with the actual
    five-state label workflow (backlog → todo → doing → done → deployed).
    Map STATE_IN_PROGRESS to `doing` and STATE_IN_REVIEW (PR time) to `done`,
    with `deployed` + issue close as the shipped/terminal state, and update
    the one-time label-creation command to match.
2026-07-24 Track label provisioning per repo
    Add a STATE_LABELS_PROVISIONED flag to the tracker-config block. The
    story skills create the backlog/todo/doing/done/deployed labels on the
    first status change in a repo (stopping for `gh auth login` if needed),
    then flip the flag true so later sessions skip it. An absent flag counts
    as not-provisioned, so repos configured later inherit this automatically.
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2026-07-25 Add story drafts for the tire-temp redesign backlog
    Eight draft user stories (docs/stories/) derived from the functional
    design doc, one markdown file per backlog item plus an index README.
    These are drafts for review, not filed GitHub issues -- the plan is to
    iterate on each and tweak before creating the real issues in
    hydroslide/tires_monitor.
    Each draft follows a consistent template (user story, context, functional
    behavior, menu/settings, acceptance criteria, open questions) and stays at
    the functional level. README carries the slate, a suggested dependency
    order, and the template.
2026-07-25 Gate the redesign to Track mode; note UI/UX latitude
    Cross-cutting constraint: every new feature (session lifecycle, IMU gate,
    calculated mode, tire profiles, balance, demoted verdict) is enabled only
    in the menu's Track mode (currentMode == 1, via getCurrentModeValue());
    Street mode stays unchanged. Distinct from the thermal-display thermalMode.
    Correctness bugs (story 07) apply in all modes; raw logging (08) stays on.
    Also records explicit UI/UX latitude to redesign menu/touch/display and fix
    wonky or buggy behavior found along the way, tracked in the relevant issue.
    Captured in the design doc (new sec 5.0), the stories README, and each
    affected story's acceptance criteria so the unatten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
2026-07-25 [#8] Fix firmware §3.1 correctness bugs
    Address the correctness-bug cluster verified while reading the firmware:
    (a) TempReader::readTemps() now converts all three bands to the working unit
    before any validation, so newTempIsInvalid()'s cross-band rescue compares
    same-unit siblings instead of an already-degF band against degC ones (fixes
    asymmetric band rejection / latched stale values during warm-up).
    (b) Initialize the loop variable tj (was reading stack garbage, risking an
    out-of-bounds negative start).
    (c) Run ThreeSectionTire::initialize() lazily on first draw() via a guard flag,
    since the base Tire ctor cannot dispatch the override (vtable still Tire's);
    seeds the delta/fill color ar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
    [MenuSystem.cpp, NBPProtocol.cpp, TempReader.cpp]
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2026-07-25 [#4] Add surface->carcass calculated display mode
    Add a Track-mode 'calculated' display that estimates carcass temperature from
    the surface camera reading: value = EMA_tau(surface) + K. tau=15s and K=+20F
    (literature defaults; story 04 will source them from the tire profile). When
    active, the smoothed working temps replace the raw surface medians that feed
    every tile, the interim inflation decision, and the NBP active channels, so
    transient corner-frequency spikes no longer flash false in-window colors.
    The untouched raw surface signal is preserved in TempReader::rawSectionTemps and
    logged as a separate NBP channel set ('... Raw' labels) whenever the feature is
    in play (Track mode), so K/ta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
    [NBPProtocol.cpp, TempReader.cpp, TempReader.h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]
2026-07-25 [#5] Add selectable tire profiles (window + K + tau + baselines)
    Bundle the tire-specific calibration into 3 selectable profile slots so
    switching tires swaps the window thresholds, the surface->carcass offset K,
    the smoothing tau, and the per-corner inflation baselines all at once.
    New TireProfiles module holds the 3 slots (seeded ECF / EC02 / Custom),
    the active selection, and its own EEPROM region (base 50) written via
    EEPROM.put so signed baselines round-trip cleanly without the byte-can't-
    store-0 path. In Track mode the sketch now drives the window and the
    calculated-mode K/tau from the active profile; Street mode leaves profiles
    inert (feature gating). Per-corner baselines are expose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
    [MenuRenderer.h, MenuSystem.cpp, TouchMenuHandler.cpp]
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2026-07-25 [#2] Add session lifecycle + end-of-session summary
    Adds a swipe-driven session start/seal and a persisted per-corner summary
    (design 5.3). In Track mode the right-swipe now toggles the session instead
    of Night Mode (Street mode swipe is unchanged); start shows a red recording
    dot for 5s, end shows a black stop square for 5s and then presents the
    summary. Sealing sets running=false so post-seal frames are excluded.
    New SessionManager owns per-corner accumulation (peak, steady average,
    time-in-window, overheat flag/seconds, per-corner first-in-window for
    warm-up) over the calculated working temps, computes the sealed summary,
    persists it to EEPROM (its own region + magic, overwriting the pre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
    [MenuRenderer.h, NBPProtocol.cpp, SessionManager.cpp]
2026-07-25 [#7] Gate & latch the inflation verdict
    Present the over/under inflation verdict as a gated, baseline-corrected, latched
    indicator (design 5.1). It is a Track-mode feature with its own Inflation on/off
    toggle (on by default), persisted to EEPROM byte 49.
    - Verdict is computed from the working (calculated-everywhere) section temps with
    each corner's per-corner baseline subtracted, and only the IMU gate's captured
    (straight-line) frames feed the latch, so it stops giving backwards in-corner
    advice. When the toggle is off or in Street mode a neutral condition is fed so
    nothing latches.
    - A small OVER/UNDER badge is painted over the running display whenever the latch
    is set, visible a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
    [SessionManager.cpp, tires_esp32.ino]
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2026-07-25 [#11] Menu UX: scroll viewport, bottom status strip, name-input nav
    Scrolling menu viewport keeps the selection visible so the new submenu content (IMU Gate, Tire Profiles, Track settings, Display) is reachable, with a subtle right-edge scrollbar on overflow. A reserved bottom status strip renders transient messages (Saved, etc.) instead of overlaying content, and fixes a pre-existing '\0' multi-char-literal clear bug. Name-input LEFT/RIGHT swipes now move between letter positions (were identical); full-left cancels, full-right saves.
    [MenuRenderer.h, TouchMenuHandler.cpp]
2026-07-25 [#11] fix: align name-entry swipes with the menu's confirm/back convention
    The tire-profile name editor had left/right inverted relative to every other
    screen in the menu. Elsewhere a left swipe confirms (select an item, descend a
    submenu) and a right swipe goes back (close a dropdown, pop a level, exit the
    menu) -- but in the name editor a *right* swipe locked the letter and advanced
    while a *left* swipe retreated, so the confirm gesture backed you out and the
    back gesture committed. Muscle memory built anywhere else in the UI did the
    wrong thing here.
    Swap the two gestures so the editor reads the same as the rest of the menu:
    swipe left locks the current letter and moves to the next slot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
    [MenuRenderer.h, TouchMenuHandler.cpp]
2026-07-25 [#2] fix: inset and enlarge the session start/stop indicator
    The swipe-feedback badge was effectively invisible on the hardware. The panel
    has rounded corners, and the old geometry sat hard against the top-right one:
    the r=6 recording dot at (271, 9) had a bounding box reaching x=277 on a
    280-wide panel, and the 13x13 stop square started at y=3. Both were under the
    corner mask, so the user got no confirmation that a swipe had actually started
    or ended a session.
    Pull the badge clear of the corner and make it readable at arm's length:
    - Hoist the geometry into named constants (FB_R, FB_INSET, FB_CX, FB_CY)
    instead of four magic numbers spread across two draw calls, so the clearance
    is a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
    [tires_esp32.ino]
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2026-07-25 [#12] fix: clip over-long menu value/enum labels instead of wrapping
    When a selected enum/string value was too wide for the narrow right-hand
    value column, Adafruit_GFX's default text wrap advanced the cursor to the
    next line and painted the overflow on top of the row below it, garbling
    the menu (e.g. Display -> "Calculated").
    Fix the wrap->overlap failure mode at the source and fit values gracefully:
    - render(): setTextWrap(false) as a guardrail so no menu code path can ever
    wrap a value onto the next row again (also keeps getTextBounds from
    inflating measurements on overflow).
    - drawClipped(): new helper that measures with getTextBounds and, when a
    string exceeds its column, draws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
    [MenuRenderer.h]
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2026-07-25 [#15] feat: move camera pixel offsets into a per-profile "Offsets" submenu
    Camera crop offsets were eight loose globals under "Camera Settings", so every
    tire profile shared one crop. Different tires and mountings want different
    crops, so the offsets belong to the profile.
    - TireProfile gains leftOffset[4] / rightOffset[4] (0..PROFILE_OFFSET_MAX,
    corner order FL, FR, RL, RR); the eight global statics and their bindings are
    gone. seedDefaults() seeds all three slots from one shared set, which also
    gives resetSelectedToDefault() the right behaviour for free.
    - Tire Profiles gains an "Offsets" submenu with the same corner / Left-Right
    shape the global menu had, bound to the g_editProfi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
    [MenuSystem.cpp]
2026-07-26 [#16] feat: allow Calculated display in Street mode, not just Track
    The Raw/Calculated display setting was surfaced only under Track Settings
    and its effect was additionally gated on being in Track mode, so a
    Calculated pick could never apply in Street. Since #14 both modes resolve
    their window and K/tau from the active tire profile, so the calc path has
    everything it needs in Street too and the gate was just an artificial
    restriction.
    - Drop the `&& (modeVal == 1)` gate on configureCalculated(); the Display
    setting alone now decides.
    - Add the existing Display item to streetSettingsMenu. It binds the same
    global byte as the Track item, so it is one shared setting shown in two
    places,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
    [tires_esp32.ino]
2026-07-27 [#17] feat: relabel profile K/tau as "Carcass Offset" / "Carcass Lag"
    "Offset K" and "Tau s" were internal jargon that said nothing about what
    the settings do to the reading. Rename the menu labels only -- the struct
    fields stay offsetK / tauSeconds, and bindings, ranges, defaults, EEPROM
    layout and behavior are all untouched (no magic bump).
    The degree symbol needs care: the built-in 5x7 GFX font is CP437, not
    Unicode, and Adafruit_GFX defaults to _cp437 = false, which applies a
    legacy shift (`if (!_cp437 && (c >= 176)) c++`). That would render the
    degree ring at 0xF8 as the stray dot at 0xF9. Enable tft.cp437(true) once
    after tft.init() so "\xF8" renders literally. Safer than pre-compensa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
    [tires_esp32.ino]
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2026-07-27 [#20] feat: live lateral-g test bar + real straight-line capture dwell
    The IMU capture gate decides whether tire reads count as straight-line data,
    but it had no visible output at all. There was no way to tell while driving
    whether "Lateral cg" was set sensibly, whether the boot orientation calibration
    picked the right axis, or how much noise the dash mount contributes -- so those
    settings were being dialled in blind. This makes the gate legible on the car.
    The bar lives in the 10 px gutter between the tire rows: red flanks outside the
    capture zone, a centre segment sized live from the threshold, and a white dot
    riding on the same smoothed lateralG() the gate itself compares against. That
    l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
    [IMUGate.cpp, MenuSystem.cpp, tires_esp32.ino]
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2026-07-28 [#21] feat: per-tire inflation latch drives the segment delta bars
    The cyan/yellow segment bars were the least trustworthy thing on the display.
    ThreeSectionTire ran its own edge-vs-centre comparison on every draw -- un-gated,
    un-dwelled, un-latched -- so they flickered through every corner with exactly the
    body-roll artifact the IMU gate exists to strip. Meanwhile the gate ran the same
    comparison, collapsed four corners to one majority vote, dwelled it, latched it,
    and put the result in a badge nobody could act on because it never said which
    tire. A third copy of the comparison lived in the instrumentation block. Three
    implementations, and the wrong one was on screen.
    Now there is one. com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
    [IMUGate.cpp, SessionManager.cpp, Wheels.h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]
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2026-07-28 [#23] feat: set the camera crop offsets from the live thermal view
    The eight per-corner crop offsets are a pixel aim against a camera image,
    but the only way to set one was a numeric field two levels down in Tire
    Profiles -> Offsets -> Front Left -> Left -- a screen that hides the very
    image being aimed. Every value was entered blind, checked by backing all
    the way out of the menu, and corrected by going back in. Eight times.
    Add a "Set Offsets" action at the top of that Offsets menu. It closes the
    menu and hands the screen to the four live camera images with their crop
    guides drawn on top and no tire map. Exactly one guide is armed and blinks;
    left/right slides THAT line the way you swiped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
    [ThermalDisplay.h, TouchMenuHandler.cpp]
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2026-07-30 [#25] fix: debounce session swipe and clean up the recording blink
    The touch layer often reports one physical swipe twice, so starting a
    session immediately ended it, and the swipe that dismisses the summary
    could bleed into starting a new one. Lock out the session-toggle swipe
    for 1 s (SWIPE_LOCK_MS) after any start/end and after dismissing the
    summary; up/down thermal-mode switching is unaffected.
    Also fix the recording indicator: FB_START drew a red circle on the lit
    half but filled a full square on the dark half, so the tire-map corners
    flickered black in step with the dot -- reading as a circle AND a square
    blinking together. Each state now clears only its own footprint: the dot
    pulses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
    [tires_esp32.ino]
2026-07-31 [#27] feat: Street mode gets its own tire temp window, overriding the profile
    #14 made the tire profile the single source of truth for the temperature window
    in both modes. That was right for Track and over-generalised for Street.
    A track window is part of what you are tuning, so it belongs with the tire. A
    street window is not a tuning target -- it is a fixed "are these anywhere near
    warm" scale, and it has to stay put while you swap between profiles that are all
    tuned for track heat. Pinning it to a profile left only bad options: edit a
    profile's window and wreck it for track use, or keep a decoy "street" profile
    whose K/tau/crop you did not actually want.
    Street Settings therefore regai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
    [MenuSystem.cpp, tires_esp32.ino]
2026-07-31 [#28] fix: complete DisplayBase and defer the canvas allocation
    Three defects in the merged-in display abstraction, all of which would have
    produced silent, hard-to-diagnose failures on the buffered path.
    1. DisplayBase was missing five methods dev calls
    --------------------------------------------------
    drawRect, drawFastHLine, fillCircle, setTextWrap and cp437 were never declared,
    because the abstraction was written in March against a tree that did not yet have
    the session summary, the IMU gate bar or the offset-setup mode. Added to all
    three implementations.
    drawRect is the worst of them: it is the ONLY draw in the entire offset-setup
    border, so that mode would have been a black screen.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
    [BufferedDisplay.cpp, tires_esp32.ino]
2026-07-31 [#28] refactor: route every draw through DisplayBase
    Nothing outside the display abstraction may hold an Adafruit_ST7789& any more.
    On the buffered path such a reference paints straight to the glass and is wiped
    by the next drawScreen(), so it presents as a region that flickers at 10 Hz or
    never appears at all -- with no compile error.
    These are the components main never saw: they were written after 9089b0a and so
    were never converted. Between them they own most of what is on screen outside the
    tire map.
    ImuGateBar drawImuGateBar(), paintBarSpan() -- the lateral-g gutter bar
    OffsetSetup service(), paintBorder() -- the confirm border
    SessionManager renderSummary(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
    [MenuRenderer.h, QuadrantFactory.h, SessionManager.cpp]
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2026-07-31 [#28] fix: restore the autoRecoverTire assignment lost in the merge
    The merge silently took main's deletion of `tempReader->autoRecoverTire = true;`.
    main could delete it because 9089b0a also gave the member a `= true` initialiser
    in TempReader.h -- but that header hunk was deliberately rejected during conflict
    resolution, to keep the sketch the single source of truth for TempReader config
    the way every neighbouring line is.
    Rejecting one half of a two-part change and letting git auto-merge the other left
    autoRecoverTire an uninitialised bool: read in TempReader.cpp:340, never written.
    Auto-recovery of a wedged tire sensor would have been decided by whatever was on
    the heap.
    Caught by the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
    [tires_esp32.ino]
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2026-08-05 [#31] feat: correct the camera's fisheye distortion at capture
    The wide-angle MLX90640 is a ~110 degree lens, so straight lines bow: a tire
    renders as an oval and its circumferential grooves arc like longitude lines on a
    globe. That is not only a looks problem. getSectionMedians() slices the frame
    into three FIXED-WIDTH column bands, and fixed columns are equal slices of TIRE
    only if the projection is linear across the width -- it is not, so the
    outer-vs-inner comparison behind the camber and inflation verdicts has been
    reading bands that do not match the physical thirds of the tread. No amount of
    crop-offset aiming can fix that: aiming moves where the bands sit, it cannot make
    equal pixel w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
    [MenuSystem.cpp, TempReader.cpp, TempReader.h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]
2026-08-12 [#32] fix: the mode picks which view the main screen starts in
    Street and Track want different things on screen the moment the display comes
    up. Street is a look-at-the-tires mode: the camera images with each tire's
    temperatures drawn over the top. Track is a read-the-numbers mode: the tire map
    alone, because the images are detail you have no time for at speed.
    initializeSystem() -- the one function that runs at boot AND on every menu
    close -- never read Current Mode to pick a view, so thermalMode stayed at its
    initial 0 and both modes always came up on the tire map. Street had to be
    swiped back into the camera view by hand after every single menu visit.
    Resolve the starting view from the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
    [tires_esp32.ino]
2026-08-12 [#32] fix: re-resolve the default view once sensor detection settles
    The "if a camera is fitted" half of the mode default could never fire, so
    Street's camera view was unconditional -- on a board with no cameras it would
    sit there showing four black quadrants, which is exactly the case the condition
    existed to prevent.
    initializeSystem() rebuilds tempReader a few lines before it picks the view, and
    a fresh TempReader claims all four corners are cameras: resetTireSensor() seeds
    tireSensorIsCamera[] true and only checkTireSensor() -- running on the read
    cadence, once the loop is going -- finds out otherwise. So anyCameraPresent()
    was reading a placeholder, always returned true, and did nothin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
    [tires_esp32.ino]
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2026-09-14 [#36] fix(nbp): one UPDATEALL per cycle with every channel; colors as integers
    TrackAddict builds its channel list from the first ALL/UPDATEALL packet
    it receives after connecting, and the NBP spec defines UPDATEALL as the
    complete channel set. The firmware sent four different UPDATEALL packets
    in rotation -- active temps, raw temps, instrumentation, IMU -- so which
    channels a session logged was a race: the 2026-07-28 Thompson logs got
    the raw temps in one session and delta/threshold/verdict in the others,
    never the canonical temps the RaceRender template binds. Same firmware
    all day.
    NBPProtocol now keeps a registry of every channel it has been given, in
    first-seen order, and publish() wri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
    [NBPProtocol.cpp, tires_esp32.ino]
